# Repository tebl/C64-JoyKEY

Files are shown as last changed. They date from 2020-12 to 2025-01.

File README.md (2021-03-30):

# C64 JoyKEY
The *C64 JoyKEY* was born out of the desire to build my own joystick, and after having a look at the various options available I chose to build one using Cherry MX keyboard switches. They are around a dollar per piece, so after getting it all to work properly on my beloved Commodore 64 I looked into using it with a whole selection of vintage computer systems as well. There are two main versions of the *C64 JoyKEY*, the keyboard-variant already described and a board designed for use with Sanwa arcade parts instead.

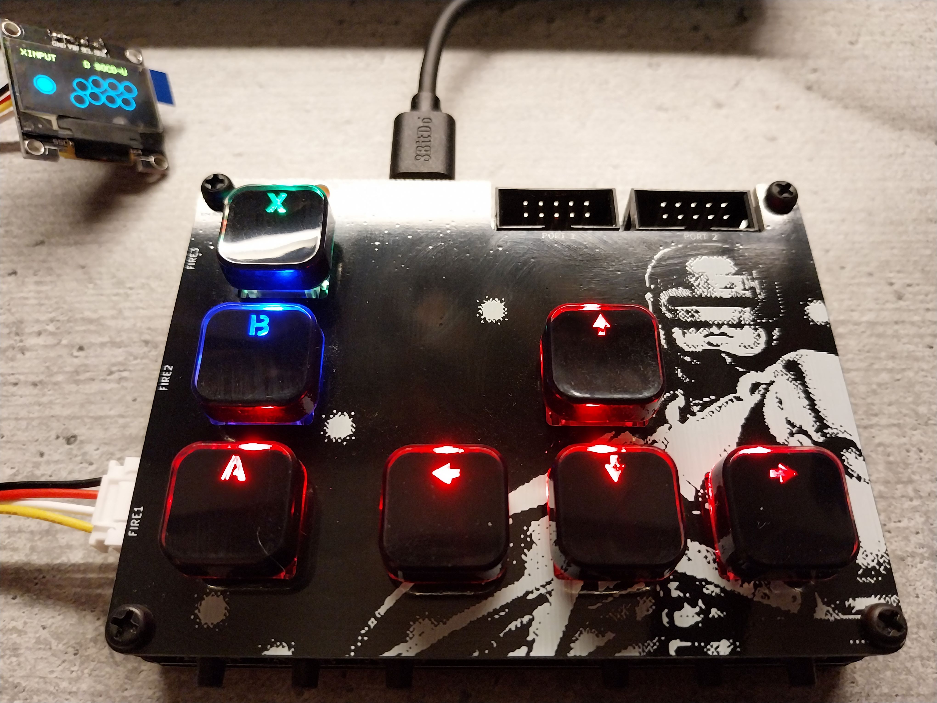
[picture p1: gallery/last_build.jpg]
Last build

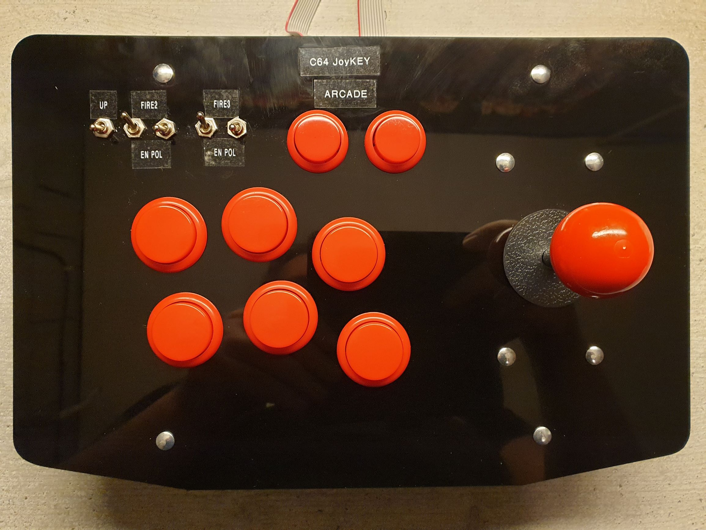
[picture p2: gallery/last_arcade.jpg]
Last arcade


With options to handle multiple types of systems comes complexity, you'll have to make a few decisions on what you want out of the *C64 JoyKEY*. Do I only want to use it as a joystick replacement on vintage systems, ideally with 2-3 fire buttons where supported? If so, then you won't need the Arduino Pro Micro.

Want to use it on a modern system as a *WASD*-style keyboard or a gamepad, then install it - a common use of these types of devices is as a macro-keyboard or a stream-deck. Note that compared to many similar solutions, the microcontroller is not required for use with any of the vintage systems - the adapters actually follow the original circuit descriptions for controllers used with the actual vintage computers. What that means is that there is truly no chance of lag added by the controller. Ever.

The pictures below show the unit when connected to my Commodore 64, including the jumper settings used with it. As I've tried to keep things as close to the standard usually associated with Atari-style joysticks, there are two joystick connectors - this is because a lot of the Commodore 64 games supported using a second joystick for specific game functions.

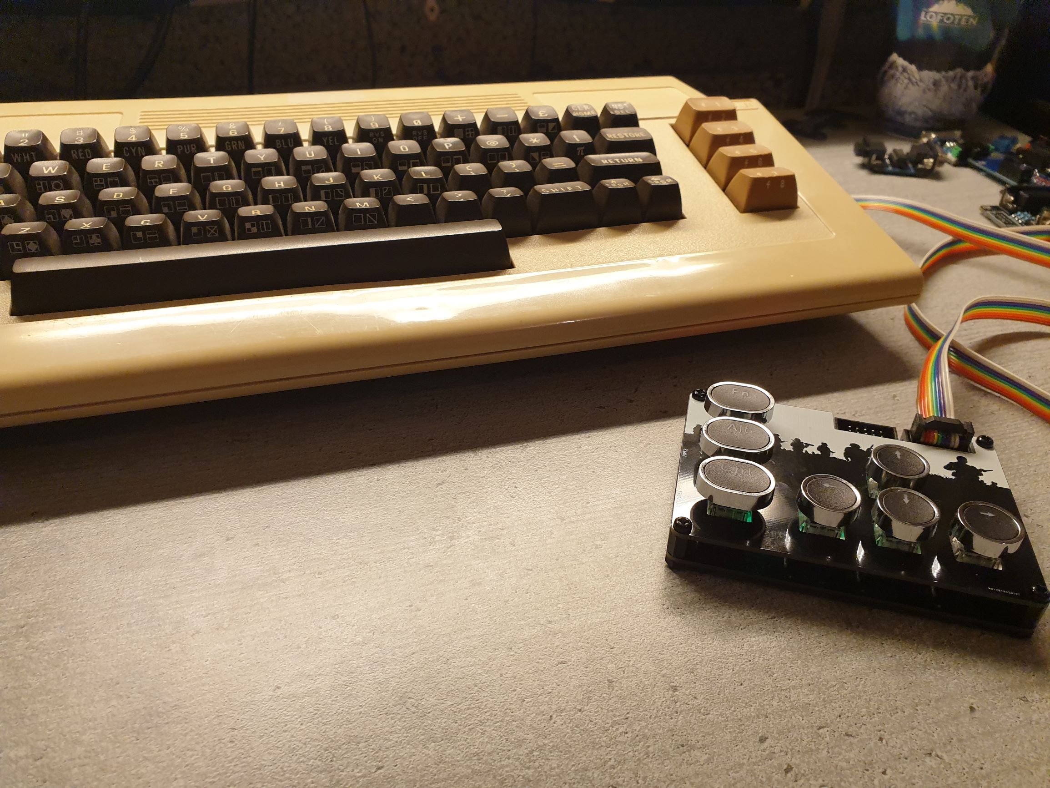
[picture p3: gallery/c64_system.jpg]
Commodore 64

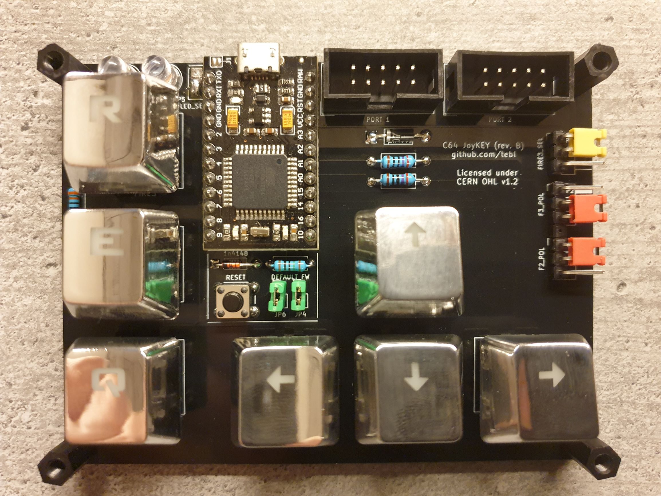
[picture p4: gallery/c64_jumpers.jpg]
C64 Configuration


As with most C64 games port 2 is the one to use, port 1 is just there to connect additional fire buttons. When in doubt, just connect a cable for port 2 and you should have a good time. This was labelled after the way the controller is used on the Commodore 64. 

## Getting one
I won't be selling these, so if you want one you will probably have to build it yourself (or call your favourite friend, ideally someone with a reasonable quality soldering iron). I've created a separate documents on [building](https://github.com/tebl/C64-JoyKEY/blob/main/documentation/building.md) a *C64 JoyKEY*, this is also where you'll find the [BOM](https://github.com/tebl/C64-JoyKEY/blob/main/documentation/building.md#bom) for this project (a list of needed parts and links to where PCBs can be ordered).

* [Building C64 JoyKEY](https://github.com/tebl/C64-JoyKEY/blob/main/documentation/building.md)
* [Building C64 JoyKEY Arcade](https://github.com/tebl/C64-JoyKEY/blob/main/documentation/building_arcade.md)
* [PCBWay shared projects](https://www.pcbway.com/project/shareproject/?tag=C64%20JoyKEY)

As with all things you're soldering together by yourself, the one who soldered it takes responsibility for it. I'll try answer any opened tickets as far as I am able, but know that this is a hobby-grade project and I might be busy on spending the little energy I have on other things (be patient, check out the [schematic](https://github.com/tebl/C64-JoyKEY/tree/main/documentation/schematic) while you wait).

## Setting it up
The *C64 JoyKEY* has a handful of jumpers that need to be set correctly in order to: A - function, B - not destroy your precious vintage computer and/or consoles. The necessary details have been put into a separate [configuration](https://github.com/tebl/C64-JoyKEY/blob/main/documentation/configuration.md)-document, check it out for some information on the systems I've attempted to use the *C64 JoyKEY* with.

* [Configuring C64 JoyKEY](https://github.com/tebl/C64-JoyKEY/blob/main/documentation/configuration.md)
* [Arduino firmware](https://github.com/tebl/C64-JoyKEY/blob/main/documentation/firmware.md)

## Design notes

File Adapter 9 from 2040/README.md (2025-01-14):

# Adapter 9 from 2040
I cant really recall the entire list of adapters that I've made of the years, but there might actually have been a few more than 9 though this is definitely the first one that I've ended up calling *Adapter 9 from 2040*. Strikingly similar in function to the [C64 Joystick Adapter](https://github.com/tebl/C64-Joystick-Adapter) that I made a while back, but given my renewed interest in the *C64 JoyKEY* via [C64 JoyKEY 2040](https://github.com/tebl/C64-JoyKEY/tree/main/C64%20Joykey%202040) it made somewhat sense to create yet another "DB-9" to USB-controller adapter.

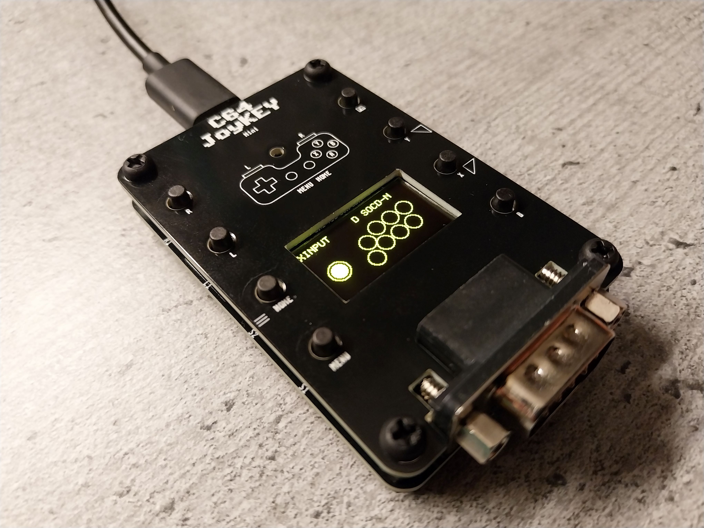
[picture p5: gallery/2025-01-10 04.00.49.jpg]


Except this time the implementation was based on [GP2040-CE](https://gp2040-ce.info), running on a Raspberry Pi Pico variant commonly referred to as the *RP2040-Zero*. At this point quite a lot of the older Arduino-libraries have hardly seen any features added to it, but as for *GP2040-CE* - if there's a feature that you can think of, then it's probably already there in some form or another. *Adapter 9 from 2040* in its most common setup presents itself to the system you connect it to as a wired *Xbox-360 Controller*, meaning that you can use it as a controller on quite a lot of different systems.

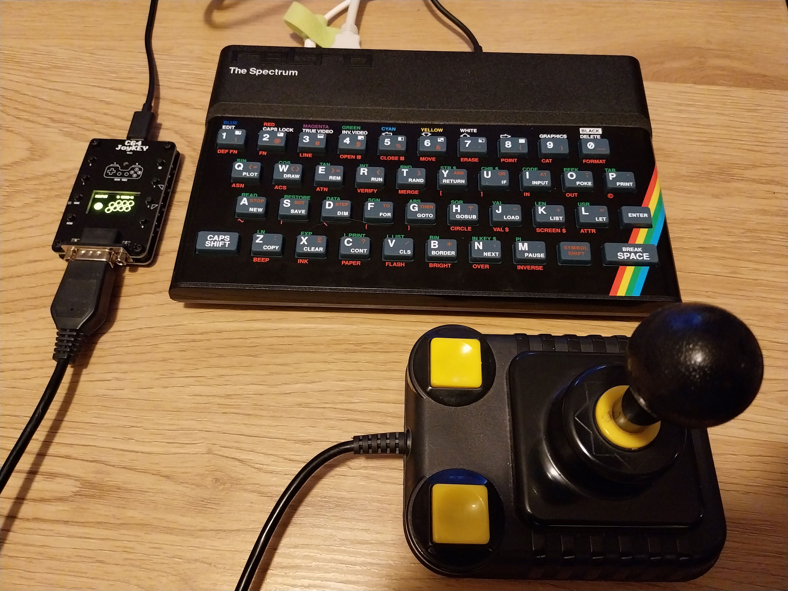
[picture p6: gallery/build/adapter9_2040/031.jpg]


Personally I wanted it for use with the various releases from *Retro Games Ltd.* - great little systems for playing games on when I want something that should just work, but absolutely terrible controllers. I've tested it with *TheC64 Mini*, *TheA500 Mini* and most recently *TheSpectrum* to great effect, and being able to use my vintage joysticks with them only adds to the enjoyment.

- [1> Building the device](#1-building-the-device)
- [2> Schematic](#2-schematic)
- [3> BOM](#3-bom)

# 1> Building the device
Building the device should be a straight-forward affair, you just solder the meager selection of components into place. Pay particular attention to keeping the alignment of parts somewhat straight, that's pretty much it. This documentation was written with a board that looks like the following in mind, but note that the GitHub-repository might contain changes that have yet to be tested. For that reason it is recommended that PCBs are ordered directly from the PCBWay links provided in the BOM).

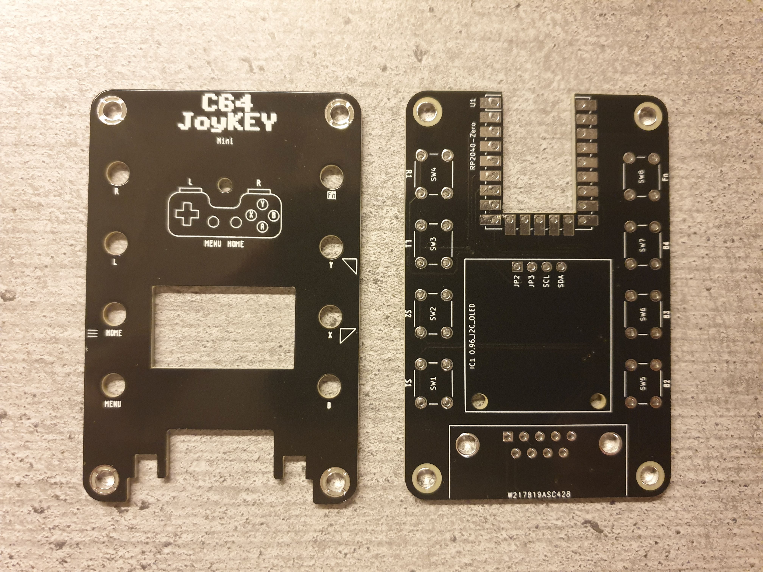
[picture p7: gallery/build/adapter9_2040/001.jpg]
Bare boards

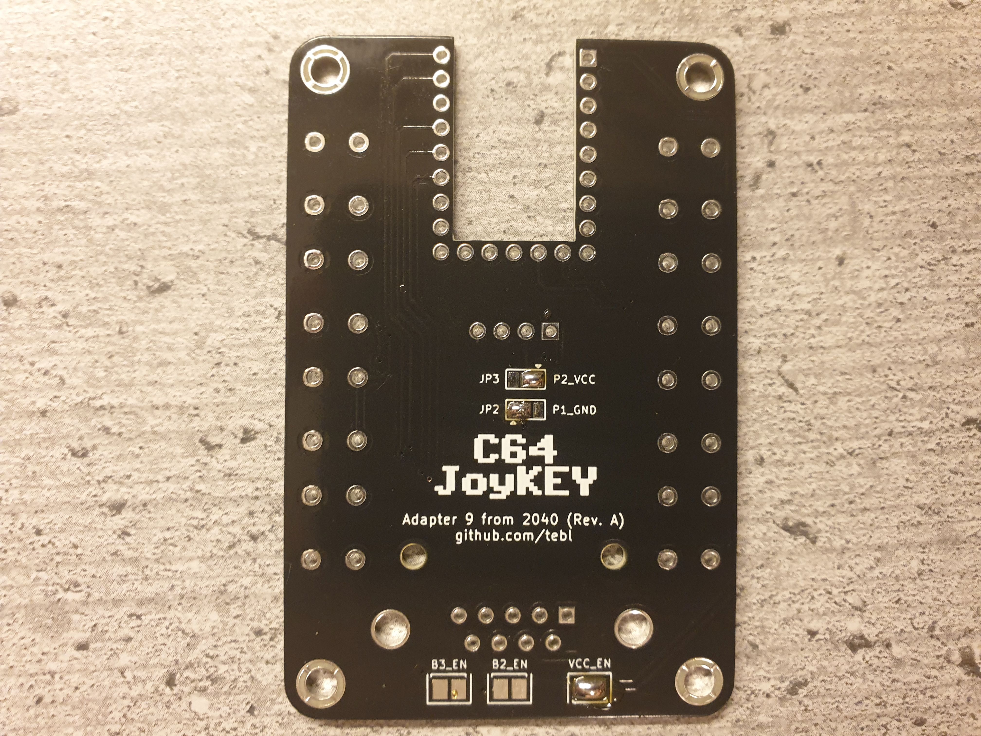
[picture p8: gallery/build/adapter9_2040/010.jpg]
Build 010


Before getting started on installing actual components there are a few things that we need to cover first, and that's setting up the various jumpers found on the back of the PCB. The ones towards the bottom covers the kind of signals we want to hook up to the "DB-9"-connector, and the only one that I recommend linking is *VCC_EN* as that will be needed for quite a few of the joysticks that include a turbo-function. Takes a little bit of practice to get these to link, but if you try and get the soldering iron to heat both pads simultaniously and keep feeding in solder you'll get a perfect blob before long.

The jumpers for *B2_EN* and *B3_EN* are for controllers that have one or two extra fire buttons with a commoned ground, but as these are quite rare I'd recommend that you leave these as they are unless you specifically know what you're doing. Or in the even rarer case, is the one where you're using either [C64 Arcade](https://github.com/tebl/C64-JoyKEY/tree/main/C64%20Arcade), [C64 JoyKEY](https://github.com/tebl/C64-JoyKEY/tree/main/C64%20Joykey) or the [C64 JoyKEY 2040](https://github.com/tebl/C64-JoyKEY/tree/main/C64%20Joykey%202040).

The one case where we really need to pay attention is the ones toward the middle of the PCB, these are needed in order to specify how your *0.96" I2C OLED*-display should be wired up. The reason is that when you're ordering these from various sources they'll send you displays that were made with differing pinouts, even more annoyingly is that often you'll look at the pictures to verify that you're getting a specific revision of it - but they'll just send you a different one. Here's what the one I've jumpered for in the above picture, note specifically that *GND* is on the first pin. That means that on both jumpers we need to link pins 1-2 together (with the tiny triangle indicating pin 1). If, on the other hand, the first pin had been labelled *VCC* (or quite possibly *VDD*) the you'd instead need to link pins 2-3 for both of the jumpers. 

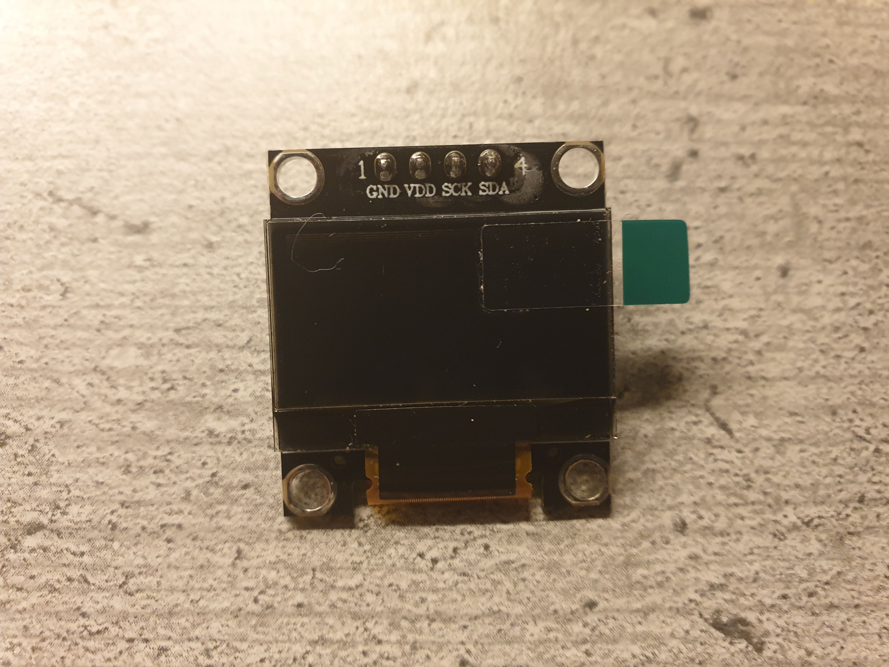
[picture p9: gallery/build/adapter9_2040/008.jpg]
Build 008

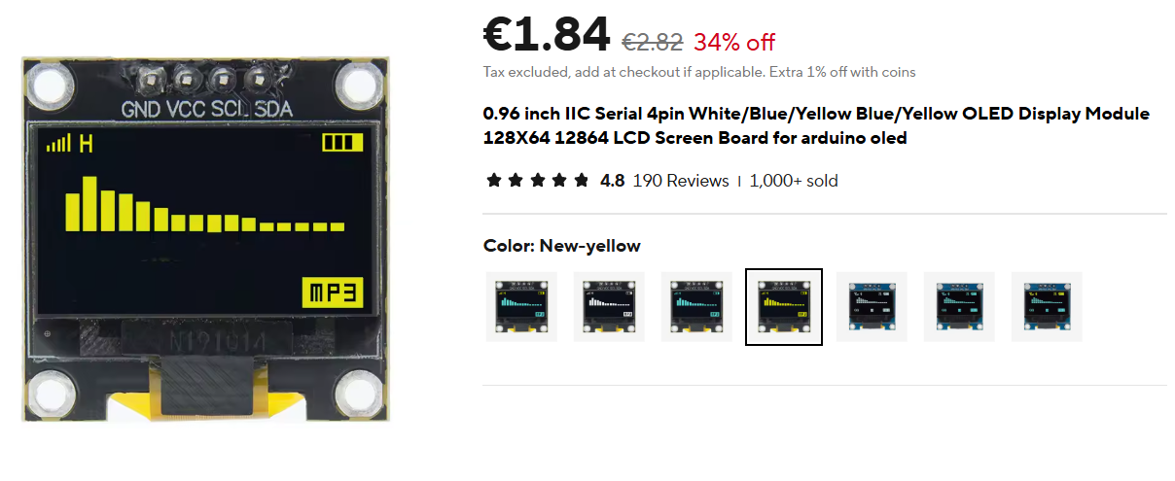
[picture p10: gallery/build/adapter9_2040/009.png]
Build 009


Moving on to actualy components that we'll be installing, I always recommend that you install things in the order of their physical height. There's not all that much that can go wrong beyond making things harder for yourself to put this one together so don't overthink things. You will however need to decide if you'll be installing the *RP2040-Zero* development board directly to the board, or with pins between the two. Before all that though, we need to talk about what a *RP2040-Zero* actually is. And here's a couple of them that you might encounter while shopping around: 

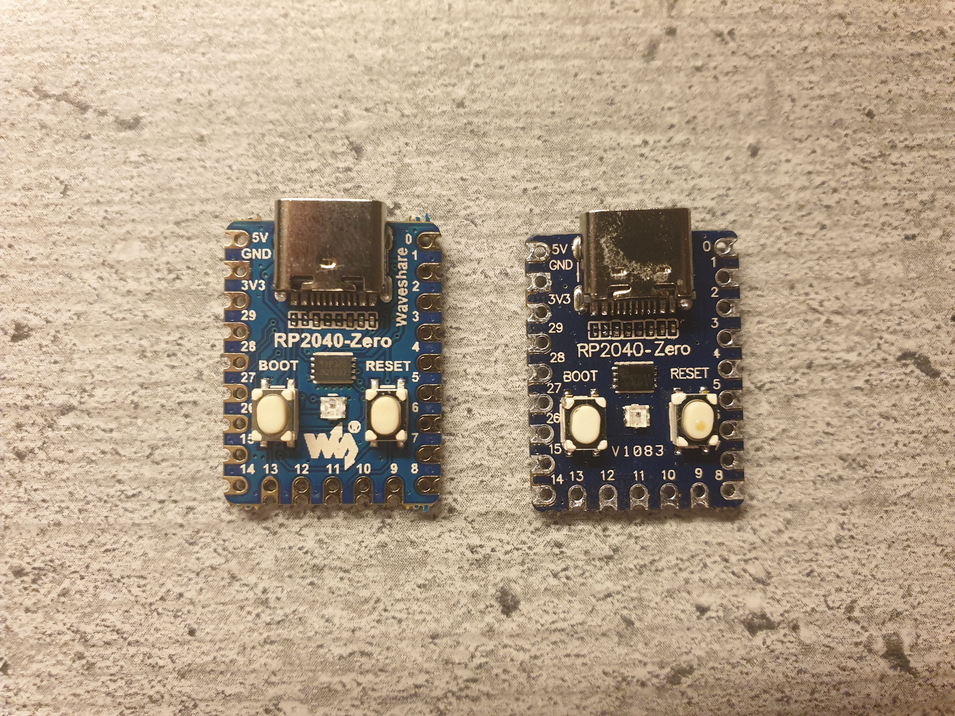
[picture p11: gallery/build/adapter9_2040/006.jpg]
RP2040-Zero development boards


Both of these are smaller versions of the *Raspberry Pi Pico* boards that come directly from the *Raspberry Pi Foundation*, but they're running the same chip so you essentially get the same amount of computational power - just with slightly less pins, and in a significantly smaller package. Confusingly this isn't a *Raspberry Pi* as the single-board computers (*SBC*) that came before it, this is a somewhat new line of microcontrollers similar to the *Arduino* or *ESP-32*. As for the boards above, the first one is from a vendor called *Waveshare* and this is the version that you'll encounter on more reputed sites for purchasing electrical components. The other is a clone that normally works just as well, just at half the price and without any expectation that all of were put together like they should - so buy at least two of them in case one blows up!

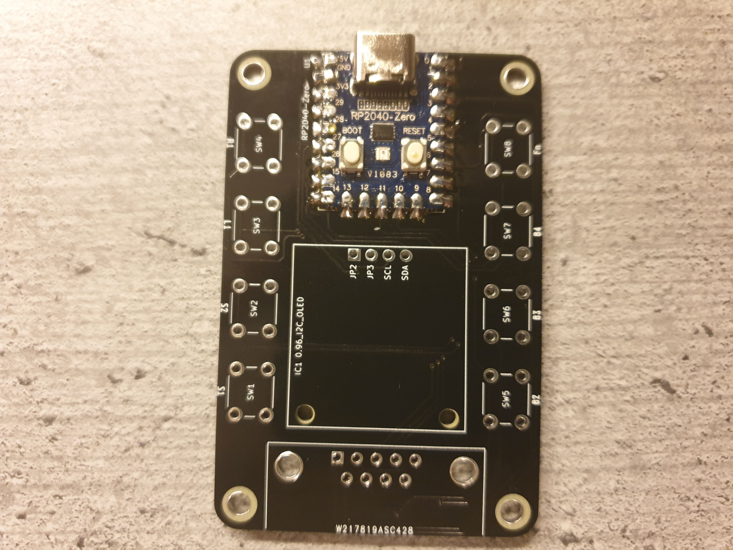
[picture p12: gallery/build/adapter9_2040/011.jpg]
Build 011


Here I've skipped over the difficult parts and soldered it into place. In order to get the alignment just right I tend to insert pin headers through both boards on at least two of the sides, then position it just right and solder one pin into place. If it all looks right, you can go ahead and remove the pin headers before soldering the rest. It might take some getting used to soldering things together like this if you're not used to it, but just try and get the soldering iron to touch both pads at the same time then feed in the solder until it forms a shiny avalanche.

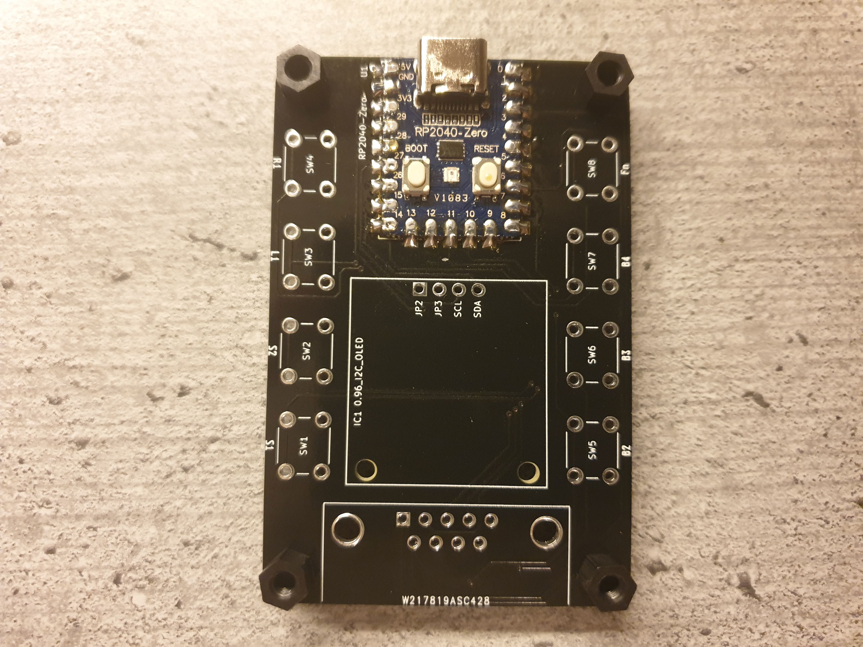
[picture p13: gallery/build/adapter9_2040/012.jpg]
Build 012


If you're going to install a faceplate on the adapter, then you're going to need a set of standoffs in each of the four corners. These need to have a height of 6mm, they're fixed in place with similar nuts on the underside. You might also use some that are slightly longer, but keep in mind that we need to have enough of a reach on the pin headers on your OLED to match - switches also need to be tall enough to poke through all of it. On second thought, just go with 6mm and we'll move on from there.

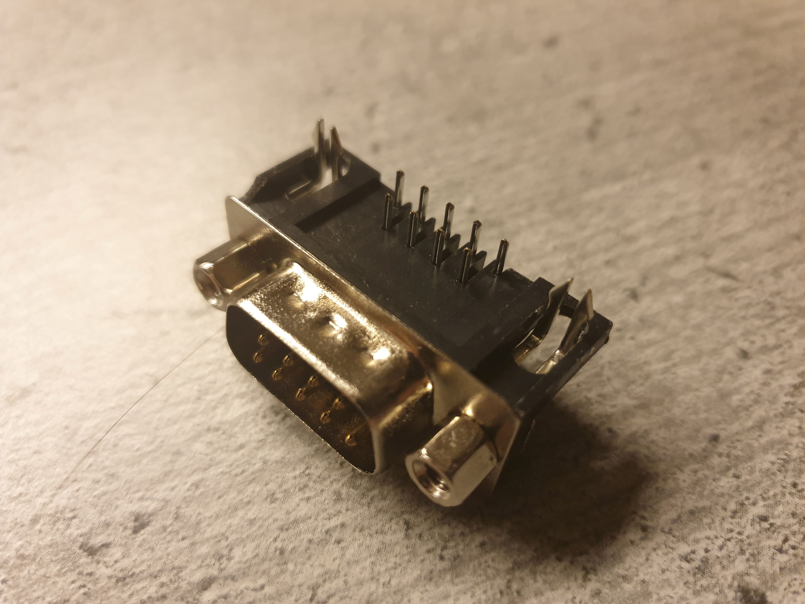
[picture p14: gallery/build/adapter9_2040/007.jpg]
Build 007

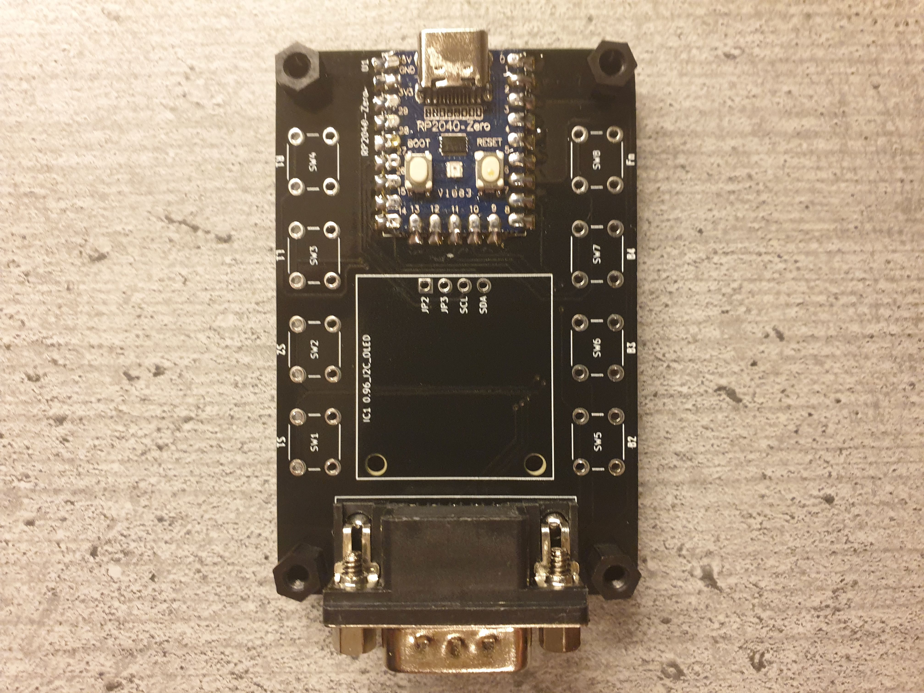
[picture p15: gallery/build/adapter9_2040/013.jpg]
Build 013


Next up is the *right-angle "DB-9" male connector* that I keep buying off of the regular sites, and I believe it's a clone of an RND-part, but don't hold me to that. If you look for the a connector that looks like this on the pictures, then you'll get the correct one. It snaps into place on the board and solders in well enough, just keep your fingers away from the metal as it heats up quite quickly when soldering. I've literally burned myself on them several times. And at the time of writing, this is probably the first time I've used the word "literally" correctly. I hope. 

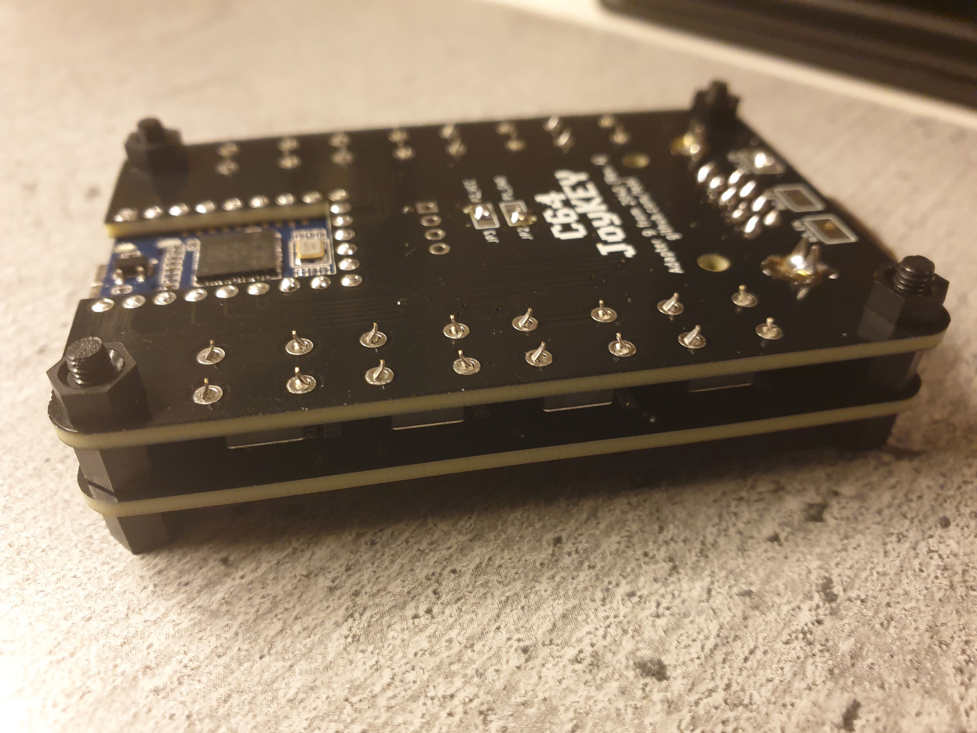
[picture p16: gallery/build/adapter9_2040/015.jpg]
Build 015

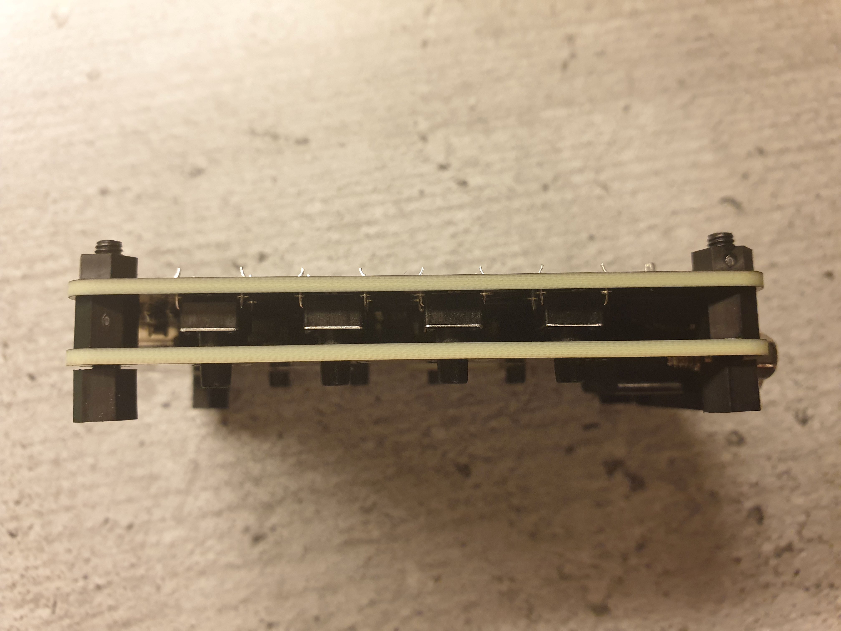
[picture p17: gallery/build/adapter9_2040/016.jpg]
Build 016


The next step is all of the switches, and here I've inserted them all into place and temporarily installed the faceplate. Doing it in this order ensures that the switch ends up sitting correctly, and won't be rubbing too much against the cutouts in the faceplate. Once satisfied with all of that, you can go ahead and solder in the switches. Just do one of the pins at first, then recheck to make sure it hasn't popped out or gone wonky on you in the meantime (ask me how I know).

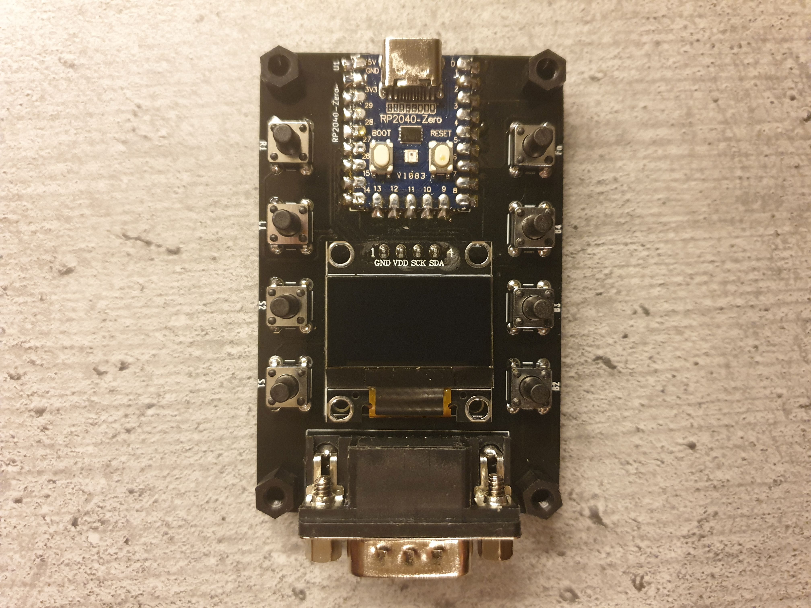
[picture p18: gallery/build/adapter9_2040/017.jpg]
Build 017


As for my next trick on my list of things I've just done without much to actually show you, I've gone ahead and added the display. Previously on this episode of putting things together with our fiery stick of endless ouchies (also known as a soldering iron), we lamented the state lack of real part numbers for things like displays. Clones taking liberties when shamelessly copying other clones, enabling people like me to actually own a whole bunch of them and so on. The board will take just about any *0.96" I2C OLED*-display, but you'll need to ensure that you order specific ones if you want the cutouts on the faceplates to line up just perfectly. Currently there is only one available, [FaceplateB](https://github.com/tebl/C64-JoyKEY/tree/main/faceplates/Adapter%209%20FaceplateB) - this one was designed for the *New* displays available in all the usual places. Technically it's actually the new *New* display, but who's counting - at least one identifying trait is that they're the first generation that came with yellow as colour.

There are holes for orienting it correctly, but before even considering soldering anything - take a look at how it looks with the faceplate in place. We need to ensure that it sits flush against the inside edge of the faceplate, and while you could glue the foam that often comes around the pins directly to the PCB to push it upwards - I prefer adding a bunch of layers of double-sided foam tape. Just don't go overboard -  we want it to push the glass up against the PCB, not shatter the whole thing from extreme pressure. If you need to reorient it a bit, you can poke a screwdriver into the mounting holes from the back and adjust it that way. Once satisfied with your rough placement, solder a single pin. Recheck. Recheck. Recheck. And then solder the rest.

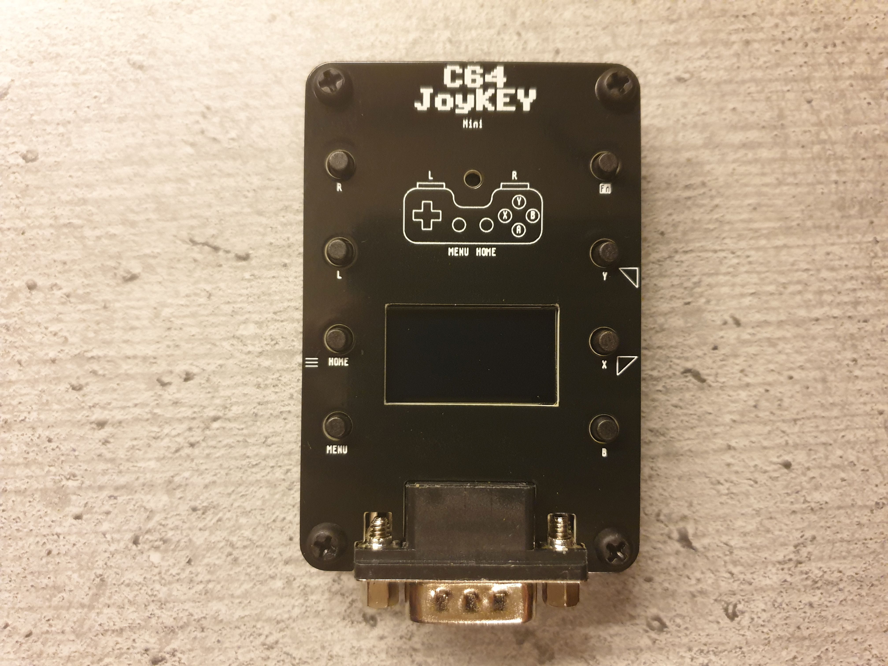
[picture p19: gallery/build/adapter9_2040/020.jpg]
Build 020


Once satisfied with all of it, make yourself a cup of tea, soup or whatever you want - you're buying anyway! Once back to the table, you need to take the faceplate back off again, as we need access to the buttons directly on the *RP2040-Zero* when installing *GP2040-CE*, but that's all covered in a completely different document - [From Zero to GP2040](https://github.com/tebl/C64-JoyKEY/blob/main/documentation/gp2040_zero.md).

# 2> Schematic
The supplied KiCad files should be sufficient as both a schematic and as a  starting point for ordering PCBs (basically you could just zip the contents of the export folder and upload that on a fabrication site), the schematic is also available in [PDF-format](https://github.com/tebl/C64-JoyKEY/tree/main/documentation/schematic) and this is what you'll need to print and work your way through when things fail to work as expected.

# 3> BOM
Most parts should be easy to get a hold of from all of the regular places, just not any of the incredibly reputable ones. Which is why things usually cost a third of what they cost elsewhere, but you need to buy two in order to ensure that at least one works. I get most of my components from AliExpress though I hear nice things about the wheel of fortune thingie, but they sent one too many notifications so they're banned in my household.

I'd really like for you to have a nice and clear BOM with consistent part numbers from actual reputable sites, but I can't even afford their shipping options so it is what it is - mostly hints at what to search for and how many you need. If a counted part is listed in a parenthesis, then you don't strictly need that part though it's all cheap enough that you probably count on buying them anyway.

| Reference | Item | Count | Order  |
| ---| --- | ----- | --- |
| PCB | Fabricate using Gerber files | 1 | [PCBWay](https://www.pcbway.com/project/shareproject/Adapter_9_from_2040_578739f8.html)
| PCB (Faceplate B)| Fabricate using Gerber files | (1)| [PCBWay](https://www.pcbway.com/project/shareproject/Adapter_9_from_2040_Faceplate_B_dc748e4f.html)
| IC1 * | 0.96" I2C OLED display 128x64 (New variant reqd. for FaceplateB)) | (1)|
| J1 | Male DB-9 right-angle connector (usually listed as PCB-mount) | 1 |
| SW1-SW8 | 6x6x10mm tactile switch ("DIP-4") | (8)|
| U1 | Raspberry Pi Pico (RP2040-Zero) | 1 |
| ** | M3 nylon nut | (4)|
| ** | M3x6+6mm nylon hex standoff | (4)|
| ** | M3x6mm nylon screw | (4)|

*) See text for construction for hints on purchasing the correct variant to go with a specific faceplate, when in doubt order several and use the one that fits.

**) These components are for the additional faceplate. Strictly not necessary, but keeps the  whole setup looking as stylish as it can be. The faceplate is reversible, so install it in the orientation that you'd like.

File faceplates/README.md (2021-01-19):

# Faceplates
The *C64 JoyKEY* will have a selection of faceplates, these are primarily just here to make the device a bit prettier by hiding the actual electronics. Secondly it adds some rigidity to the design, quite possibly making it less likely to fail after heavy use.

These generally come in two different variations, A and B with a number added to separate the various designs. The A version has a larger PCB cutout that should allow you to use most of Cherry MX-compatible keycaps of the kind that descends down past the actual switch (low/medium profile), if you're in doubt this is the version to get. The B designs have a smaller cutout, but requires the use of keycaps that don't descend so far down (high profile).

See the [faceplates](https://github.com/tebl/C64-JoyKEY/blob/main/documentation/faceplates.md) section of documentation for more information.

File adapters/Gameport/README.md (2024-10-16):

# Gameport

*UNTESTED*

While the IBM PC has seen its fair share of joysticks over time, they were primarily analog though the digital variety have also been regularly seen since the early 1980s as well. The rise of competing gaming consoles soon started to popularize the gamepads over the analog controllers and soon, even the PC saw their share of excellent controllers such as the Gravis Gamepad. While they won't replace the feel and response of an analog flightstick for those type of games, I feel that there are enough variety that the digital controllers also should have their place on the system - for that system I've created a separate Gameport-adapter for the *C64 JoyKEY*. Granted it won't make all that much sense connecting a keyboard-like controller to a computer with a great keyboard, but the ability to use the *C64 JoyKEY Arcade* with it should present as an excellent combination.

The circuit was adapted from the one listed on [asun.net](http://www.asun.net/joystick/joystick.html). Additional information was also listed in a separate [article](https://allpinouts.org/pinouts/connectors/input_device/joystick-pc-gameport/) as well, and could be interesting when working out how the adapter works.

PC Gameport Adapter
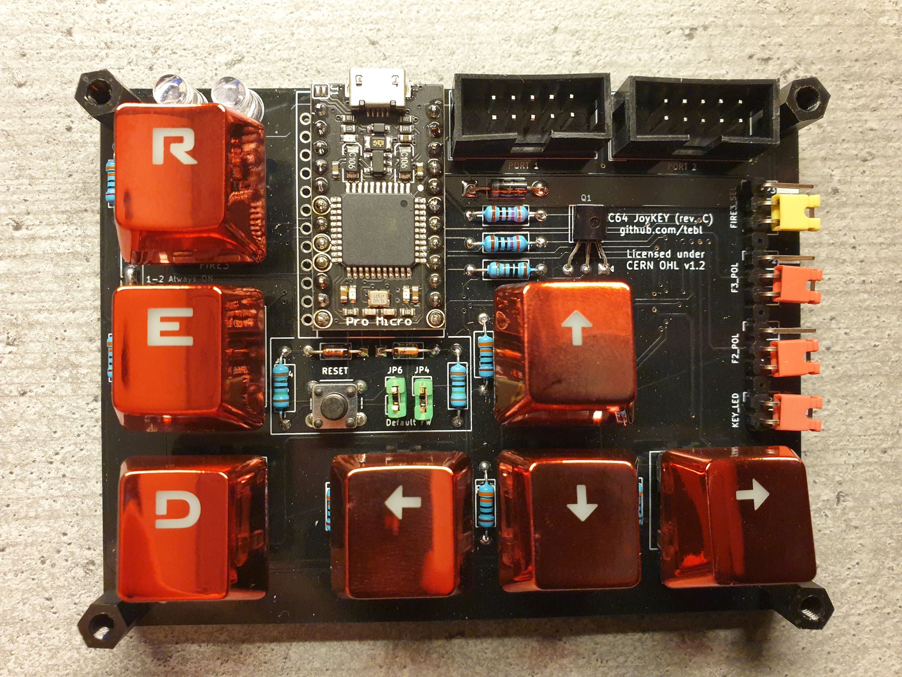
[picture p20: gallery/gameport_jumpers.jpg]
PC Gameport Jumpers


# BOM
The parts listed are the ones I've used when building a MSX adapter for use with the *C64 JoyKEY*, part listed in parenthesis are considered optional (meaning you could build a more limited version of it). 

| Reference | Item | Count | Order |
| --- | --- | ----- | --- |
| PCB | Fabricate using Gerber files | (1)| PCBway
| D1,D2 | 1n4148 small-signal diode (DO-35) | 2 |
| J1,J2 *1 | 2x5 pin straight header pins or 2x5 IDC | 2 |
| J3 *2 | 2x8 pin straight header pins or 2x8 IDC | 1 |
| Q1,Q2 *3 | 2n3906 transistor (TO-92) | 2 |
| R5,R6 | 47k ohm resistor | 2 |
| R1-R4,R7,R8 | 100k ohm resistor | 6 |

1) Breakable dual row pin headers can be used here, but I find it is nicer to have a proper 2x5-pin keyed connector here instead. The cable you will need is a 2x5 pin IDC cable (usually listed as *AVR* or *JTAG* cable), with sufficient length to position where you would like - ideally you will want two of these, but you can make due with one connected to port 1.
2) As with above, 2x8-pin IDC header is recommended. For the cable you will want a 16-pin IDC to a male DB15-ribbon cable - you can buy these ready made from the usual sources. If you can't find one that you like, I recommend picking up 16-pin IDC cables of intended length and then put on a male IDC DB15-connector. While there are special tools created to crimp these on, I find that just pushing hard on them with the handle of a screwdriver works just as well for a single cable.
3) I have not tested this, but I suspect that replacing these with 2n3906 installed backwards may work just as well.

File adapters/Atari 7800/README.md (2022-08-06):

# JoyKEY (Atari 7800)

In the age of the Commmodore 64, Atari decided that it was a good idea to put together a console without audio quality that would only rise to the level of competing with the almighty ZX Spectrum. Then they launched them with horrible controllers that fell part on the way home from the store. Here in Europe, we also got treated to a gamepad-like controller that can only be described as an implement created by someone who only have had the concept just barely described to them over the phone - yet, we still got the feeling that that someone did not see the point of spending more than 5 minutes on games.

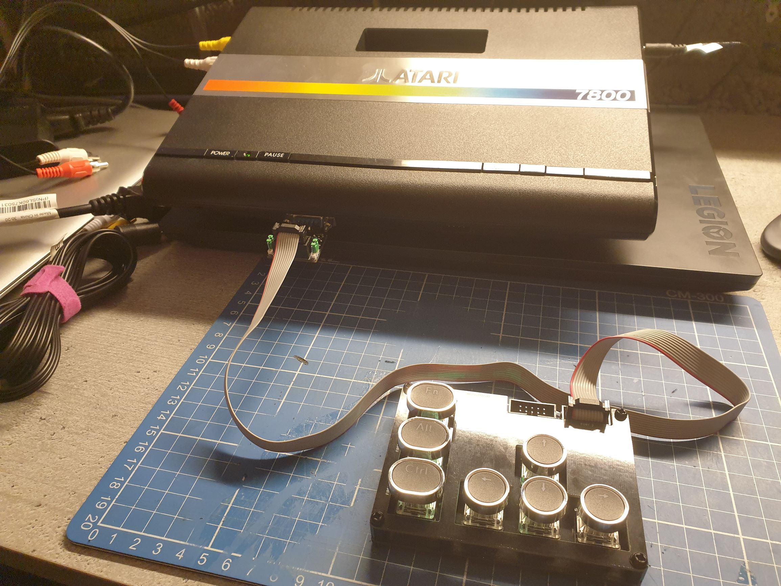
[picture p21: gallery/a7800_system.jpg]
Atari 7800 Pro System


Enough about all that, I actually have more than one of the consoles - somehow I sort of like playing on them, I just can't use any of their controllers. I've previously made an adapter so that I can use Sega Mega Drive controllers with the console, but since I've built the *C64 JoyKEY* I wanted to use it on that as well (which is the reason for this adapter).

The completed adapter can be seen below, this also includes the expected position that should be set on the *C64 JoyKEY* device itself.

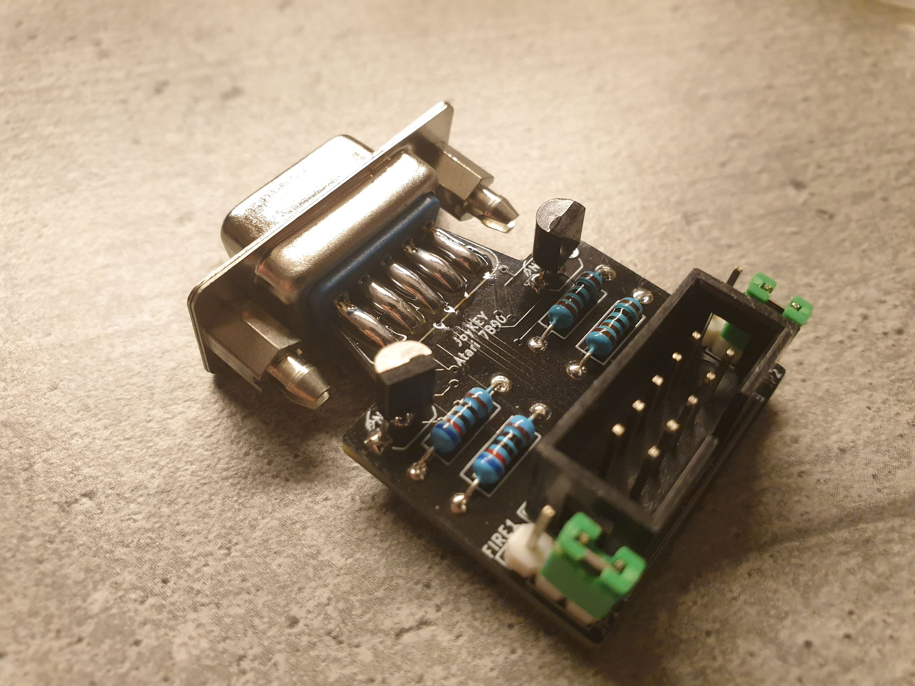
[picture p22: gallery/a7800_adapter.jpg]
Atari 7800 Adapter

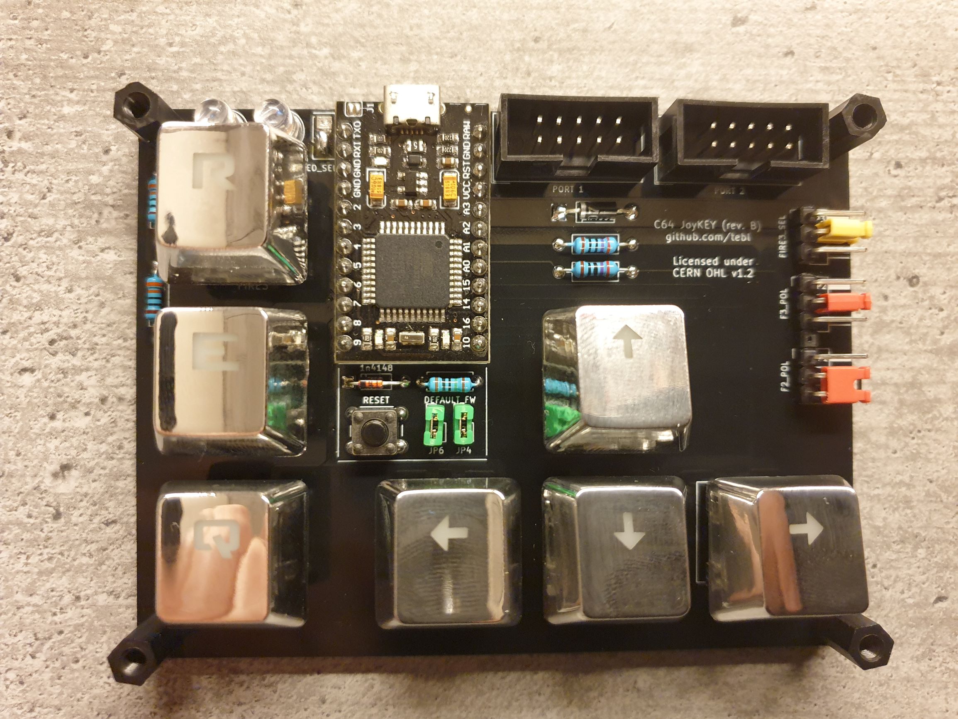
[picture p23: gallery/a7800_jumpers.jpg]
Atari 7800 Jumpers


# BOM
The parts listed are the ones I've used when building an Atari 7800 controller adapter for the *C64 JoyKEY*, part listed in parenthesis are considered optional (meaning you could build a more limited version of it). 

| Reference | Item | Count | Order |
| --- | --- | ----- | --- |
| PCB | Fabricate using Gerber files | (1)| [PCBway](https://www.pcbway.com/project/shareproject/C64_JoyKEY__Atari_7800_adapter_.html)
| J1 * | 2x5 pin straight header pins or 2x5 IDC | 1 |
| J2 ** | DE-9 Female straight connector | 1 |
| JP1,JP2 *** | 3-pin breakable header pins (w/jumpers | (2)|
| Q1,Q2 | 2N3906 transistor (TO-92) | 2 |
| R1,R3 | 620 ohm resistor | 2 |
| R2,R4 | 1k ohm resistor | 2 |

*) Breakable dual row pin headers can be used here, but I find it is nicer to use a 2x5 pin connector here instead. The cable needed is a 2x5 pin IDC cable (usually listed as *AVR* or *JTAG* cable) with sufficient length.

**) These are the blue kind with straight pins, it will include a few metal bits on it - remove those and you'll be left with the mostly blue part needed. Bend the pins slightly and match up with PCB, solder before it has a chance to fall off.

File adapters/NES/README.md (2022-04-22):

# JoyKEY (Nintendo Entertainment System)
The Nintendo Entertainment System, commonly known as just the *NES* came with a four button controller (*B*, *A*, *SELECT* and *START*). A picture of the completed adapter has been included below, including the jumper position that you need to use on the *C64 JoyKEY* device itself.  For the later revisions of the *C64 JoyKEY* you'll have a row of buttons on the bottom left of the device, these are ideal for using as the  *SELECT* and *START* - for earlier revisions you'd install a physical *START*-button on the adapter itself.

Making the adapter requires a cable with the right shape, Nintendo wanted these to be explicitly proprietary so you can't exactly order one from electronic parts vendors though obtaining one isn't exactly hard. The simplest way of obtaining the plug today is either cutting up cheap NES controller extension cable, alternatively you could just purchase one of the rather horrible cloned controllers and cut it off from that instead. Both of these options should be readily available from your favourite off-brand marketplace for all things "*Made in China*", AliExpress, Ebay, Wish and most similar sites.

With the cut-off cable in hand, the individual strands of the cable can then be soldered to the adapter PCB. The pins are numbered left to right, match up the individual strands to the pin numbering as shown in the [schematic](https://github.com/tebl/C64-JoyKEY/blob/main/documentation/schematic/adapters/NES.pdf). Ideally I'd like to just tell you where to connect them based on the colour, but with the cost of these things I wouldn't expect them to be identical across all of them - so just use your multimeter in order to identify what goes where on the connector.

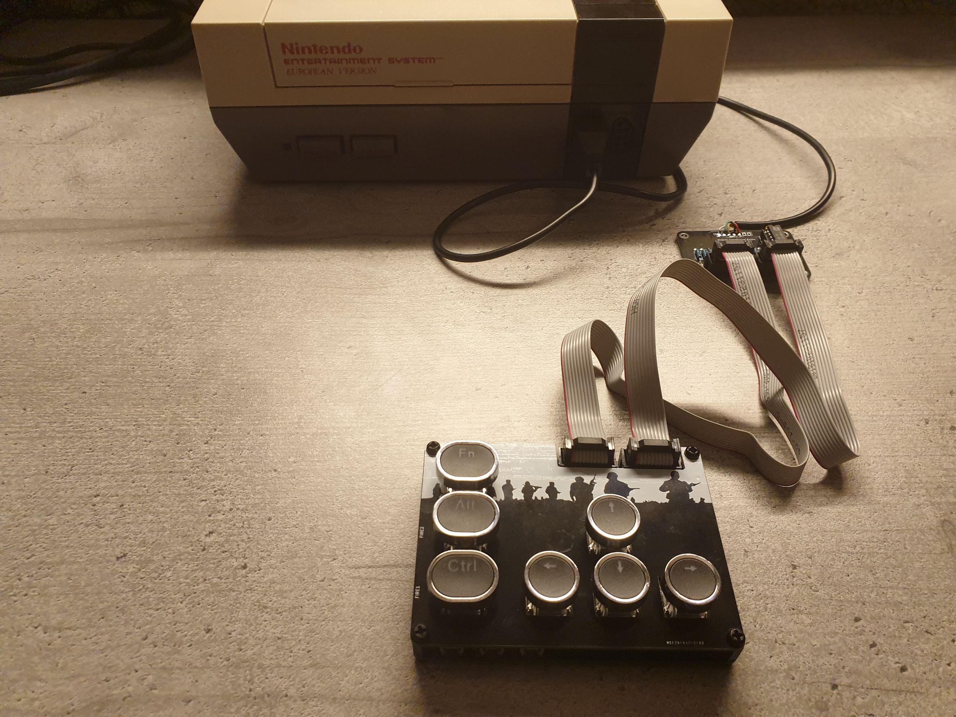
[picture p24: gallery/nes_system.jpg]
Nintendo Entertainment System

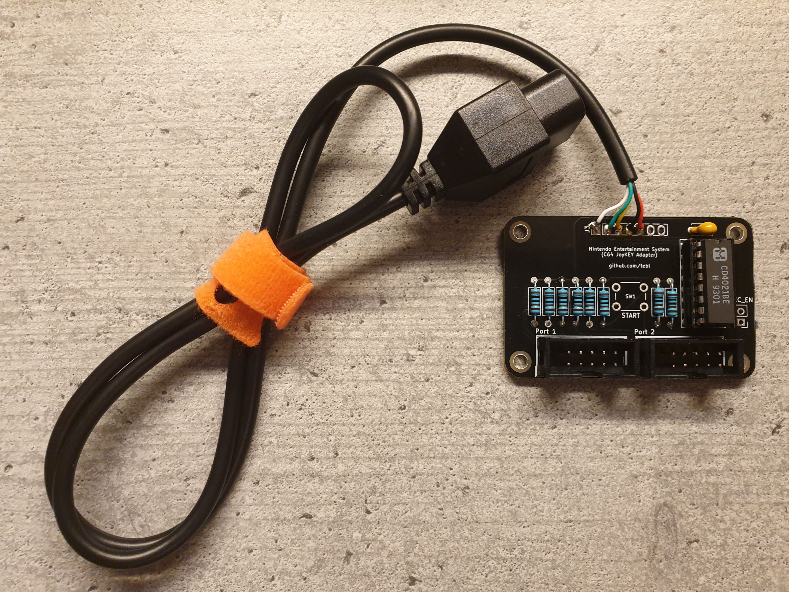
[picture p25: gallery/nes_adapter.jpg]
Nintendo Entertainment System Adapter

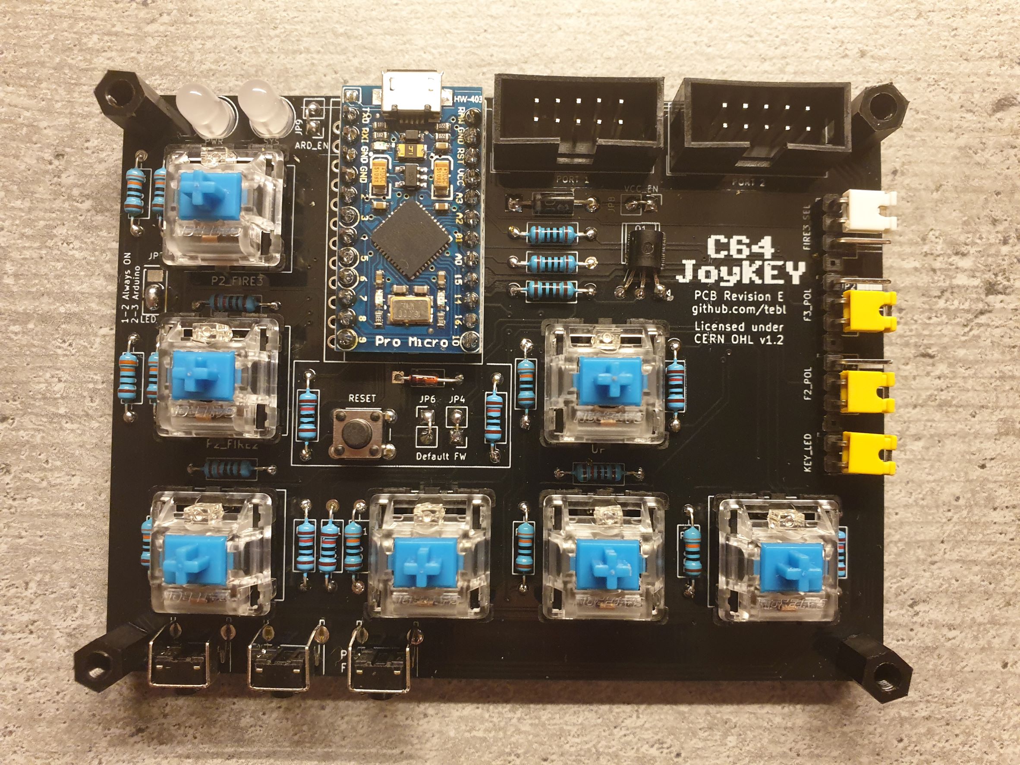
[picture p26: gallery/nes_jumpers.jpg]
Nintendo Entertainment System Jumpers


# BOM
The parts listed are the ones I've used when building a Nintendo Entertainment System controller adapter for the *C64 JoyKEY*, part listed in parenthesis are considered optional (meaning you could build a more limited version of it).

| Reference | Item | Count | Order  |
| --- | --- | ----- | --- |
| PCB | Fabricate using Gerber files | 1 | [PCBWay](https://www.pcbway.com/project/shareproject/C64_JoyKEY_NES_adapter_74ada4a5.html)
| J1,J2 * | 2x5 pin straight header pins or 2x5 IDC | 2 |
| J3 | Male end of NES extension cable | 1 |
| JP1 | 2-pin breakable header pins (w/jumpers) | (1)|
| R1-R8 | 1k ohm resistor | 9 | 
| SW1 ** | 6x6mm momentary tactile switch | (1)|
| U1 | CD4021BE (DIP-16) | 1 |

*) Breakable dual row pin headers can be used here, but I find it is nicer to use a 2x5 pin connector here instead. The cable needed is a 2x5 pin IDC cable (usually listed as *AVR* or *JTAG* cable) with sufficient length, these are used with all adapters.

**) This switch is only required using an earlier revision of the *C64 JoyKEY*, the three extra switches were added in revision E.

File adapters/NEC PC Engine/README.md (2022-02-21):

# JoyKEY (NEC PC Engine)

**UNTESTED**

The NEC PC Engine, primarily found in the japanese markets as well as everywhere fans of the shoot em up genre could be found, had several revisions and third party controllers though most stuck with the regular four button configuration (*I*, *II*, *RUN* and *SELECT*). A picture of the completed adapter has been included below, including the jumpers needed on the *C64 JoyKEY* device itself. Making on requires a cable with the right shape, the simplest way of obtaining these is either cutting up a cheap extension cables.

NEC PC Engine System
NEC PC Engine Adapter
NEC PC Engine Jumpers

# BOM
The parts listed are the ones I've used when building a Nintendo Entertainment System controller adapter for the *C64 JoyKEY*, part listed in parenthesis are considered optional (meaning you could build a more limited version of it).

| Reference | Item | Count | Order  |
| --- | --- | ----- | --- |
| PCB | Fabricate using Gerber files | 1 | PCBway
| C1 | 100nF ceramic capacitor (5mm) | 1 |
| C3 | 10uF electrolytic capacitor 16v (4x2mm) | 1 |
| J1,J2 * | 2x5 pin straight header pins or 2x5 IDC | 2 |
| J3 | 8 pin mini DIN with cable | 1 |
| JP1 | 2-pin breakable header pins (w/jumpers) | (1)|
| R1-R10 | 47k ohm resistor | 10 | 
| R11-R14 | 330 ohm resistor | 4 | 
| U1 | 74HC157 (DIP-16) | 1 |

*) Breakable dual row pin headers can be used here, but I find it is nicer to use a 2x5 pin connector here instead. The cable needed is a 2x5 pin IDC cable (usually listed as *AVR* or *JTAG* cable) with sufficient length, these are used with all adapters.

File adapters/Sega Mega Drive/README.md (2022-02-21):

# JoyKEY (Sega Mega Drive)

The Sega Mega Drive, released as the Sega Genesis in North America, originally came with a what is now known as the 3-button controller though it actually had the *START* button as a fourth button as well. While it was designed to be backwards compatible with the Sega Master System, it had a few tricks up its sleeve by adding a digital multiplexer chip that would read out the buttons over a few wires instead of having dedicated wires for each button (like previous Atari-style pinouts). There was also a 6-button controller released later, but for now I've chosen to instead focus on the 3-button controller instead - simply because we only have 3 buttons on the *C64 JoyKEY* (the *START* button has been placed on the actual adapter instead).

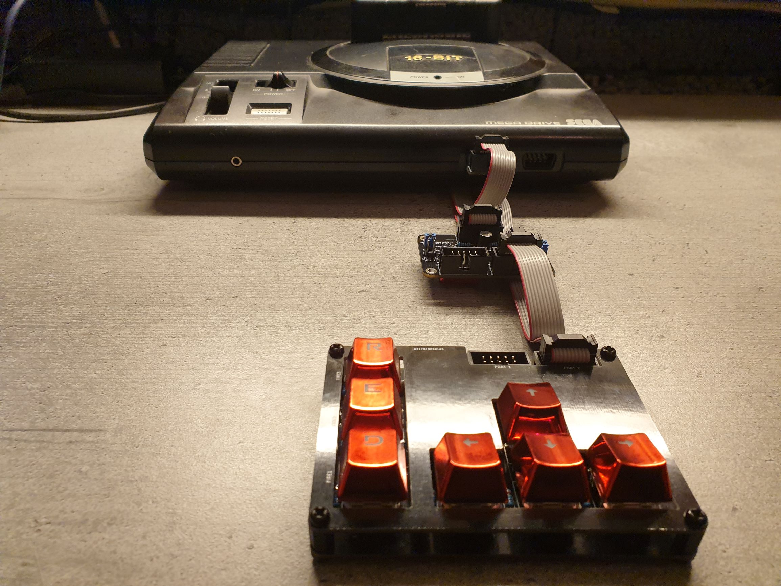
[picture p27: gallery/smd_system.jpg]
Sega Mega Drive


The completed adapter can be seen below, this also includes the jumpers that should be set on the *C64 JoyKEY* device itself. Note that because of the recessed controller ports on the actual console, a larger connector such as the DB9 IDC variety will not fit into the console - I've solved that by using a straight [IDC to DB9](https://github.com/tebl/C64-JoyKEY/tree/main/adapters/IDC%20to%20DB9) adapter as well.

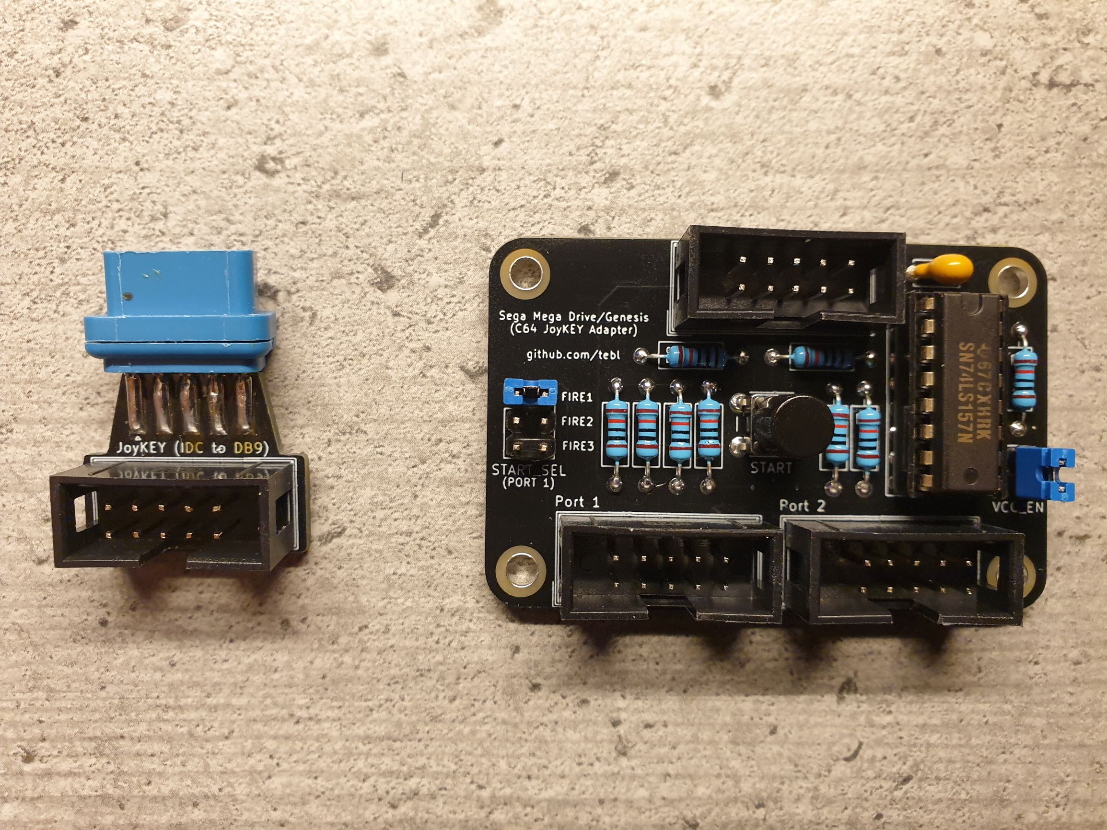
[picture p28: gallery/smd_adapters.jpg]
Sega Mega Drive Adapter

Sega Mega Drive Jumpers

# BOM
The parts listed are the ones I've used when building a Sega Mega Drive controller adapter for the *C64 JoyKEY*, part listed in parenthesis are considered optional (meaning you could build a more limited version of it). Additionally, check out the BOM on the [IDC to DB9](https://github.com/tebl/C64-JoyKEY/tree/main/adapters/IDC%20to%20DB9) page - if you don't already have on of these ready to go.

| Reference | Item | Count | Order  |
| --- | --- | ----- | --- |
| PCB | Fabricate using Gerber files | (1)| [PCBway](https://www.pcbway.com/project/shareproject/C64_JoyKEY__Sega_Mega_Drive_Genesis_adapter_.html)
| C1 | 100nF ceramic capacitor (5mm) | 1 |
| J1 * | 2x5 pin straight header pins or 2x5 IDC | (1)|
| J2,J3 * | 2x5 pin straight header pins or 2x5 IDC | 2 |
| J4 | 3-pin dual row breakable pin headers | (1)|
| JP1 | 2-pin breakable header pins (w/jumpers) | (1)|
| R1-R9 | 10k ohm resistor | 9 | 
| SW1 | 6x6mm momentary tactile switch | 1 |

*) Breakable dual row pin headers can be used here, but I find it is nicer to use a 2x5 pin connector here instead. The cable needed is a 2x5 pin IDC cable (usually listed as *AVR* or *JTAG* cable) with sufficient length.

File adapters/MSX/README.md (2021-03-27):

# JoyKEY (MSX)

**UNTESTED**

The MSX-line of computers generally tried to be everything for everyone, as long as they wanted an 8bit computers. This meant a lot of different features going into it, including the surprisingly complicated joystick ports - designed to fit just about any device as long as it conformed to their very specific standard. Which means that it works with the standard Atari-style joystick, but if you want a second fire button or something that'd work reliable for joysticks requiring power you'll need an adapter in between. I was tempted to make this a more general adapter, but I couldn't point you to a specific joystick that'd work with it - unless you build it yourself, of course.

MSX System Adapter
MSX System Jumpers

# BOM
The parts listed are the ones I've used when building a MSX adapter for use with the *C64 JoyKEY*, part listed in parenthesis are considered optional (meaning you could build a more limited version of it). 

| Reference | Item | Count | Order |
| --- | --- | ----- | --- |
| PCB | Fabricate using Gerber files | (1)| PCBway
| J1 * | 2x5 pin straight header pins or 2x5 IDC | 1 |
| J2 ** | DE-9 Female straight connector | 1 |

*) Breakable dual row pin headers can be used here, but I find it is nicer to use a 2x5 pin connector here instead. The cable needed is a 2x5 pin IDC cable (usually listed as *AVR* or *JTAG* cable) with sufficient length.

**) These are the blue kind with straight pins, it will include a few metal bits on it - you'll need to do a test-fitting on your particular build of the MSX to determine if it can be left in place. If it feels like it'll break the socket, then you can remove the metal parts.

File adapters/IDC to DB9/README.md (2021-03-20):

# IDC to DB9

An adapter that isn't actually an adapter might seem a bit strange at first look, but I promise that there's a use-case for it somewhere. One of them is that a few systems computers have recessed controller ports, the Commodore Amiga 600 is a rather common example of this. What that means in a slightly lesser amount of words, not by much, is that most DB9 connectors won't fit on these systems without using a hacksaw. That's why I created this small adapter, that is just a straight plug from 2x5 IDC to DB9. Another reason is that this way you can actually build the whole system without actually soldering wires onto a connector.

Given the rather generic use of this module compared to the others, I can't say anything about said systems ability to power a C64 JoyKEY with backlights and the whole package - I've added a power jumper so that we can stop the module from drawing power from the system (short **VCC_EN** if you know what you're doing).

IDC to DB9 Adapter
IDC to DB9 Adapter (bottom)

# BOM
The parts listed are the ones I've used when building a Sinclair adapter for use with the *C64 JoyKEY*, part listed in parenthesis are considered optional (meaning you could build a more limited version of it). 

| Reference | Item | Count | Order |
| --- | --- | ----- | --- |
| PCB | Fabricate using Gerber files | (1)| [PCBway](https://www.pcbway.com/project/shareproject/C64_JoyKEY__IDC_to_DB9_.html)
| J1 * | 2x5 pin straight header pins or 2x5 IDC | 1 |
| J2 ** | DE-9 Female straight connector | 1 |

*) Breakable dual row pin headers can be used here, but I find it is nicer to use a 2x5 pin connector here instead. The cable needed is a 2x5 pin IDC cable (usually listed as *AVR* or *JTAG* cable) with sufficient length.

**) These are the blue kind with straight pins, it will include a few metal bits on it - remove those and you'll be left with the mostly blue part needed. Bend the pins slightly and match up with PCB, solder before it has a chance to fall off.

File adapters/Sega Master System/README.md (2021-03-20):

# JoyKEY (Sega Master System)

The gamepad for the Sega Master System is mostly compatible with the Atari-style joystick, but as people regularly did during those day - they came up with an entirely different variation when it came to adding the secondary fire-button. The *C64 JoyKEY*, as the name directly implies, has been wired for the Commodore 64, when using it with the Sega Master System we need to change some of the wireing in order to make it all work. You could quite possibly just create a cable doing this for you for the necessary details), but since I hate soldering connectors I put together a small adapter board (just plug a 2x5 pin IDC cable in between the adapter and JoyKEY port 2).

Sega Master System

The completed adapter can be seen below, this also includes the expected position that should be set on the *C64 JoyKEY* device itself. Note that the Sega Master System does not officially have a power pin, so the active parts of the *C64 JoyKEY* will not be powered up.

Sega Master System Adapter
Sega Master System Jumpers

# BOM
The parts listed are the ones I've used when building a Sega Master System controller adapter for the *C64 JoyKEY*, part listed in parenthesis are considered optional (meaning you could build a more limited version of it). 

| Reference | Item | Count | Order  |
| --- | --- | ----- | --- |
| PCB | Fabricate using Gerber files | (1)| [PCBway](https://www.pcbway.com/project/shareproject/C64_JoyKEY__Sega_Master_System_adapter_.html)
| J1 * | 2x5 pin straight header pins or 2x5 IDC | 1 |
| J2 ** | DE-9 Female straight connector | 1 |
| JP1,JP2 *** | 3-pin breakable header pins (w/jumpers | (2)|

*) Breakable dual row pin headers can be used here, but I find it is nicer to use a 2x5 pin connector here instead. The cable needed is a 2x5 pin IDC cable (usually listed as *AVR* or *JTAG* cable) with sufficient length.

**) These are the blue kind with straight pins, it will include a few metal bits on it - remove those and you'll be left with the mostly blue part needed. Bend the pins slightly and match up with PCB, solder before it has a chance to fall off.

***) Can be replace with small pieces of wire if you do not want the ability to swap FIRE1 and FIRE2.

****) There is no more notices than three, I just wanted to see if I could write as many as there are parts on the actual PCB.

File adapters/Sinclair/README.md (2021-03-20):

# JoyKEY (ZX Spectrum +2/+3)
Back in the days when the ZX Spectrum was still all the rage in Europe, but mostly Britain - the Atari joysticks were available from most computer stores. Given that the ZX Spectrum originally lacked a dedicated joystick port, Kempston released an interface that allowed gamers to use an Atari-style joystick with their system. Sinclair, after being bought up by Amstrad added joystick ports to their newly updated machines, but in an attempt to corner the market on the sale of joysticks they changed the pinouts - allowing only the Sinclair SJS to function as expected.

Sinclair System
Sinclair System

A lengthy story that mostly just explains why an adapter is needed, in the case of the *C64 JoyKEY* this an adapter that let's you connect directly to the mentioned systems (ZX Spectrum +2/+3). This is not needed if the joystick port you are using is on one of the common DivIDE/DivMMC or on a standalone Kempston compatible device, as those are already Atari-compatible interfaces. When soldering together the adapter, you will have the option to add a male DB9 connector as well, allowing you to use it as an adapter with common Atari-style joysticks as well.

The completed adapter can be seen below, this also includes the expected position that should be set on the *C64 JoyKEY* device itself. Note that the Sinclair Interface 2 standard does not officially have a power pin, so the active parts of the *C64 JoyKEY* will not be powered up by the system.

Sinclair System Adapter
Sinclair System Adapter
Sinclair System Jumpers

# BOM
The parts listed are the ones I've used when building a Sinclair adapter for use with the *C64 JoyKEY*, part listed in parenthesis are considered optional (meaning you could build a more limited or alternative version of it). Note that depending on the joysticks you want to use with the adapter, you may only need one of the input headers (either IDC or male DB9) - though both would most likely be preferred, as that way you'll have the option later on. 

| Reference | Item | Count | Order |
| --- | --- | ----- | --- |
| PCB | Fabricate using Gerber files | 1 | [PCBway](https://www.pcbway.com/project/shareproject/C64_JoyKEY__Sinclair_adapter_.html)
| J1 * | 2x5 pin straight header pins or 2x5 IDC | 1 |
| J2 ** | DE-9 Female straight connector | 1 |
| J3 | DE-9 Male straight connector | (1)|

*) Breakable dual row pin headers can be used here, but I find it is nicer to use a 2x5 pin connector here instead. The cable needed is a 2x5 pin IDC cable (usually listed as *AVR* or *JTAG* cable) with sufficient length.

**) These are the blue kind with straight pins, it will include a few metal bits on it - remove those and you'll be left with the mostly blue part needed. Bend the pins slightly and match up with PCB, solder before it has a chance to fall off.

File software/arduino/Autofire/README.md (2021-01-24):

# C64 JoyKEY (Autofire)
While the board itself was envisioned as a joystick replacement, I didn't want to do a one off for something that requires Cherry MX switches - so I added an Arduino Pro Micro board! This section of the repository is dedicated to the software created for said device in order to add rapid fire and autofire functionality to it (the Autofire FW emulates what to the computer would appear to be an Atari-style single-button joystick). If you were looking for the [Default FW](https://github.com/tebl/C64-JoyKEY/tree/main/software/arduino/Joykey), because you either wanted something that would function over USB then this is not the firmware you were looking for (this would also match the multi-key [configurations](https://github.com/tebl/C64-JoyKEY/blob/main/documentation/configuration.md), even without an Arduino Pro Micro installed).

Note that the Arduino is expected to control all of the fire buttons, so in you should make sure that this is not attempted when either of the two **DEFAULT_FW** links/jumpers are in place. The remaining jumpers need to be set according to the picture seen below. There is an inherent hierarchy to the way fire buttons, FIRE1 taking precedence over FIRE2, FIRE2 over FIRE3 and so on depending on the settings used. In the current version FIRE1 will act as the normal fire button, FIRE2 toggles the fire button as long as it is held (rapid fire) while FIRE3 toggles autofire on/off. 

Autofire configuration

## Failsafe
I've added a failsafe to the Arduino code so that it doesn't automatically start up and do something that could be harmful to a vintage computer connected via any of the DB9 cables, things it needs to do if you are primarily using it as a USB-device (keyboard or gamepad). This is meant as a way to force **YOU** (and mostly me) to actively think about what you are connecting and where, it also saves you in case you accidentally power up the wrong thing.

Supported systems and the jumpering expected when working with them have been added to the [configuration](https://github.com/tebl/C64-JoyKEY/blob/main/documentation/configuration.md) - ensure you have the correct settings. When you have verified things, the failsafe can be disabled by holding down the LEFT and RIGHT key when plugging in the device. When successful, the SYS LED will then be lit and then stay on. You have 3 seconds to do this.

Magic combination

## Settings
The Arduino sketch have some configurable options, you'll need to edit the file named **settings.h**. Note that you'll have to recompile and upload the new version of the firmware every time you make changes to it.

If you want to use the device as a vintage controller with rapidfire/autofire without having to deal with holding whole failsafe situation, you can force it into this mode by using **FORCE_ALTERNATE** (remove the two slashes in front of it).
```
#define FORCE_ALTERNATE
```

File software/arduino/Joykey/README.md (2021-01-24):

# C64 JoyKEY

While the board itself was envisioned as a simple joystick replacement, I didn't want to do a one off for something that requires Cherry MX switches - so I added an Arduino Pro Micro board! This section of the repository is dedicated to the software created for said device in order to have the board act as a standard USB-keyboard, but note that if you don't want to use it that way there's no need to install those components as it'll work all by itself on most retro computers or consoles (just remember to link both **DEFAULT_FW** links, green jumpers shown below).

DEFAULT_FW jumpers

## Failsafe
I've added a failsafe to the Arduino code so that it doesn't automatically start up and do something that could be harmful to a vintage computer connected via any of the DB9 cables, things it needs to do if you are primarily using it as a USB-device (keyboard or gamepad). This is meant as a way to force **YOU** (and mostly me) to actively think about what you are connecting and where, it also saves you in case you accidentally power up the wrong thing.

Supported systems and the jumpering expected when working with them have been added to the [configuration](https://github.com/tebl/C64-JoyKEY/blob/main/documentation/configuration.md) - ensure you have the correct settings. When you have verified things, the failsafe can be disabled by holding down the LEFT and RIGHT key when plugging in the device. When successful, the SYS LED will then be lit and then stay on. You have 3 seconds to do this.

Magic combination

## Settings
The Arduino sketch have some configurable options, you'll need to edit the file named **settings.h**. Note that you'll have to recompile and upload the new version of the firmware every time you make changes to it.

The sketch includes a couple of alternate modes for USB, one that's a WASD-style keyboard (*KEY_MODE_USB*) and another that will have the device identify as a joystick (*KEY_MODE_JOYSTICK*). You'll have to change **USB_ALTERNATE_MODE** definition in *settings.h* to match whichever you would like to use.

```
#define USB_ALTERNATE_MODE KEY_MODE_USB
```

If you don't want to use the *C64 JoyKEY* with any vintage computer, meaning you'll only be using the board in USB-mode then you might want to disable the failsafe completely - this can be done by uncommenting the line defining **USB_FORCE_ALTERNATE** (remove the two slashes in front of it).
```
#define USB_FORCE_ALTERNATE
```

Finally, when using the *C64 JoyKEY* in USB-keyboard you'll probably want to specify what each key corresponds to when you push it. The default setting assigns them to work the same as cursor keys and the Q, E and R key, settings that'll hopefully make sense when using it to play games.
```
#define KEYMAP_DEFAULT KEYMAP_CURSOR_GAME
```
The comments above the line should include a list of possible replacements, just replace the bit that says
**KEYMAP_CURSOR_GAME** with something more relevant to you. When using the module as a streamdeck, you'll probably want keys that aren't actually found on an ordinary keyboard to avoid accidental key overlapping - the setting **KEYMAP_FUNCTIONS** assigns the key to F13 through F19. The file **constants.h** has the actual definitions in case you want to know the details, or want to edit one of them to match whatever you want instead.

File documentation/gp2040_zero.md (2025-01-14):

# From Zero to GP2040
This section of the documentation deals with how to get started with the [GP2040CE](https://gp2040-ce.info/)-firmware, and while the firmware has quite excellent documentation that I highly recommend that you spend time getting familiar with, it doesn't cover any specific implementation of it. What that means is that when you put together a controller using it, there are quite a lot of decisions that were made along the way that needs to match up to the configuration in order for things to function properly. In this document, I'll attempt to cover the things that you'll need when using it with either [C64 JoyKEY 2040](https://github.com/tebl/C64-JoyKEY/tree/main/C64%20Joykey%202040) or [Adapter 9 from 2040](https://github.com/tebl/C64-JoyKEY/tree/main/Adapter%209%20from%202040).

Devices running GP2040CE

While the former is a joystick, in a novel form, intended for use with vintage systems via the use of adapters and cables, it can also be used with more modern systems via the addition of a Raspberry Pi Pico "Zero". The latter takes a vintage, or new in the case of the quite excellent ArcadeR joysticks, converting it for use with modern systems such as Raspberry Pi, or most of the later systems from Retro Games Lts (TheC64, TheA500, TheSpectrum etc.). Both will show up on the connected system as a standard wired *Xbox-360 Controller* so compatibility appears to be quite good.

- [1> Introduction](https://github.com/tebl/BulkyModem/blob/main/documentation/getting_started.md)
- [2> Installation](#2-commodore-64)
- [3> Configuration](#3-configuration)
  -  [3.1> Pin mapping](#31-pin-mapping)
  -  [3.2> Peripheral Mapping](#32-peripheral-mapping)
  -  [3.3> LED Configuration](#33-led-configuration)
  -  [3.4> Display Configuration](#34-display-configuration)
- [4> Settings](#4-settings)
  -  [4.1> Input Mode Settings](#41-input-mode-settings)
  -  [4.2> Gamepad Settings](#42-gamepad-settings)
  -  [4.3> Boot Input Modes](#43-boot-input-modes)
  -  [4.4> Hotkey Settings](#44-hotkey-settings)
- [5> The rest....](#5-the-rest)

# 1> Introduction
The Raspberry Pi Pico was created by the Raspberry Pi Foundation, also somewhat confusingly known everywhere for creating the Raspberry Pi boards. The difference between the two is that while the Raspberry Pi is an entire computer on a small board (SBC), a Pico on the other hand is a microcontroller like the Arduinos that most of are familiar with (with at least a decade of advances in technology between the two). The official Pico boards are quite large, and for that reason we're instead using a different version of it that doesn't include quite as many physical pins though in terms of power the two of them use the same chip. This variant is known as the *RP2040-Zero*, and this is the name I'll be using from this point on.

RP2040-Zero

I can only assume that in time there will be several more variants of these popping up, but the one created by *Waveshare* shown on the left seem to be the one listed on more reputable. The second one can be picked up from not quite so reputable places, but apart from the slight differences in quality - they seem to work exactly the same from what I've been able to see. When in doubt, buy more than one so that you'll have one as a spare.

# 2> Installation
Installation of the GP2040CE-firmware on a Raspberry Pi Pico, in any of its forms is quite easy to pull off. Before that you'll need to download a few things first, and the first of them is the [firmware](https://gp2040-ce.info/downloads/) itself. Note that you'll need to download the correct one for your board, and for any of the *RP2040-Zero* variants (including clones) you'll find the download link under the heading *Waveshare RP2040-Zero*. In addition I also recommend having the following files available:
- [flash_nuke.uf2](https://gp2040-ce.info/assets/files/flash_nuke-cde388d5530c9dcfd5394a0ca51009f2.uf2)
- [force_webconfig.uf2](https://gp2040-ce.info/assets/files/force_webconfig-347a1a8575da1ae314cf9ceb7df793bc.uf2)

Installing the firmware on any version of the Pico, is quite easy as all you need to do is to hold down the button marked *BOOT* when connecting it up to your computer. If all goes well, your computer should detect it as a new flash storage drive - and in the case of MS Windows should pop up an explorer window with its contents. Copying and then pasting a single file with the ".uf2"-extension should automatically flash the microcontroller for you without any additional steps being needed.

As for installing GP2040-CE, I recommend that the first thing that you flash it with it is the one listed as *flash_nuke* above. This takes care of ensuring that all config files are wiped off it first, this seems at least to be necessary on the clones though it's a process that only takes a second or two, so it is time well spent. After *flash_nuke* has completed its tasks, the explorer window should automatically open up again for you again. This time you'll paste in the expected GP2040-CE firmware, a file named something like *GP2040-CE_X.X.XX_WaveshareZero.uf2*, and it should take a considerably longer time to complete (around 30s).

After the copy process completes, the explorer window should disappear and if it doesn't immediately show up again - then we can only assume that everything has been installed as it should be. Disconnect the device before continuing on to the next step, configuring the device.

# 3> Configuration
GP2040-CE as previously mentioned includes a web-based interface for configuring just about anything, and while your initial experience of shock and horror in having to deal with all of it in order to just play around with your favorite joystick - you'll quickly find that it's quite intuitive. Just take it one step at a time, and know that if you completely mess it up - just follow the installation steps again to completely wipe it, that way you'll always find a way back to a working configuration. Here's what the interface looked like at the time of writing this:

Configurator

As for how you can get into it, for that we need to hold down the switch marked "S2" when plugging it into your computer. When doing that it won't present itself as an Xbox-360 Controller, instead it'll look like a network device with a web server running on it:
- [http://192.168.7.1](http://192.168.7.1).

Open up that link in your browser, and you'll get the configurator - pretty amazing stuff if you ask me! Just make sure that you're holding down the right key, on your *C64 JoyKEY 2040* that's the second button from the left when looking at the front of the device. As for the *Adapter 9 from 2040*, that's the second to last button on the left side of the device (some faceplates will have this listed as *MENU*).

**NB!** If you find that you can't get into the configuration, there might be an issue with the configuration stored on the device. The easiest way around that particular issue is to hold down the *BOOT*-button on the *RP2040-Zero* when connecting it up to your computer, when it pops up with the same explorer window as it showed during the installation - paste *force_webconfig.uf2* into the window. Like we saw previously, the window should disappear and as long as everything works as it should, you should now finally be able to use the [configurator](http://192.168.7.1).

Continuing on with the actual configuration for either devices, the recommendation is that for now you skip the first menu option labelled "Settings", as that's more relevant for us once everything has been set up. Instead we'll move onto "Configuration" instead, working our way down the list (a few we'll skip entirely).

**NB!** The software isn't modelled after an Apple-product, each page has its own *Save*-button and you need to click it in order to actually save anything. Clicking over to a different section of the configuration will cause it to forget any changes that you've made to it.

## 3.1> Pin mapping
While GP2040-CE will mostly present itself as a wired *Xbox-360 Controller* to the system it is connected to, but the how each button is mapped to the physical pins on the *RP2040-Zero* is completely customizable by setting up different pin mappings. More on the "mostly"-part later, but let's just move on for now by starting with the one I'm primarily using as the primary profile:

TheA500

As we're dealing with a piece of PCB we can't just move something anywhere, and expect it to work - the physical pins marked PINXX already go somewhere specific. What we can do is choose the logical function that they have, so if you want to swap B1 and B2 then you can just do that.

As this is probably your first time looking at this interface, just work your way down the list and set the functions like how I've done it. Make sure to delete the ones that aren't explicitly listed here, that also includes those marked *Assigned to addon* (they will be assigned at a later step in the configuration process). 

Click *Save* when satisfied with your changes. It'll tell you to reboot the controller for the changes to take effect, but instead we'll just move on with the process. The first profile created will often be referred in the official documentation as your primary profile, and you can use the interface to add a few more of them. Here are some of my suggested settings, with the profile numbers that I've set them to.
1. [TheA500](https://github.com/tebl/C64-JoyKEY/blob/main/gallery/gp2040/rp2040-zero/the_a500.png)
2. [TheC64](https://github.com/tebl/C64-JoyKEY/blob/main/gallery/gp2040/rp2040-zero/the_c64.png)
3. [Evercade](https://github.com/tebl/C64-JoyKEY/blob/main/gallery/gp2040/rp2040-zero/evercade.png)

TheSpectrum also uses the settings as for TheA500, and I expect that The400 would work pretty much the same way. Evercade is similar, but it prefers to use *B2* as the primary fire button so for that system I tend to swap *B1* and *B2*. TheC64 is pretty much an oddball at is does not accept GP2040-CE when presented as an *Xbox-360 Controller*, or what we commonly refer to as *Xinput*-mode (more on that later), and we instead need to have it seen as a Nintendo-controller - explaining why all of the pin mappings are completely scrambled from all of the other profiles.

Beyond all of that, these are just my recommendation for getting started. Feel free to play around with it, just maybe not do that until everything is working like I intended for them to.

## 3.2> Peripheral Mapping
Peripheral Mapping

The section dedicated to peripheral mapping is mostly where we configure which physical pins have been set aside for communicating with the display, if we even chose to have one at all. On both of the devices featured in this document I've only made provisions for an I2C-display, and given the usage of the *RP2040-Zero*, the natural pins to use in this case will be given as shown below. Enable *I2C1*, set *SDA* on pin 26, *SCL* on pin 27 and hit *Save* at the bottom of the screen.

## 3.3> LED Configuration
**NB!** Function only present on [C64 JoyKEY 2040](https://github.com/tebl/C64-JoyKEY/tree/main/C64%20Joykey%202040)

Player LEDs

This section mostly deals with assigning addressable LEDs to individual buttons on a custom arcade cabinet or stick, but in the case that you're configuring a [C64 JoyKEY 2040](https://github.com/tebl/C64-JoyKEY/tree/main/C64%20Joykey%202040) then the section labelled *Player LEDs* will be of interest to us. Here I've used physical pin 15 as a way to control the brightness of the backlight, but because we're driving it through a transistor then the signal becomes inverted. A GP2040-CE controller is normally set up as *Player 1* by default, taking the inverted value into account then the backlight will turn on if we use that pin with with players 2-4. I hope that the firmware ends up with a feature for inverting it sometime in the future, but for now it at least works in a way that we can control.

## 3.4> Display Configuration
Display Configuration

Here we'll be configuring the usage of displays connected to the device, requiring that we've already taken the time to set up the physical pins for *I2C* earlier in [Peripheral Mapping](#32-peripheral-mapping). The type of display should be automatically detected by the system, so we mainly only need to enable it.

As for what's normally displayed on it during normal usage, many profiles can be selected under *Layout Options* and I can only assume that there are some that are more suited for our purpose. More on that once I eventually find one of them.

You can enable a custom splash screen as, for that you also need to enable it by setting *Splash Mode*. While I don't expect you to actually use on your devices, I've included an image file for you at [/software/gp2040/bootscreen.png](https://github.com/tebl/C64-JoyKEY/blob/main/software/gp2040/bootscreen.png) - if only so that you can have that as a starting point when making your own in any basic image editing software.

# 4> Settings
With the configuration already taken care, we can move onto *Settings*. This is more in the category of how we're choosing to use the controller right now, and in an indirect way what we're intending to use it with.

Settings

## 4.1> Input Mode Settings
 *Current Input Mode* is one that we've briefly covered earlier, but for most systems we set it to *Xinput* as that means that the controller will be presented to your system as a wired *Xbox-360 Controller*. It's a widely supported controller, and if it supports different USB-controllers this is likely to be one of them.

Settings

Except in the case of *TheC64 Mini* where it does absolutely nothing, but we'll get around that by setting it to *Nintendo* instead (for some reason only Retro Games Ltd would possibly know). Unfortunately that scrambles all of the button locations, but as we've planned ahead and already created a separate profile for it in [Pin Mapping](31-pin-mapping) we can choose to unscramble them again. In the next section.

## 4.2> Gamepad Settings
If you came straight here from [Input Mode Settings](#41-input-mode-settings), then the option you're looking for is simply called *Profile* at the bottom. If you're intending to use my devices with various devices, you mostly need to think of the previously discussed *Input Mode* as having a tightly coupled relationship with the selected *Profile* - one generally not working by itself, but perfection when taken together. If you're just using it as a way to optimize your layouts for certain games on a specific system, then just do that  and ignore my largely non-sensical ramblings.

Gamepad Settings

If you were to compete in any way, then *SOCD Cleaning Mode* is apparently a huge requirement to be allowed to even participate. The purpose of this is when you have something like the [C64 JoyKEY 2040](https://github.com/tebl/C64-JoyKEY/tree/main/C64%20Joykey%202040) then you're able to perform actions that wouldn't physically be possible on a normal joystick, for example pushing the *LEFT* and *RIGHT* direction at the same time. This would cause some older games to start glitching out. I just play old games by myself, so making sure that *UP* always works makes more sense to me.

## 4.3> Boot Input Modes
Boot Input Modes

Here we've got a listing of the buttons that can be held when powering on the controller, to have it automatically switch to that [Input Mode](41-input-modem-settings) for you. It doesn't happen automatically, you need to hold the button for roughly 20 seconds before it takes effect.

**NB!** Confusingly your selected [Pin Mapping](31-pin-mapping) profile as selected in [Gamepad Settings](#42-gamepad-settings) will generally mean that at least some of these buttons have physically moved around on you. For that reason I highly recommend using the web interface when setting things up, especially if you don't have a screen installed on the device itself.

## 4.4> Hotkey Settings
Hotkey Settings

These shortcuts require holding down the *Function*-key on your device, in the case of the [C64 JoyKEY 2040](https://github.com/tebl/C64-JoyKEY/tree/main/C64%20Joykey%202040) this is the right-most key on the front of the device. On [Adapter 9 from 2040](https://github.com/tebl/C64-JoyKEY/tree/main/Adapter%209%20from%202040) this will be the top button on the right row of keys. You can set them as you like, but for the most part it helps to think of them as a way to use seldom used buttons that you physically don't actually have.

*S1*/*S2* is commonly thought of as *START*/*SELECT*, by holding down *Function* these double up as the *Home* and *Share* buttons as commonly found on Playstation-controllers. I also tend to set a few longer key combinations to switch between different [Pin Mapping](31-pin-mapping)-profiles.

# 5> The rest....
I think that's just about anything I can think about mentioning at this point, at least in terms of getting started with using GP2040-CE with any of these two devices. As for what comes next I believe that you'll need to take your time learning how at least some of it works, but if you've made it to this point you're already 99% there anyway.

TheSpectrum

As for testing things out, do note that any kind of *Mini*-system will generally not be the place to start - instead connect to your modern computer,  load up [Gamepad Tester](https://hardwaretester.com/gamepad) and start testing it out. Note that it needs to be in *Controller*-mode when doing it, meaning that you should just connect the cable without holding down any of the buttons.

For anything not already covered in any shape or form, consider the following resources:
- [GP2040-CE Homepage](https://gp2040-ce.info/)
- [GP2040-CE Documentation](https://gp2040-ce.info/web-configurator/)

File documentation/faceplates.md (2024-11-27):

# Faceplates
The *C64 JoyKEY* will have a selection of faceplates, these are primarily just here to make the device a bit prettier by hiding the actual electronics. Secondly it adds some rigidity to the design, quite possibly making it less likely to fail after heavy use. Check out [faceplate](https://github.com/tebl/C64-JoyKEY/tree/main/faceplates)-section for designs available, but as always you can find these and other PCBs on [PCBWay shared projects](https://www.pcbway.com/project/shareproject/?tag=C64%20JoyKEY). For obvious reasons, the ones based on other peoples artwork will not be included (see [making your own]((#2-making-your-own)) for some hints on how you can create your own instead). 

- [1> Faceplate variations (A/B)](#1-faceplate-variations-ab)
  - [1.1> Keycaps A](#11-keycaps-a)
  - [1.2> Keycaps B](#12-keycaps-b)
- [2> Making your own](#2-making-your-own) 
  - [2.1> Editing artwork](#21-editing-artwork) 
    - [2.1.1> Bitmap to Component Converter](#211-bitmap-to-component-converter)
    - [2.1.2> Pixel converter](#212-pixel-converter)
  - [2.2> Adding the artwork to PCB](#22-adding-the-artwork-to-pcb)
  - [2.3> Ordering PCBs](#23-ordering-pcbs)
    - [2.3.1> Generate new Gerber files](#231-generate-new-gerber-files) 
    - [2.3.2> Ordering from PCBway](#232-ordering-from-pcbway)
  - [2.4> Show them to the world](#24-show-them-to-the-world) 

# 1> Faceplate variations (A/B)
These generally come in two different variations, A and B with a number added to separate the various designs. The A version has a larger PCB cutout that should allow you to use most of Cherry MX-compatible keycaps of the kind that descends down past the actual switch (low/medium profile), if you're in doubt this is the version to get. The B designs have a smaller cutout, but requires the use of keycaps that don't descend so far down (high profile).

A selection of B-variations I've used at some point can be seen below.



## 1.1> Keycaps A
The keycaps pictured below were bought from AliExpress though you'll undoubtedly find them on any site that sells similar Chinese goods, a likely candidate other than that one is eBay, Temu or Wish. I don't want to include a direct link to a listing as those are bound to have disappeared by the time anyone reads this. The blue keycaps (also comes in silver and gold I thing) were listed as *low profile Cherry MX compatible gaming* keycaps, also described as mechanical keyboard keycaps. The ones on the right were listed as *PBT 1u gaming Cherry MX* keycaps, available in several colours - if you want to add your own labels these are the ones I'd recommend. Both were in the 10$ price range.

A variety 1
A variety 2

## 1.2> Keycaps B
These I fell in love with when I saw them, listed as *round steampunk typewriter keycaps* - I thing I got a complete set for a keyboard for under 10$. I think these are what are called *high profile* keycaps, but I'm a bit fuzzy the specifics as just about everything I've bought have been badly-described Chinese products. The ones shown below are the ones I have, and as you might've guessed I designed a new faceplate so that there wouldn't be such a huge gap.

B variety 1

# 2> Making your own
Making your own faceplates requires you to already have an installation of [KiCAD 5](https://kicad.org/) already set up and ready to go, it's a free open source package. You will need a downloaded copy of all of the *C64 JoyKEY* project files, you'll find those on [github.com/tebl/C64-JoyKEY](https://github.com/tebl/C64-JoyKEY) - the files can be downloaded by clicking the green *Code* button ot the page, then select *Download ZIP* from the resulting menu. Unzip it somewhere that you'll be able to find later.

The next part is to draw up some suitable 1-bit artwork, this is because PCBs really only have a single silkscreen colour and there are no gradients available though you would still have the option to do dithering as was very common with comic books and newspapers.  For converting the png image into a module that KiCAD can use, you generally have two options depending on the effect that works best with your artistic creation - these will be described separately. But I'm getting ahead of myself here, and for that we need do some artwork editing.

## 2.1> Editing artwork
Using an image editor like Gimp, you can set up this mode using *Image --> Mode --> Indexed... --> Use black and white (1-bit) palette* - note however that KiCAD doesn't handle transparancy, so ensure that the background is set to either black or white. When you're happy with the results, or you just want to see how it'll look on a PCB, use *File --> Export as...* and give it a name with the extension *png*. If you're not already familiar with Gimp, you're probably not going to have a lot of fun doing this - I'd just recommend using the *Paint*-application on Windows for simple conversions or editing.

With some artwork ready to go, we can begin converting it to a more KiCAD friendly format - refer to either of the two following sections for instructions on how to do this. You'll probably have to go back and forth, so don't be surprised if you'll have to do this over a few attempts at getting things right.

### 2.1.1> Bitmap to Component Converter
The conversion tool built into KiCAD, *Bitmap to Component Converter*, really doesn't like sharp edges - so it'll try to smooth and make all edges a nice rounded finish - which may or may not be a good thing depending on what you want.

The conversion tool is started from the main KiCAD project menu, it's the one with a green *"a"* on it (for some reason). Start it up and click *Load bitmap*, select your image - flip over to the *Black&White Picture* tab to see a preview of what the result will look like (if everything is blank, then you probably need to get rid off the transparent background).

For the resolution, the easiest would be if you use the same DPI setting as the original picture to avoid scaling, but as the result will be nice and rounded it's not as important. Play around with these values until the indicated size in millimeters is something that'd fit nicely into your PCB area. Click export and save the resulting *mod*-file to the directory *common/modules/artwork.pretty*. Generally, as KiCAD by itself is not able to scale footprints we'll need to go a bit back and forth until you can find the size you want to use.

### 2.1.2> Pixel converter
The second option, one that is probably more suited to the kind of artwork where you want the pixelated look is using a script to convert the image to a bunch of square blocks - mostly without a single smoothed edge in sight. Personally this is the method I prefer to use, as it is perfectly suited for artwork that would directly match the original 8bit source material. Thankfully we don't have to actually deal with the whole script part though, all you need to do is to go to [img2mod.wayneandlayne.com](http://img2mod.wayneandlayne.com/).

Use *Choose File* to select your png-file, click the *invert* checkmark if you need it and finally click upload to get a preview version of the file. Use browser back-button to return to the form, then deselect the *Preview* checkmark to download a copy of a converted mod-file, move it into to the directory *common/modules/artwork.pretty*.

Changing the scale will change the size of each "pixel" once converted, but for now just use 0.5 - we'll come back to it later once we actually see how it looks on the PCB. Generally, as KiCAD by itself is not able to scale footprints we'll need to go a bit back and forth until you can find the size you want to use.

## 2.2> Adding the artwork to PCB
At this point we should be ready to test out the design you've been working on. Start by opening up either one of the faceplate projects in KiCAD, either *C64 JoyKEY Faceplate A1* or *C64 JoyKEY Faceplate B1*, depending on the type of keycaps you're going to be using - [1> Faceplate variations (A/B)](#1-faceplate-variation-a-b). Start up *PCB Layout Editor* (often referred to as *PCBnew*) from the main project menu, you should now get the whole drawing of the faceplate on the screen, the yellow lines indicating the physical dimensions of the resulting PCB.

Delete or add any of the silkscreen components you do not want, such as text or images that have somehow been left there from the last time I made some changes to it. Use *Place --> Footprint* to add the artwork, but it'll take up to a couple of minutes to load everything so be patient at this point and don't despair if it it's seemingly taking forever. When it's ready, find the artwork in the section named *artwork* and double-click it in the listing to the right to add it to the PCB. Move it around so that you're happy with the placement (click footprint and press *m* to use the move command).

At this point you'll probably find that the footprint is either too small or too large, revisit sections 2.1.1 or 2.1.2 to tweak the size - save and overwrite the footprint file. The version already on the PCB won't automatically update to reflect this, so you'll have to do this manually by editing it (click footprint and press *e*). Click the button labelled *Update Footprint from Library*, then click *Update* in the resulting dialog and then finally close it. Repeat as needed until satisfied.

If you want to get a feeling for how the PCB'll look, you can use *View --> 3D Viewer* to get a preview. Note however that the viewer doesn't seem to understand how to subtract any parts of the image that's not within the physical edges of the PCB, so either remove it from the picture when you get the sizing correct or just ignore that for now (PCBs will still look great as those parts will be physically removed at the factory).

## 2.3> Ordering PCBs
What to do from this point on will differ somewhat, based on where you will order the PCBs, but as I use PCBway the description will for the most part reflect the settings required there. If you don't already have an account there, please use this [link](https://www.pcbway.com/setinvite.aspx?inviteid=88707) to get a 5$ discount and help me at the same time. Doing it this way gives me a small discount on future hardware revisions, allowing me to keep sharing things like this instead of just keeping them for myself.

### 2.3.1> Generate new Gerber files
Back to KiCAD again, and you should still be in the *PCB Layout Editor*. We're now going to create updated Gerber files in the format expected by [pcbway.com]((https://www.pcbway.com/setinvite.aspx?inviteid=88707)), this is done using *File --> Plot ...* - ideally everything should already be set up for you. Ensure that under *Plot format*, it is set to *Gerber* and that under *Gerber options* there is a checkmark on *Use Protel filename extensions* - output directory should either be left on *export/* or set somewhere that you'll be able to find later. Generate the files by clicking the *Plot* button, then click on *Generate Drill Files...* - here you should make sure that it is set to the same output directory and that there is a checkmark in front of *Minimal header* under *Drill File Format*. Click the *Generate Drill File* button and you should have mostly everything you need from KiCAD.

Web sites usually want all of the exported files as a ZIP-file, so just navigate over to the export folder you were supposed to put somewhere that you could find. Select all files and just send to *Compressed (zipped) folder* if you're on windows, any other platform and you're expected to know how to do this by yourself.

### 2.3.2> Ordering from PCBway
Navigate on over to the PCBway web site, specifically the [PCB Instant Quote](https://www.pcbway.com/orderonline.aspx) page. Enter the dimensions as 100mm by 75mm, set quantity to 5 in order to keep shipping costs low (10 is usually the same price, but there is only so many one can use at a time). Under solder mask you can select any of the top row colours to keep things at the 5$ pricetag (ones below it are significantly more expensive).

Click on *Calculate* on the right hand side to calculate costs, update your location to get something more realistic. If it looks good, just click on *Save to cart* to go on to the next step. At the next part of the ordering process, you'll need to finally upload the zipped Gerber files by clicking on *+Add Gerber File* and adding it to the site. What happens at this point is that you'll need to wait for someone at PCBway.com to manually verify that everything looks OK, this'll take everything from a few minutes to hours depending on how much time they've got on their hands.

Once the review has been completed, you can order the PCBs from them and actually pay for shipping and so forth. Remember to use the 5$ discount coupon if you're a new user to the site, but have a browse around the site for any other [shared projects](https://www.pcbway.com/project/member/shareproject/?bmbno=04C9EDC7-08B5-43) you might like - especially the actual [C64 JoyKEY module](https://www.pcbway.com/project/shareproject/C64_JoyKEY__Module_.html) that you'd need in order to use with your fancy new faceplates. Have a look on [C64 JoyKEY](https://www.pcbway.com/project/shareproject/?tag=C64%20JoyKEY) for all of the shared projects relating to this specific project.

## 2.4> Show them to the world
When you get the new PCBs, please show them off to the world via your favorite social platform - whichever one that ends up being. I only do these projects for fun, because why else would someone throw money at something without ever being able to recoup the costs. Meaning that it's even more fun seeing my hobby projects when they're being used by people.

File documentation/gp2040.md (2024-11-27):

# GP2040
GP2040, or more accurately [GP2040-CE](https://gp2040-ce.info/), is an open-source firmware for making your own controllers suitable for hooking up to modern systems. While the original versions of the *C64 JoyKEY* used a custom Arduino-based sketch for doing the same thing, but doing so properly takes a little more effort to make things compatible all over the board - at least more than I'm personally able to support while looking at the thing once or twice in a decade. Later versions therefore use GP2040-CE firmware running on a vastly more powerful Raspberry Pi Pico, which also means that it's absolutely overflowing with features. And customizability that would inevitably make every controller unique from the one built by the next person.

My point with all this is that what follows will not work on all of them, but should work on the *C64 JoyKey 2040* as long as you follows the setup exactly. 

### Configure for TheC64:
TheC64 won't work with GP2040 set to *xinput* input mode, but it will work with it set to *Nintendo*. That will however scramble the placement of the keys so we'll start with setting to load the second profile, then the actual input mode is switched by holding a key while plugging it in. Follow the following steps exactly:

- `P1 F1` + `P1 F4` + `RIGHT`
- Disconnect, then hold and keep holding `P1 F6` when plugging in the cable.
  - Mode switches after approximately 20 seconds.

### Configure for TheAmiga or TheSpectrum:
TheAmiga as well as TheSpectrum should be set to *xinput* input mode. Assuming that we're in *TheC64*-mode, you can back to this mode by having GP2040 load the first profile, then the actual input mode is switched by holding a key while plugging it in. Follow the following steps exactly:

- `P1 F1` + `P1 F4` + `LEFT`
- Disconnect, then hold and keep holding `P2 F3` when plugging in the cable.
  - Mode switches after approximately 20 seconds.

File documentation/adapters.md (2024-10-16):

# C64 JoyKEY Adapters
Instead of adding a ton of jumpers to the module with the aim of accounting for every system known to man, I instead chose to leave those details up to the adapter. These generally slot into the specific system, connected up to port 2 of the *C64 JoyKEY* using a 2x5 pin *JTAG* or *AVR* cable. One key difference between the multi-system support provided by the *C64 JoyKEY* boards and many other multi-system adapters and universal controllers, is that the circuits are kept as close to the original system as possible - this ensures that there will never be any lag added (such as those added by an MCU interpreting and translating signals). An Arduino Pro Micro can be added, but this is only required when connecting it up to a modern system over USB as well as controlling things such as the underglow LEDs.

Click the adapter for a more detailed description on how it is put together, the parts needed to build the thing as well as any other relevant details. Some of these will require a specific blue connector that is not sold directly in the way you usually encounter them, see the details below how to dismantle a common component to get it. Check out the [configuration](https://github.com/tebl/C64-JoyKEY/blob/main/documentation/configuration.md)-page for a more comprehensive list of systems supported.

| Adapters | System | Order |
| --- | --- | --- |
| [Amiga CD32](https://github.com/tebl/C64-JoyKEY/tree/main/adapters/Amiga%20CD32) * | Commodore Amiga CD32 | PCBWay
| [Atari 7800](https://github.com/tebl/C64-JoyKEY/tree/main/adapters/Atari%207800) | Atari 7800 (Atari 7800 Pro System in N.A.) | [PCBWay](https://www.pcbway.com/project/shareproject/C64_JoyKEY__Atari_7800_adapter_.html)
| [IDC to DB9](https://github.com/tebl/C64-JoyKEY/tree/main/adapters/IDC%20to%20DB9) | Any Atari-style joystick port | [PCBWay](https://www.pcbway.com/project/shareproject/C64_JoyKEY__IDC_to_DB9_.html)
| [MSX](https://github.com/tebl/C64-JoyKEY/tree/main/adapters/MSX) * | MSX-line of computers | PCBWay
| [NES](https://github.com/tebl/C64-JoyKEY/tree/main/adapters/NES) | Nintendo Entertainment System | [PCBWay](https://www.pcbway.com/project/shareproject/C64_JoyKEY_NES_adapter_74ada4a5.html)
| [Sega Master System](https://github.com/tebl/C64-JoyKEY/tree/main/adapters/Sega%20Master%20System) | Sega Master System I/II | [PCBWay](https://www.pcbway.com/project/shareproject/C64_JoyKEY__Sega_Master_System_adapter_.html)
| [Sega Mega Drive](https://github.com/tebl/C64-JoyKEY/tree/main/adapters/Sega%20Mega%20Drive) | Sega Mega Drive I/II (also called Sega Genesis in N.A.) | [PCBWay](https://www.pcbway.com/project/shareproject/C64_JoyKEY__Sega_Mega_Drive_Genesis_adapter_.html)
| [Sinclair](https://github.com/tebl/C64-JoyKEY/tree/main/adapters/Sinclair) | ZX Spectrum +2/+3 | [PCBWay](https://www.pcbway.com/project/shareproject/C64_JoyKEY__Sinclair_adapter_.html)

*) Module is untested.

## Blue female connector
As previously mentioned, there is a specific blue connector that will often show up in vintage computer designs - the female blue DB-9 connector. This is not sold like this, at least I've never seen a listing for it on any site - the reason is that you can only get it by looking for a female DB9-connectors with a blue inner colour, then pulling that apart until you end up with only the blue part. The eBay search that I use is "db9 female straight PCB mount", and should net you around 10 of them for a couple of euros.

Refer to the images below, but the process is easy - just start by removing the hex screws as those are mostly always in the way. On some systems you can leave the metal shroud in place, but given that it's rather hard to remove when things have already been soldered in place I tend to remove it as well. Just pick up a solid pair of pliers and start twising on the strain relief anchors until the metal parts can be separated from the blue part. Bend the rows of pins slightly together so that it mostly stays put when soldering it onto the adapter edge connectors.

Build 020
Build 021

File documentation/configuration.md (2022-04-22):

# Configuration
This document details the jumpers physically found on the *C64 JoyKEY*, see document [firmware](https://github.com/tebl/C64-JoyKEY/blob/main/documentation/firmware.md) if you are looking for a description of software settings. Check out the table of contents below and jump directly to it if you are looking to use this device with a specific vintage system, note that this will mostly describe settings relevant to the [Default FW](https://github.com/tebl/C64-JoyKEY/blob/main/software/arduino/Joykey/) - the use of the [Autofire FW](https://github.com/tebl/C64-JoyKEY/blob/main/software/arduino/Autofire/) or the USB-mode is described separately.

- [Vintage systems](#1-vintage-systems)
  - [Amstrad CPC 464](#11-amstrad-cpc-464) *
  - [Atari 2600](#12-atari-2600)
  - [Atari 7800](#13-atari-7800) *
  - [Commodore 64](#14-commodore-64)
  - [Commodore 64GS](#14-commodore-64)
  - [Commodore VIC-20](#14-commodore-64)
  - [Commodore Amiga](#15-commodore-amiga)
  - [MSX](#16-msx) *
  - [Nintendo Entertainment System (NES)](#17-nintendo-entertainment-system-nes) *
  - [Sega Master System](#18-sega-master-system) *
  - [Sega Mega Drive](#19-sega-mega-drive) *
  - [ZX Spectrum +2/+3](#110-zx-spectrum-23) *
- [Autofire](#2-autofire)
- [USB-mode](#3-usb-mode)

*) Using C64 JoyKEY with the system may require an adapter to enable the use of more buttons, skip to the specific section for a description of steps needed to make it work. See [adapters](adapters.md) for details on the various adapters supplied as part of this project.

## 1> Vintage systems
Quite a lot of vintage computers and consoles support the classic Atari-style type of joystick (female DB9 connector on the end), the *C64 JoyKEY* is a variation of this type of joystick. Where things start to get weird is when everyone started adding two or more additional fire buttons to them, in many cases changing the what those signals are expected to look at. I found [icomp.de](http://wiki.icomp.de/wiki/DB9-Joystick) wiki to be particularly helpful as it includes a comparison for a lot of them, essentially giving an overview over what could be expected to function safely.

For all of these, both **DEFAULT_FW** are expected to be linked/jumpered - the Arduino Pro Micro is not needed when using the *C64 JoyKEY* and you should not disable the failsafe (which assumes Autofire or USB-mode).

Read on for details on various systems I've tested the controller with. Note that, as already mentioned, the module can be used as a standard Atari-style joystick with one fire button - the listed machines are mostly those that support or even require more than one fire button. As the [Atari 2600](#12-atari-2600) was the basis for most of these designs, I've chosen to include it for that very specific reason.

### 1.1> Amstrad CPC 464
Released in 1984, an entire two years after the Commodore 64 - it was a late arrival on the 8bit computer era. For some it was the computer they had and loved as a child, for many other it was a bit of a failiure as quite a lot of the games released were simple conversions from the ZX Spectrum. Unfortunately that meant that the excellent colour facilities of the computer went unused and too much of the game code went into emulating a different computer, leading to a rather poor experience. With the right game however, it was kind of awesome as long as you didn't expect much in the sound department.

Amstrad CPC 464 System

It did unfortunately also feature a rather proprietary approximation of the, now *de-facto*, standard Atari-style joystick connection. It will work as a single joystick parts with joysticks without any active electronics within them, meaning that everything with an auto-fire circuit as well as the *C64 JoyKEY* will not work with it. I've not had a look at the autofire-side of things, but I've put together an adapter solution in the form of the [CPC464 Joystick Splitter](https://github.com/tebl/CPC464-Joystick-Splitter) that'll give the two joystick ports you always wanted - as well as ensuring that the C64 JoyKEY functions without any issues.

Amstrad CPC 464 Adapter
Amstrad CPC 464 Jumpers

### 1.2> Atari 2600
Released all the way back in 1977, it was one of the first mainstream video game consoles that allowed the user to change the games. Personally I never knew someone who had one, somehow the mention of Atari usually included: 
```
Atari, that's shit - isn't it?
- Childhood friend.
```
I grew up in the 80s, so certainly the 70s era of video game electronics spectacularly failed at presenting graphics similar to what the Commodore Amiga had. Nevertheless, it was the original home video console system established - to the degree that the joysticks used well into the 90s were known as standard Atari-style joysticks (digital, four directions and a single fire button). Now that I'm older I've grown rather fond of the old machine, it is just somewhat sad that they sold it well past their *sell-before* dates.

Anyway, back to the C64 JoyKEY. Support for a single fire button is built right in, as expected - only reason I've included this section is that the whole thing is a standard by itself. The jumper settings shown should work with just about anything that came with a DB9 connector and had a single fire button. Other systems that had extensive support for single-button Atari-style joysticks were the Commodore 64, Commodore Amiga, Kempstone joystick interface (ZX Spectrum), MSX, Atari 8 bit computers and 16 bit computers to mention a few.

Atari 2600 System
Atari 2600 Jumpers

### 1.3> Atari 7800
Released in 1986, the successor wanted to take on the likes of Nintendo as well as the home computer market by launching an updated system that was fully backwards compatible with the Atari 2600. Unfortunately a sound chip wasn't added, so it sounded terrible by 80s standards. The controllers were also pretty damn terrible, which is why I've created an [adapter](https://github.com/tebl/C64-JoyKEY/tree/main/adapters/Atari%207800) so the C64 JoyKEY could be used instead. The adapter is only needed if you want support for two fire buttons.

Atari 7800 Pro System
Atari 7800 Adapter
Atari 7800 Jumpers

### 1.4> Commodore 64
There are two variants for connecting up the C64 JoyKEY to a Commodore 64, including the GS and VIC-20. Variant A is probably the one you are looking for, it does however require connecting both of the DB9 cables in order to use all three buttons (depending on game support).

- [Commodore 64 (variant A)](#141-commodore-64-variant-a)
- [Commodore 64 (variant B)](#142-commodore-64-variant-b)

Commodore 64
Commodore 64 GS

#### 1.4.1> Commodore 64 (variant A)
A common way to add a second fire button to the Commodore was simply plugging in another joystick and using the fire button on that, this would be the same as pressing the space bar in many games. On the *C64 JoyKEY* connected up as shown below, that would actually be the third fire button. Fire2 is wired into the SID-chip, meaning that we can use it with games that expect a controller of the type that came with the Commodore 64GS.

C64 variant A

#### 1.4.2> Commodore 64 (variant B)
The Commodore 64 can support two additional fire buttons by connecting up signals to the SID-chip, via the POTX and POTY signals. This variant only required a single cable, but given that I've not seen any titles with support for the third fire-button you might as well just use variant A. Fire button 2 is the same on both variants and it is mostly used with Ocean cartridges and a few modern game releases.

C64 variant B

### 1.5> Commodore Amiga
One of my favourite systems, so good in fact that I always wanted an Amiga 500 - even though I had a 386/DX 25Mhz computer with VGA graphics. Mostly because at that point it always had nice graphics, and that sound was miles beyond anything the PC speaker could even dream of creating (Soundblaster only came into my house a few years later). So it would come to no surprise that I'd want to test out the *C64 JoyKEY* on my Commodore Amiga systems.

Amiga System

There are some caveats with the Amiga systems, for one the standard connector won't fit into the joystick port on the Amiga 500 so you'll want a straight [IDC to DB9 adapter](https://github.com/tebl/C64-JoyKEY/tree/main/adapters/IDC%20to%20DB9) for that - either that or you'll need to modify the connector in order to make it fit.

**NB!** The second caveat is that the second or even third fire button probably won't work on all games, or even any of them from the testing I've done. The reason for this is the polarity protections resistors added added at R1 and R2 - these are here to ensure you don't accidentally kill your Commodore 64 system by setting the jumpers wrong. So you'll need to make a choice here; install a piece of wire across these because you know what you're doing (jumper as shown below), or stay happy with a single button in your Amiga games (jumper like [Atari 2600](#12-atari-2600)).

Amiga Jumpers

### 1.6> MSX

### 1.7> Nintendo Entertainment System (NES)
Nintendo Entertainment System, commonly referred to as the *NES*, is a console that doesn't really require an introduction. While it wasn't as popular around here, mainly for the fact that it wasn't a computer, it certainly has found its place among just about any collector. A somewhat furiating system to maintain for collectors today due to issues with the cartridge port, but when you want the full-size thing - there's no way around it. The original gamepad was actually quite good, but it's a bit cramped for my hands and so I made yet another [adapter](https://github.com/tebl/C64-JoyKEY/tree/main/adapters/NES) for the *C64 JoyKEY*, if only so that I'd have the option of using it. Also, it's surprisingly satisfying to play Super Mario with proper clicky keyboard switches! 

Nintendo Entertainment System

Requires the sacrifice of an unoriginal extension cable, but in case someone is wondering - no original hardware was hurt in the making of this. For reference, the original controller that came with this system is still intact in its original box - ready at a few seconds notice, just in case the Nintendo-compliance department does a sudden inspection of my setup. A completed adapter including the relevant jumper settings on the *C64 JoyKEY*  is shown below, with this setup you'll have *SELECT* on the top switch as well as *START* on the adapter itself. With later revisions of the C64 JoyKEY you can disable the top switch, using the switches on the bottom-left corner instead for these functions.

Nintendo Entertainment System Adapter
Nintendo Entertainment System Jumpers

### 1.8> Sega Master System
Released in 1986, this is probably my favourite console - if I was forced to pick something without a keyboard built into the case. I'm not completely convinced by the gamepads available though, so I took it unto myself to build an adapter [adapter](https://github.com/tebl/C64-JoyKEY/tree/main/adapters/Sega%20Master%20System) for it so that the C64 JoyKEY could be used instead. 

**NB!** This is not recommended when a pause mod has been installed in the system, the reason for this is that the key combinations used are easy to activate, usually by accident, when using the C64 JoyKEY (it's not dangerous, it'll just annoying as the system will pause every time the combination is activated).

Sega Master System
Sega Master System Adapter
Sega Master System Jumpers

### 1.9> Sega Mega Drive
The only console that was truly *mega*, doing whatever Ninten...don't! Apparantly that was mostly sports so I never bought one back in the day, then again most software for my IBM PC was available for the cost of a blank floppy so that might be why I never had much desire for the cartridge-based systems back then. For some reason the system was launched as the Sega Genesis in North America, but we try not to talk about those guys anymore.

Over to the actual system, mine is one version 1 - the one marked *high definition graphics* on the device itself. Now that I have an Everdrive for the system, I find myself playing on it more and more. More than likely, just because it has the definitive 16-bit home version of Out Run on it (observe the shiny red keycaps to match the iconic Ferrari Testarossa Spider). 

Sega Mega Drive

I've gone ahead and made a [3-button adapter](https://github.com/tebl/C64-JoyKEY/tree/main/adapters/Sega%20Mega%20Drive) for the *C64 JoyKEY*, but note that as the system actually requires a fourth button - the *START* button - I added that to the adapter itself. Sega did however make their controller ports recessed into the case, so we also need to add a straight [IDC to DB9](https://github.com/tebl/C64-JoyKEY/tree/main/adapters/IDC%20to%20DB9) adapter in order to make the cable fit into the controller ports. [IDC to DB9](https://github.com/tebl/C64-JoyKEY/tree/main/adapters/IDC%20to%20DB9) *VCC_EN* must be linked in order to power the adapter.

Sega Mega Drive Adapter
Sega Mega Drive Jumpers

### 1.10> ZX Spectrum +2/+3
Sinclair, having recently been acquired by their competitor - Amstrad - added joystick ports directly to their shiny new +2 and +3 computers, but in order to ensure the sale of branded Sinclair joysticks (SJS and the later SJS2) they changed the pinouts. This ensured that your run of the mill Atari-style joysticks didn't work, but as history would show the ever-present Kempston interfaces would instead remain the standard for gaming on the ZX Spectrum - leaving the ports mostly unused.

While I do not own an ZX Interface 2, the schematics found online seem to indicate that while they shared the same interface (as seen from the computer) - the ZX Interface 2 doesn't have the same shuffling of pinouts like the Amstrad produced machines. I would like to verify this, but that would require owning an Interface 2 - so please send me one, I promise to love and ultimately never give it up ([source](https://www.youtube.com/watch?v=dQw4w9WgXcQ)).

I do however own +2 and +3 computers that I've always wanted to have a got at using the built-in joystick ports on, so I've made an [adapter](https://github.com/tebl/C64-JoyKEY/tree/main/adapters/Sinclair) for this purpose. This can also be assembled so that you can use the adapter with any Atari-style joystick, not just the C64 JoyKEY. There is no support for using more than one joystick button on these interfaces, even if you use two adapters.

**NB!** If it wasn't entirely clear; you will only need this adapter when connecting up to the built-in joystick ports on the ZX Spectrum +2 or ZX Spectrum +3. Most other peripherals that came with joystick ports, more than likely a Kempston - used standard Atari-style joysticks and no adapter would be needed for those.

Sinclair System
Sinclair System Adapter
Sinclair System Jumpers

## 2> Autofire
See [Autofire FW](https://github.com/tebl/C64-JoyKEY/blob/main/software/arduino/Autofire/) for more information on using the device in Autofire-mode, note that it too has a failsafe-mode so you'll need to hold LEFT and RIGHT key on powerup to enable it (that way things are not accidentally activated until you're sure you've set the jumpers correctly). Autofires require that both of the **DEFAULT_FW** pads have **NOT** been linked/jumpered, this ensures that signals aren't also connected directly to your vintage system.

Using the autofire firmware assumes that the system will emulate a single-button joystick connected to a vintage system, the actual FIRE-buttons (FIRE1,2 and 3) will not be directly connected to the system and the Arduino will handle controlling the actual fire button signal sent to the vintage computer system.

Autofire Configuration

# 2> USB-mode
The [Default FW](https://github.com/tebl/C64-JoyKEY/blob/main/software/arduino/Joykey/) can be used to connect the computer to a modern-ish computer, the device will present itself as either a keyboard or a joystick depending on the settings used. USB-mode supports all of the keys, but FIRE2/FIRE3 will be disabled unless you set the jumpers to what is shown below. USB-mode does not care about the two DEFAULT_FW jumpers, those just control the behavior when connected to a vintage system.

USB System

As mentioned in the description for the firmware, there is a failsafe in place so that it will not be automatically activated when the board is connected to a computer over USB (you can change this behavior if you only intend to use it connected over USB). The failsafe is disabled by holding down the LEFT and RIGHT key when plugging in the device - you will have approximately 3 seconds to do this and you should hold them down until the SYS LED lights up.

Magic combination
USB Configuration

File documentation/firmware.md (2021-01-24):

# Firmware
The *C64 JoyKEY* does not actually need to have an Arduino Pro Micro installed unless you specifically want the functionality provided by it, either because you want to be able to use it as a keyboard/joystick with a modern computer over USB (this is provided by the standard firmware). The alternate autofire-firmware uses the Arduino as a programmable autofire unit, in this mode the controller acts as a standard Atari-style joystick with a single fire button (except we have an AVR that can press the button faster than we possibly can).

JoyKEY USB

## Firmware selection
As already mentioned, the firmware options listed below can be used. Note that as mentioned when [building](https://github.com/tebl/C64-JoyKEY/blob/main/documentation/building.md#soldering-it-together) the unit, there is a couple of links marked **DEFAULT_FW** that must be set according to your selection.
- [Default FW](https://github.com/tebl/C64-JoyKEY/tree/main/software/arduino/Joykey)
- [Autofire FW](https://github.com/tebl/C64-JoyKEY/blob/main/software/arduino/Autofire/)

## Installing the firmware
Installation of the firmware would normally include compiling the code via either *Arduino Studio* or using the development environment I'm using these days - *PlatformIO*. Unless you want to do any coding, then whichever you already have installed should do what you need it to do.

Most of the fireware options require at least a couple of additional libraries that probably wouldn't come with a standard installation, so you'll need to add them manually if you are using *Arduino Studio* (*PlatformIO* will install them automatically for you) - see below for some more details.

For more specifics on the firmware, follow the links from the [Firmware selection](#firmware-selection) section. One thing worth mentioning is that the firmware will have a failsafe mode, the reason for this is that some combinations may be considered harmful to vintage computers connected unless you actively pay attention to what you are doing. The unit will start up only when the LEFT and RIGHT key is held down just after it is powered on, the SYS LED will come on to show you that the unit is now enabled.

Magic combination

### Arduino Studio
For assistance on getting going with the Pro Micro on common tasks such as uploading code and communicating with the module, I found the drivers guides on [learn.sparkfun.com](https://learn.sparkfun.com/tutorials/pro-micro--fio-v3-hookup-guide#hardware-overview-pro-micro) to be of great help (the board I purchased and used for the project was a DIY MORE Arduino Pro Micro). The following is what I have selected as board type, make sure that you pick the one that corresponds to your module - the Pro Micro will have to be manually reset using the reset switch if you run into problems.

Arduino board configuration)

The project requires some additional library from what usually comes with the default installation of *Arduino Studio*. The first one is called Keyboard, you'll find it by searching for it via *Manage libraries* from the *Tools*-menu and you can install it from there. The second libray is [ArduinoJoystickLibrary](https://github.com/MHeironimus/ArduinoJoystickLibrary), you'll have to download and install that one according to the  [installation-instructions](https://github.com/MHeironimus/ArduinoJoystickLibrary#installation-instructions) provided by the author.

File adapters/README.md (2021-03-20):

# Adapters
Instead of adding a ton of jumpers to the module with the aim of accounting for every system known to man, I instead chose to leave those details up to the adapter. For more specific information, see the [adapters](https://github.com/tebl/C64-JoyKEY/blob/main/documentation/adapters.md) document available as part of the documentation (mostly to avoid having to maintain two copies of the same information).

For BOM, parts needed on putting it together is found in the relevant subfolder READMEs.

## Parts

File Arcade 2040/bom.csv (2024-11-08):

Reference | Value | Datasheet | Footprint | Qty | DNP
D2 | 1N5819 | http://www.vishay.com/docs/88525/1n5817.pdf | Diode_THT:D_DO-41_SOD81_P10.16mm_Horizontal | 1
D3 | TURBO_LED | ~ | Connector_JST:JST_XH_B2B-XH-A_1x02_P2.50mm_Vertical | 1
J1 | Jack-DC | ~ | power:BARREL_JACK | 1
J2 | Expansion | ~ | Connector_JST:JST_XH_B4B-XH-A_1x04_P2.50mm_Vertical | 1
J3 | RGB | ~ | Connector_JST:JST_XH_B4B-XH-A_1x04_P2.50mm_Vertical | 1
J4 | TURBO_EN | ~ | Connector_JST:JST_XH_B2B-XH-A_1x02_P2.50mm_Vertical | 1
J5 | DIR_RIGHT | ~ | Connector_JST:JST_XH_B5B-XH-A_1x05_P2.50mm_Vertical | 1
J6 | DIR_LEFT | ~ | Connector_JST:JST_XH_B5B-XH-A_1x05_P2.50mm_Vertical | 1
J7 | B1 | ~ | Connector_JST:JST_XH_B2B-XH-A_1x02_P2.50mm_Vertical | 1
J8 | B2 | ~ | Connector_JST:JST_XH_B2B-XH-A_1x02_P2.50mm_Vertical | 1
J9 | B3 | ~ | Connector_JST:JST_XH_B2B-XH-A_1x02_P2.50mm_Vertical | 1
J10 | B4 | ~ | Connector_JST:JST_XH_B2B-XH-A_1x02_P2.50mm_Vertical | 1
J11 | L1 | ~ | Connector_JST:JST_XH_B2B-XH-A_1x02_P2.50mm_Vertical | 1
J12 | L2 | ~ | Connector_JST:JST_XH_B2B-XH-A_1x02_P2.50mm_Vertical | 1
J13 | L3 | ~ | Connector_JST:JST_XH_B2B-XH-A_1x02_P2.50mm_Vertical | 1
J14 | R1 | ~ | Connector_JST:JST_XH_B2B-XH-A_1x02_P2.50mm_Vertical | 1
J15 | R2 | ~ | Connector_JST:JST_XH_B2B-XH-A_1x02_P2.50mm_Vertical | 1
J16 | R3 | ~ | Connector_JST:JST_XH_B2B-XH-A_1x02_P2.50mm_Vertical | 1
J17 | A1 | ~ | Connector_JST:JST_XH_B2B-XH-A_1x02_P2.50mm_Vertical | 1
J18 | A2 | ~ | Connector_JST:JST_XH_B2B-XH-A_1x02_P2.50mm_Vertical | 1
J19 | S1 | ~ | Connector_JST:JST_XH_B2B-XH-A_1x02_P2.50mm_Vertical | 1
J20 | S2 | ~ | Connector_JST:JST_XH_B2B-XH-A_1x02_P2.50mm_Vertical | 1
M1,M3,M4 | Mounting | ~ | mounting:M3_pin | 3
R2 | 470 | ~ | Resistor_THT:R_Axial_DIN0207_L6.3mm_D2.5mm_P10.16mm_Horizontal | 1
U1 | Pico |  | pi_pico:RPi_Pico_SMD_TH_Clean | 1

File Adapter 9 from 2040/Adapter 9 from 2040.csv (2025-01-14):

Reference | Value | Datasheet | Footprint | Qty | DNP
IC1 | 0.96_I2C_OLED |  | i2c_oled:0.96_I2C_OLED_NEW_Top | 1
J1 | Atari |  | RND_DSUB:DSUB-9_Male_Horizontal_P2.77x2.84mm_EdgePinOffset7.70mm_Housed_MountingHolesOffset9.12mm | 1
JP2 | P1_GND | ~ | Jumper:SolderJumper-3_P1.3mm_Open_Pad1.0x1.5mm | 1
JP3 | P2_VCC | ~ | Jumper:SolderJumper-3_P1.3mm_Open_Pad1.0x1.5mm | 1
M1,M2,M3,M4 | Mounting | ~ | mounting:M3_pin | 4
SW1 | S1 |  | switch_cutout:SW_PUSH_6mm | 1
SW2 | S2 |  | switch_cutout:SW_PUSH_6mm | 1
SW3 | L1 |  | switch_cutout:SW_PUSH_6mm | 1
SW4 | R1 |  | switch_cutout:SW_PUSH_6mm | 1
SW5 | B2 |  | switch_cutout:SW_PUSH_6mm | 1
SW6 | B3 |  | switch_cutout:SW_PUSH_6mm | 1
SW7 | B4 |  | switch_cutout:SW_PUSH_6mm | 1
SW8 | Fn |  | switch_cutout:SW_PUSH_6mm | 1
U1 | RP2040-Zero |  | pi_pico:RP2040-Zero_Clean | 1

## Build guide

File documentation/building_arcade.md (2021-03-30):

# 1> Building C64 JoyKEY Arcade
The *C64 JoyKEY Arcade* is a specialized version of the *C64 JoyKEY*, substituting Cherry MX switches for Sanwa arcade parts instead. Everything else has been kept mostly identical, allowing you to use all of the rather excellent adapters available as well. None of the adapters require any microcontrollers, for the most part the circuit will be similar to what were used on the original controllers - ensuring that you have a completely lag-free experience when playing on supported vintage systems.

Last arcade build

The *C64 JoyKEY Arcade* can be built or configured in a few different ways, so take a look at the [configuration](https://github.com/tebl/C64-JoyKEY/blob/main/documentation/configuration.md) document - so that you'll have an idea of what you want to do with it. Pay particular attention to whether you'd require any of the features provided by the Arduino Pro Micro. While I am on of those weird people that prefer that the stick is on the wrong side, this is completely left up to you to decide and you do not need to install it this way if you would prefer the more standard orientation.

- [1> Building C64 JoyKEY Arcade](#1-building-c64-joykey-arcade)
  - [1.1> Ordering components](#11-ordering-components)
  - [1.2> Soldering it together](#12-soldering-it-together)
  - [1.3> Assembling the parts](#13-assembling-the-parts)
  - [1.4> Dealing with cables](#14-dealing-with-cables)
  - [1.5> All done](#15-all-done)
- [2> BOM](#bom)
  - [2.1> Adapters](#21-adapters)

## 1.1> Ordering components
The first step in building it, is what you've already done - figuring out what you wanted out of it in the first place! The second step is taking stock of which parts you don't already have, check out the [BOM](#BOM) (*Bill of Manufacturing*) below for a somewhat detailed of everything I used when building the prototype. Note that any adapters you'll want will have their own BOM.

You should be able to get most from the more reputable electronic component oligopolists, but because of extreme import fees where I live - those are for the most part not an option for me (I can't afford to pay €40 worth of fees to get €10 worth of parts at ten times the cost). What I do instead is order most things from ebay and AliExpress, you'll have to do a bit more of guesswork to find the correct parts - additionally, delivery times are most probaly to be counted in number of weeks and not days. 

My best suggestion on getting what you need the first time, is to use the search function and start with the description I've added, compare it to the pictures and order whichever looks to be the closest - if it's a cheap part, just get a few different ones! Pin headers usually come in 40-pin strips, both dual row and single row ones will be needed - add some right-angle ones as well (you'll just break off what you need). For some parts such as common resistor values, M3 nylon hex standoffs and switches it might be preferable to get a kit instead of the specific kind (the are usually referred to as a parts kit "*assortment*").

Order what you need, set the components aside until you're ready to start assembling things.

**NB!** I haven't specifically listed any of the actual arcade components for this build, mainly because people will have very specific preferences when it comes to the components they want to use and the quality they want them to have. Personally I just picked up an Aliexpress kit consisting of eight rather cheap buttons, a Sanwa clone stick and a generic black plastic case. These are cheap enough to get you started without going completely overboard. Not all builds will require more than a handful of buttons, but I just put them there - just to cover up the holes already in the case.

## 1.2> Soldering it together
Now that you have everything that you'll need in order to progress, it is time to start soldering things together. Do however start by studying the PCB, so that you'll have a general overview over where the various components fit on the board. Observe that a few of the components such as the diodes have a specific polarity they need to be installed in, you'll see this as indicated on the silkscreen printing. At the time of writing this guide, the PCB looks like the following:

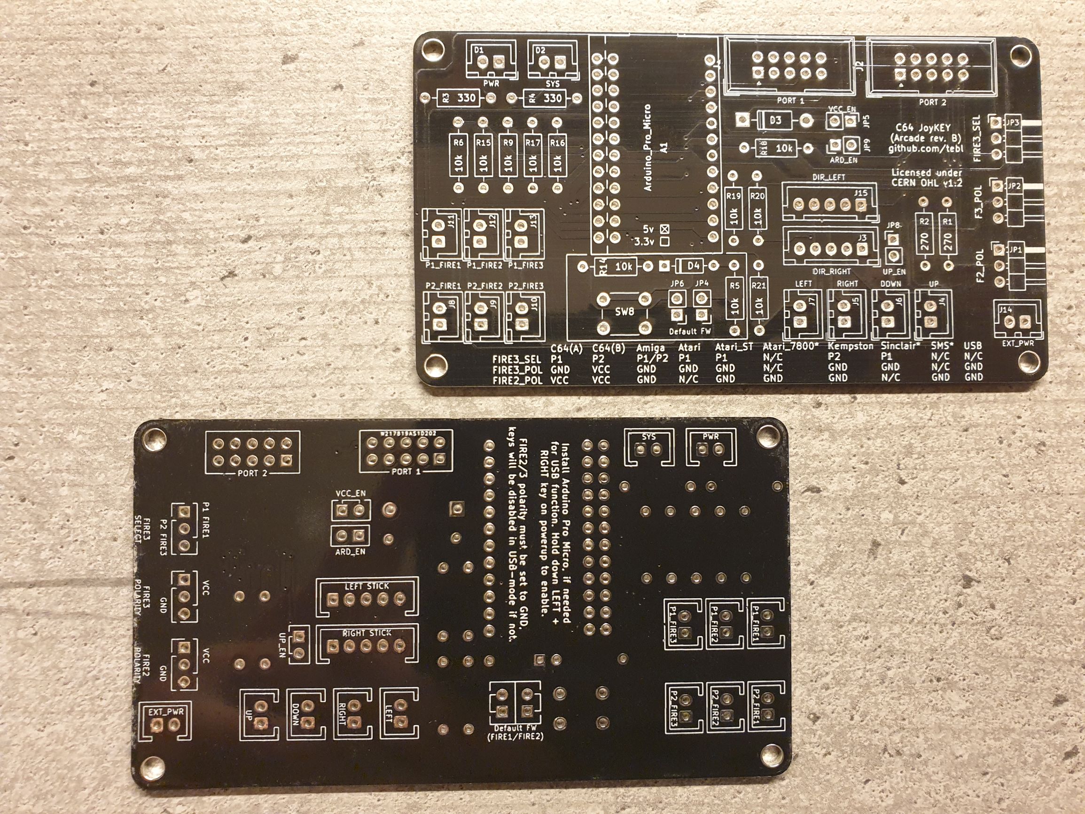
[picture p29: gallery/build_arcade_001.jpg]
Build 001


When ready to start soldering things into place, start by installing the physically smaller parts such as the resistors as well as the diodes (observing the polarity) - then move on up vertically to the taller parts to keep things manageable. I usually leave the Arduino as the last component to go in, mostly to limit the chance of accidentally killing it with static or some stray electricity when installing the rest.

The Arduino Pro Micro unfortunately seem to come in physically different variations, the variants that seem to be more common are shown below. The *C64 JoyKEY Arcade* can use either of these two variants, but you'll need to install it so that the straight header pins that go between the main PCB and the Arduino are soldered in the correct positions - I recommend doing a bit of dry-fitting **before** commiting to either one of them. The switch below it is needed if you accidentally try to flash it using the wrong settings in *Arduino Studio*, there is a separate page that details how to deal with the [firmware](https://github.com/tebl/C64-JoyKEY/blob/main/documentation/firmware.md).

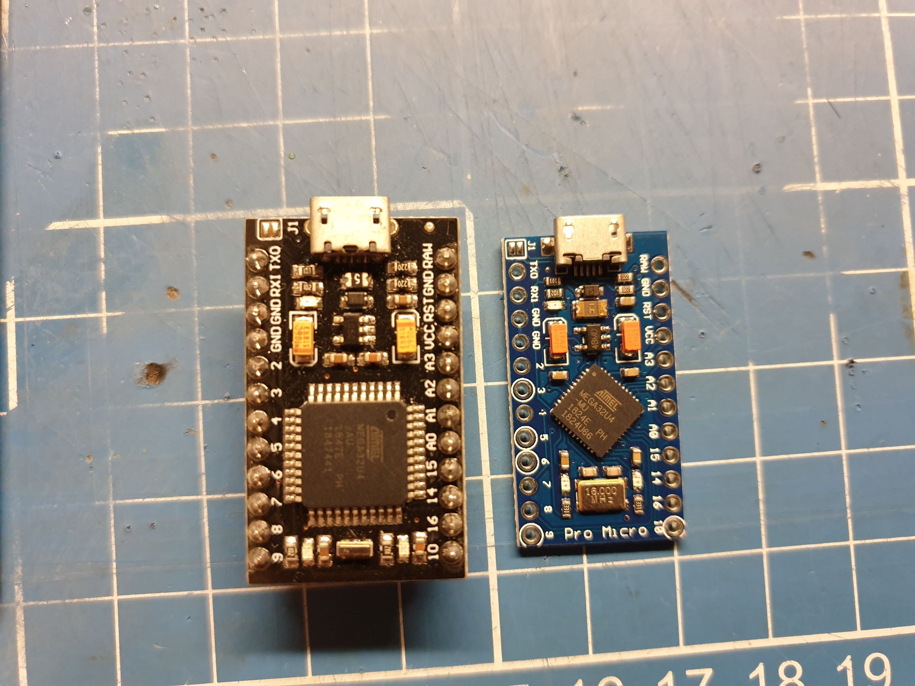
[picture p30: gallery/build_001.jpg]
Arduino Pro Micro variants


Notice the spot for two jumpers marked **DEFAULT_FW**? You'll need to solder a piece of wire here in across both of these positions, the leftovers you got when snipping the leads from the resistors can be used for this purpose. What this does is connect the switches directly to the outputs to the vintage computer system, the only case for not doing this is when you specifically want the Arduino to run the Autofire firmware. This should also be linked when not installing any Arduino at all. If you are in doubt as to what you will do further down the road, consider just installing some pin headers and jumper caps here instead - there is a lot of space available in an Arcade case so it might be nice to have it as an easily changeable option.

The same goes for the power links marked **VCC_EN** and **ARD_EN**. It may be tempting to install male pin headers and jumper caps here, linking these allows the circuits to be powered up - the first one disconnects all power comping from any vintage system while the second just prevents the Arduino from being powered up. I recommend linking VCC_EN, but leaving ARD_EN unconnected until you are sure about how much power can be provided via the controller ports to which you'll be connecting the unit to.

## 1.3> Assembling the parts
At this point the main PCB should be mostly completed, the manual from this point on will therefore focus on tasks such as installing it into an arcade controller case and making the required cables. The first step you'll have to tackle is deciding where to install the board, at first glance you'll get the impression of having an enormous amount of case available for the little board.

The case I used has quite a lot of space available, but all of the cables were very short - for this reason I chose to install it in the center of the case. I added 10mm hex standoffs (F-F) to the board so that it clears any of the mounting and case supports already in there, I used a pen to draw out the outlines of the standoffs in the case then drilled 3mm holes - 6mm nylon M3 were then screwed into the standoffs from the underside as well.  

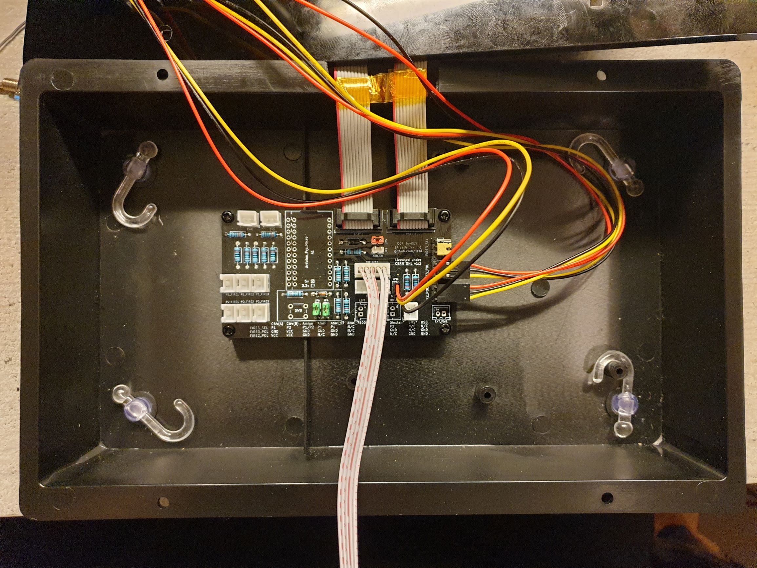
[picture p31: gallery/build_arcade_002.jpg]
Build 002


The 2x5pin IDC cables used to connect to most vintage computers via the use of a suitable adapter, needs to be able to feed out to the outside of the case. For a better result you should probably used some sort of fine jewelry saw for this task, but as that was somewhere out in the garage - I just cut those bits out with some pliers and cleaned up the edges with a metal file instead. Any sharp edges that remain will more than likely destory the flat ribbon-cables, so I added a few layers of tape to give them some more chance of surviving. Probably should have used some soft electrical tape, but with the economy the way it is I'll need some time to save up for stuff like that.

Compared to the *C64 JoyKEY* board you won't actually see the main PCB, as it'll be inside the case - for that reason I recommend marking the ribbon cables properly so that they aren't swapped around by accident. I usually use a Brother P-touch label printer for stuff like this, but you could always mark the cables in some other way.

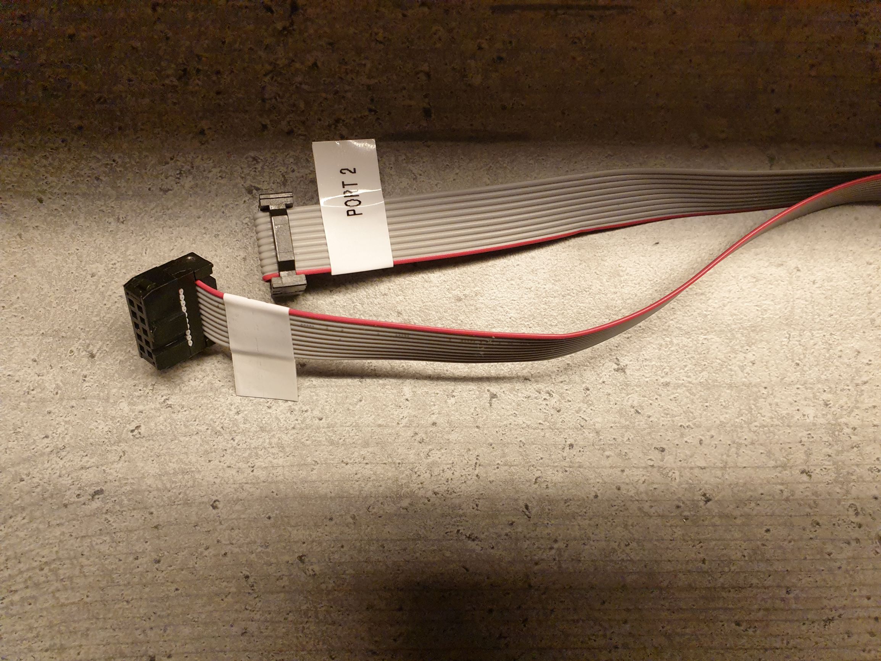
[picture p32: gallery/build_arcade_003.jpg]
Build 003


## 1.4> Dealing with cables
Up to this point, there shouldn't be any more than the flat ribbon cables connected to the unit though you can probably tell by the pictures that I cheated and did a few anyway - mostly just to ensure that all of my cables reached properly. I've chosen to install my stick on the right-hand side, meaning that in the arcade world this is a left-handed setup - the cable used for it is therefore plugged into DIR_LEFT (yes, it's all backwards compared to vintage computers).

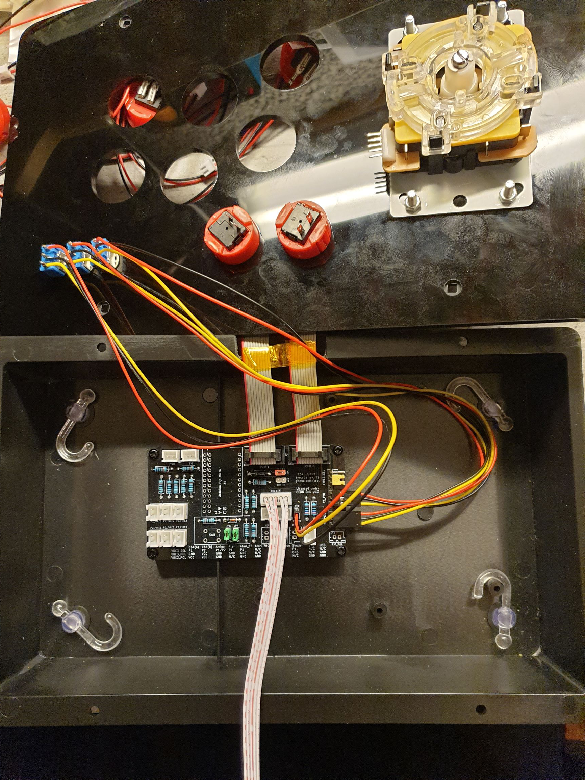
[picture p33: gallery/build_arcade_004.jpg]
Build 004


Initially I had the thought of just using SPDT-switches installed on the case to account for FIRE2 and FIRE3 polarities, but by doing so I had forgotten that in addition to high and low we also needed a third state - not connected (N/C). I could have ordered the correct ones, specifically DPDT (on-off-on), but I didn't want to wait so I used what I had instead - specifically by just running the center pin of the polarity switch through one side of the enable switch instead. Also, having more switches is more fun. The switch marked up is used to disable the UP-direction on the stick, allowing me to use as dedicated button instead for this.

**NB!** When using SPDT switches such as these, the three pins on the bottom might be reversed from what you might expect. What this means is that when you have the switch in the upper position, the bottom two pins will be connected together - the reason I mention it is so that you don't accidentally set switch polarity to something that the vintage system you're using it with won't appreciate. To keep the mental gymnastics low I recommend wiring so that enabled/VCC is the upper switch position. 

Build 005

The red buttons you just connect where you want them, move them around if you don't like the layout originally selected. Personally I set the first middle row buttons to port 2 fire 1/2/3, then set the first one on the second row to UP, fire 1 and finally fire 2. Finally, I connected one of the smaller buttons to port 1 fire 3 - mostly so that I could map it to the start button with the [Sega Mega Drive adapter](https://github.com/tebl/C64-JoyKEY/tree/main/adapters/Sega%20Mega%20Drive).

## 1.5> All done
That should be most of the information you'll need. Head on over to the [configuration](https://github.com/tebl/C64-JoyKEY/blob/main/documentation/configuration.md) page to ensure that you have the switches set up in the correct position. The picture below shows how I've set them up for use with the Sega Mega Drive adapter, here both of the FIRE2 and FIRE3 buttons are **EN**abled and for that reason they are in the **UPPER** position. Other systems require the switch to be set to **N/C** instead, this is the lower position.

When the required **POL**arity is listed GND, such as with the Sega Mega Drive, this means you should put the corresponding switch in the lower position. When listed as VCC, then you should put it in the upper position.

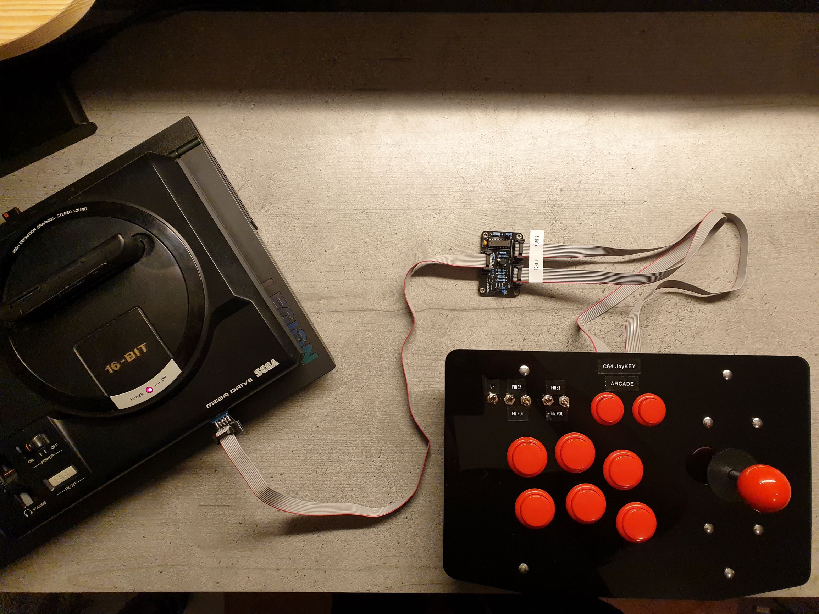
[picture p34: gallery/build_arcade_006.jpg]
Build 006


# 2> BOM
This section attempts to maintain a list of the parts you'd need in order to build a feature-complete *C64 JoyKEY*, any parts that you could potentially do without have part counts listed in parenthesis. You will find all tested PCBs including on [PCBWay shared projects](https://www.pcbway.com/project/shareproject/?tag=C64%20JoyKEY) relation to this project, this will also include any [adapters](https://github.com/tebl/C64-JoyKEY/blob/main/documentation/adapters.md) - if you should need them.

| Reference | Item | Count | Order  |
| --- | --- | ----- | --- |
| PCB | Fabricate using Gerber files | 1 | [PCBway](https://www.pcbway.com/project/shareproject/C64_JoyKEY_Arcade.html) |
| A1 | Arduino Pro Micro | (1)| |
| | 12-pin straight pin header | (2)| |
| D1,D2,J4-J14 ****| 2-pin JST-XH socket | (16)| |
| J3,J15 **** | 5-pin JST-XH socket | 1 (1) | |
| D3 | 1N4001 diode DO-41 | (1)| |
| D4 | 1n4148 diode DO-35 | (1)| |
| J1,J2 *** | 2x5 pin straight header pins or 2x5 IDC | 2 | |
| | 2x5 pin IDC to female DB9 cable | 1 (1) | |
| JP1-JP3 * | 3-pin right-angle header pins (w/jumper cap) | 3 | |
| JP4,JP6 ** | 2-pin straight header pins (w/jumper cap) | 2 | |
| R1,R2 | 270 ohm resistor | 2 | |
| R3,R4 | 330 ohm resistor | (2)| |
| R5,R6,R9,R14-R21 | 10k ohm resistor | (12)| |
| SW8 | Tactile momentary switch 6x6x6mm | (1)| |
| | Nylon M3 hex standoffs 10mm (F-F) | (4)| |
| | Nylon M3 screws | (8)| |
| Arcade parts | Sanwa original or cloned arcade parts | | |

*) The parts listed here assumes you want a unit built for a specific machine, requiring you to open the controller to change the settings. If you do not want this, then I recommend purchasing 5 SPDT switches suitable for panel mounting as well as some wire to connect them up. The reason you'll need 5, and not 3, is so that you can have the switches set as N/C (meaning disconnected).

**) Replace with piece of wire if not installing Arduino Pro Micro on the board, or you know you won't need the alternative autofire firmware at any point.

***) Breakable dual row pin headers can be used here, but I find it is nicer to use a 2x5 pin connector here instead. The easiest way to get a cable like this is to order a couple of 2x5 pin IDC cable (usually listed as *AVR* or *JTAG* cable) with sufficient length, cut off the end you don't need and then attach a female DB9 connector of the IDC variety. Pre-made cables have been observed on ebay, but have not seen any that are more than 20cm in length.

****) You'll need to determine for yourself which connectors you'll need to install. Though I prefer the JST-XH sockets as indicated on the silkscreen, these may be substituted with standard straight pin headers instead - the reason to use them is mainly just because they are what seems to be used with most of the cheap Sanwa-cloned arcade kits that I've looked at. You'll probably only need the one 5-pin socket, the choice between the two is whether you prefer to mount the stick on the left or the right side of the arcade stick. 

## 2.1 Adapters
The necessity for adapters will depend on the type of systems that you have, so I've separated the BOM for those into separate modules. See document [adapters](https://github.com/tebl/C64-JoyKEY/blob/main/documentation/adapters.md) for a list of available and tested adapters, click on the ones you are interested in to get a BOM for those.

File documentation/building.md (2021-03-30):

# Building C64 JoyKEY

Congratulations on the taking the leap to build my slightly over-complicated 7-key keyboard/joystick, now probably compatible with most of your favourite vintage computers. It can be built or configured in a few ways, so take a look at the [configuration](https://github.com/tebl/C64-JoyKEY/blob/main/documentation/configuration.md) document so that you'll have an idea of what you want to do with it - pay particular mention to whether you'd require any of the features provided by the Arduino Pro Micro and which of the separate adapters you will need. 

- [1> Building C64 JoyKEY](#1-building-c64-joykey)
  - [1.1> Ordering components](#11-ordering-components)
  - [1.2> Soldering it together](#12-soldering-it-together)
  - [1.3> Assembling the parts](#13-assembling-the-parts)
  - [1.4> Building the cables](#14-building-the-cables)
  - [1.5> All done](#15-all-done)
- [2> BOM](#bom)
  - [2.1> Adapters](#21-adapters)

## 1.1> Ordering components
The first step in building it, is what you've already done - figuring out what you wanted out of it in the first place! The second step is taking stock of which parts you don't already have, check out the [BOM](#BOM) (*Bill of Manufacturing*) below for a somewhat detailed of everything I used when building the prototype. Note that any adapters you'll want will have their own BOM.

You should be able to get most from the more reputable electronic component oligopolists, but because of extreme import fees where I live - those are for the most part not an option for me (I can't afford to pay €40 worth of fees to get €10 worth of parts at ten times the cost). What I do instead is order most things from ebay and AliExpress, you'll have to do a bit more of guesswork to find the correct parts - additionally, delivery times are most probaly to be counted in number of weeks and not days. 

My best suggestion on getting what you need the first time, is to use the search function and start with the description I've added, compare it to the pictures and order whichever looks to be the closest - if it's a cheap part, just get a few different ones! Pin headers usually come in 40-pin strips, both dual row and single row ones will be needed - add some right-angle ones as well (you'll just break off what you need). For some parts such as  common resistor values, M3 nylon hex standoffs and switches it might be preferable to get a kit instead of the specific kind (the are usually referred to as a parts kit "*assortment*").

Order what you need, set the components aside until you're ready to start assembling things.

## 1.2> Soldering it together
When ready to start soldering things into place, start by installing the physically smaller parts such as the resistors then move on up vertically to the taller parts in order to make things easier on yourself. Note that if you intend to install the underglow LEDs, these should be soldered onto the board after the Cherry MX switches (the longest LED pin goes into the round hole). The actual Cherry MX switches themselves will usually take a bit of force to get into place, so make sure to push them firmly into place before finally soldering them permanently into place (removing solder is a **lot** harder to remove than it is to add it, so it is a good idea to check alignment more than once).

Arduino Pro Micro variants

The Arduino Pro Micro unfortunately seem to come in physically different variations, the ones most common seem to be the ones shown above (at least those are the two I have, the black DIYmore branded unit is recommended for purely aesthetic reasons) - the *C64 JoyKEY* can use either of these, but you need to align it so that the pins are soldered in the correct place so do a bit of dry-fitting **before** commiting. The switch below it is needed if you accidentally try to flash it using the wrong settings in *Arduino Studio*, there is a separate page that details how to deal with the [firmware](https://github.com/tebl/C64-JoyKEY/blob/main/documentation/firmware.md).

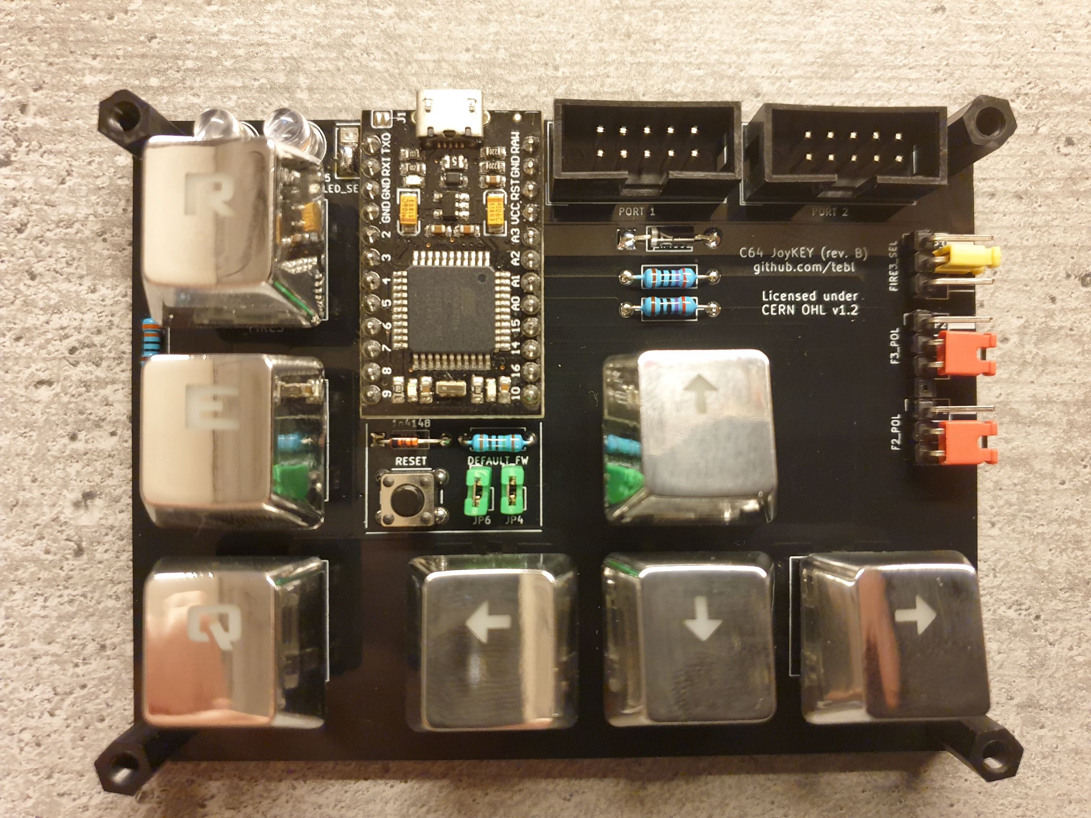
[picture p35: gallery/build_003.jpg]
C64 JoyKEY board


Notice the spot for two jumpers marked **DEFAULT_FW** (green in the picture above)? You'll need to add solder a piece of wire here, the leftovers you got when snipping the leads from the resistors can be used for this purpose. You need to do this even if you don't want the Arduino at all, the only reason not to do so is if you specifically want to use the autofire variant of the firmware instead. Installing pin headers here may lead to accidents as well as increase the required space between the module and faceplate. The same goes for the power links marked **VCC_EN** and **ARD_EN**. It may be tempting to install male pin headers and jumper caps here, but note that this would be a little too tall to fit under the faceplate - if you want them, you can either sand a bit off the top of the jumper caps or use some pliers to pull off the base of the pin headers (snip off a bit of the pins as well).

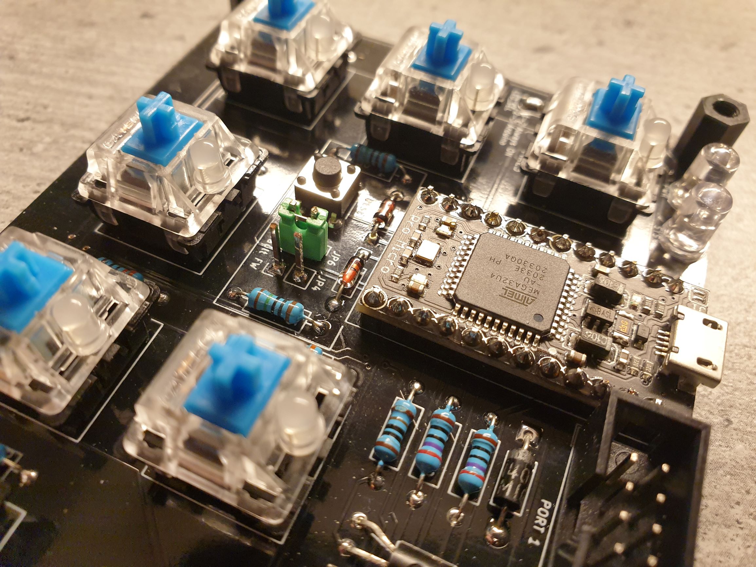
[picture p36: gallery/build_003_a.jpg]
Shorter jumpers


Next you'll want to screw together both pieces of PCBs, just put the female HEX standoffs of the size you want between them and add screws from both sides - this should make the whole thing stand up to some abuse (physical, not the MS-DOS game though you could try that one out later in DOSBOX). 

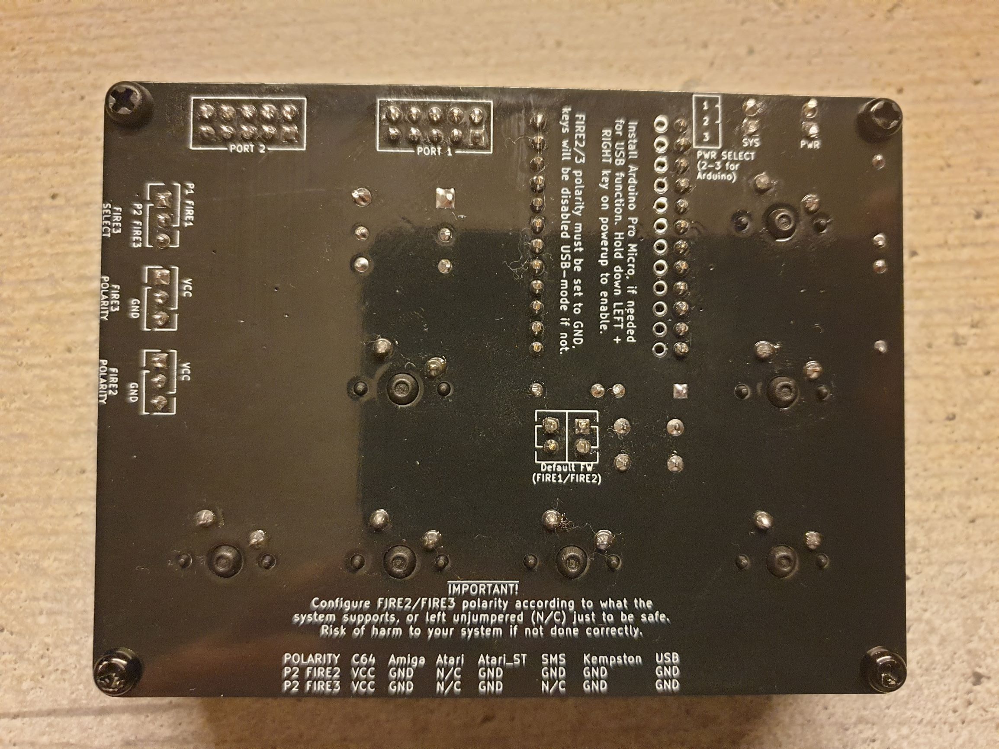
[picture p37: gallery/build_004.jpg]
C64 JoyKEY underside


Given that this is a PCB you'll be handling directly, it is probably a good idea to clean the flux residue left from soldering the connection points. It probably won't be very toxic, but depending on how much you spent on the solder you never know (China isn't exactly known for focusing on employee health and safety) - it is however a very sticky substance, so at the very least it's pretty annoying. It can be cleaned by pouring isopropyl alcohol (*IPA*), sometimes sold as contact cleaner or rubbing alcohol, over the board and scrubbing it with an old toothbrush to dissolve it evenly. You'll now have an evenly super-sticky board, but do **NOT** panic if this happens! Next step is to put some cloth over the board, pour more more *IPA* over the cloth and allow it to soak through to the board and rub it gently - when the alcohol has mostly evaporated, the stickyness should now be on the cloth instead. Phew!

## 1.3> Assembling the parts
Push the MX keycaps onto the top of the MX-switches, again you'll need to use a bit of careful force. You should now have a mostly completed unit, a recommended addition is to add some 3M bumpon adhesive rubber feet to the button - these are mostly there to keep the PCB from sliding around on your desk, but also keeps the solder points from scratching up your desk.

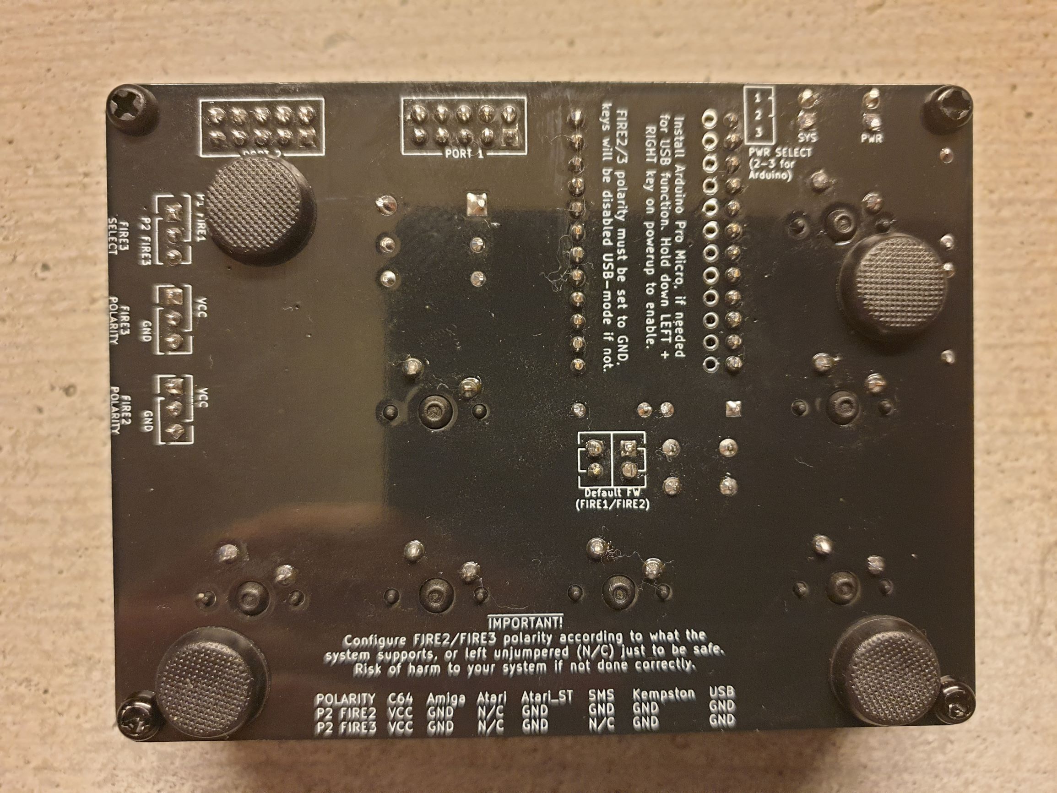
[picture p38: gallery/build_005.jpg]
3M Bumpon placement


Those wanting to do a more complete build of the unit will probably have opted for the faceplate as well, it does not have any active (or passive components either) and is mostly just there to give the whole unit some added sturdyness. Both PCBs are screwed together using M3 hex spacers as well as screws to go with them, you can also use some of the nuts instead - if you got the *M3 nylon hex standoff kit* I recommended as part of the *BOM*. The space between needs to match the components you've installed on the module, to my eyes the 9mm ones look the best - though the 10mm ones seem to be a lot more commonly available on ebay (it's also in the kit). 8mm can also be used, but you'll need to install shorter LEDs (the kind listed as *5mm flat top LED* or *5mm straw hat LED*).

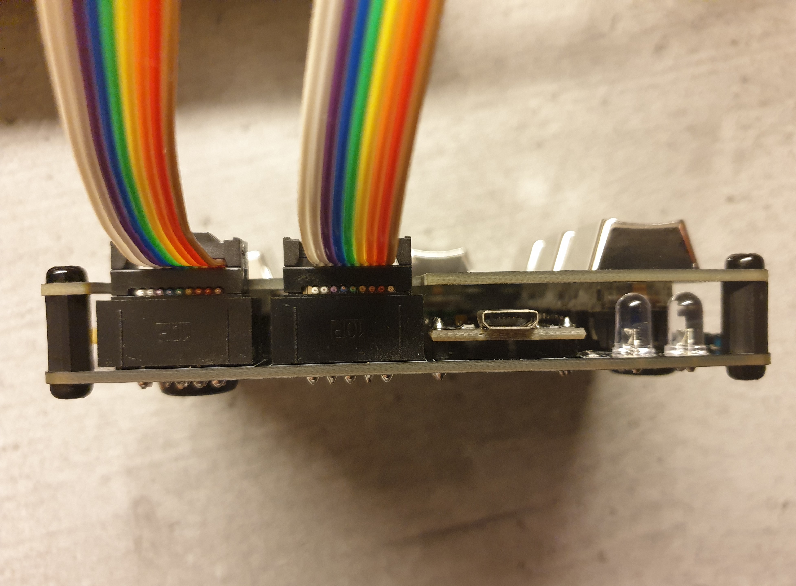
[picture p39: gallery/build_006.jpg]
Module sideview

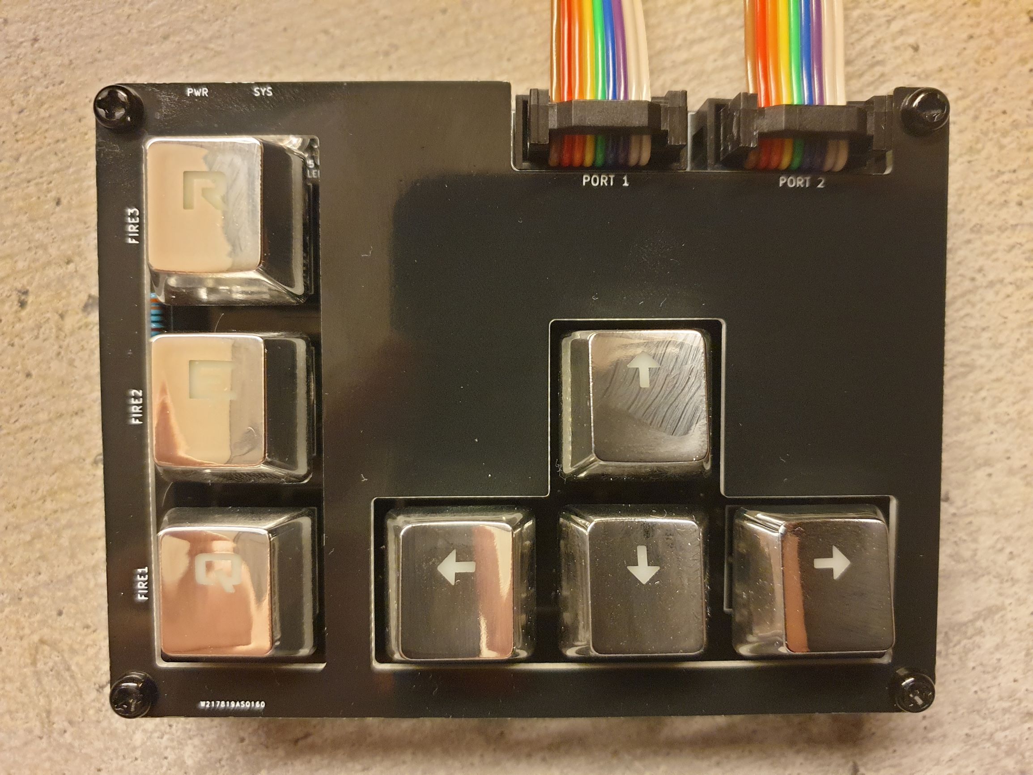
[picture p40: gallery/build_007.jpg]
Faceplate installed


## 1.4> Building the cables
The last step is putting together some cables for your most common vintage systems, but if you only want to use it as a USB device then feel free to skip this step. Still here? Awesome.

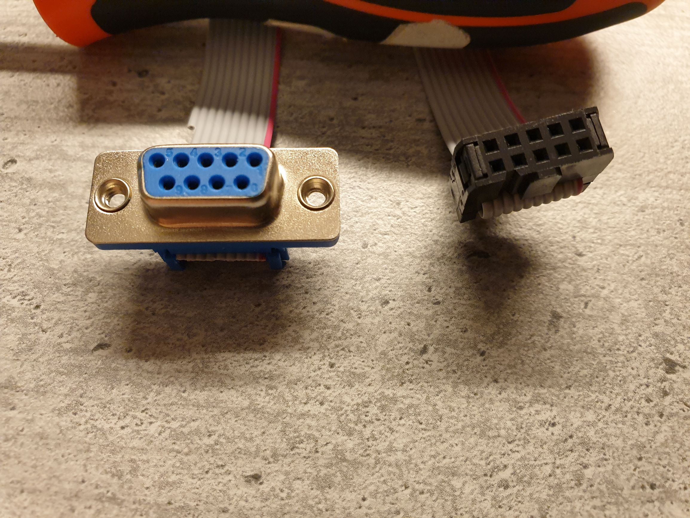
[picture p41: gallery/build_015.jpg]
IDC to female DB9 cable


Soldering connectors is hard if you do it the hard way - the easiest way to get a cable suitable for use with *C64 JoyKEY* is adapting an existing cable. The ones I've used are usually listed as 2x5 pin *AVR* or *JTAG* cable, just cut off the end that doesn't fit into the board properly - the red stripe should be on the left side when plugging it into the board. The picture above should make things a bit easier to decipher, note that the 10th wire has been removed as it is not needed (only 9 pins on the DB9). The connectors I've used are described as female DB9 IDC, it is installed by lining up the red wire with pin 1 and pushing the clamp into place until you hear a click (a vice is helpful, that way you don't need to buy dedicated IDC connector tools).

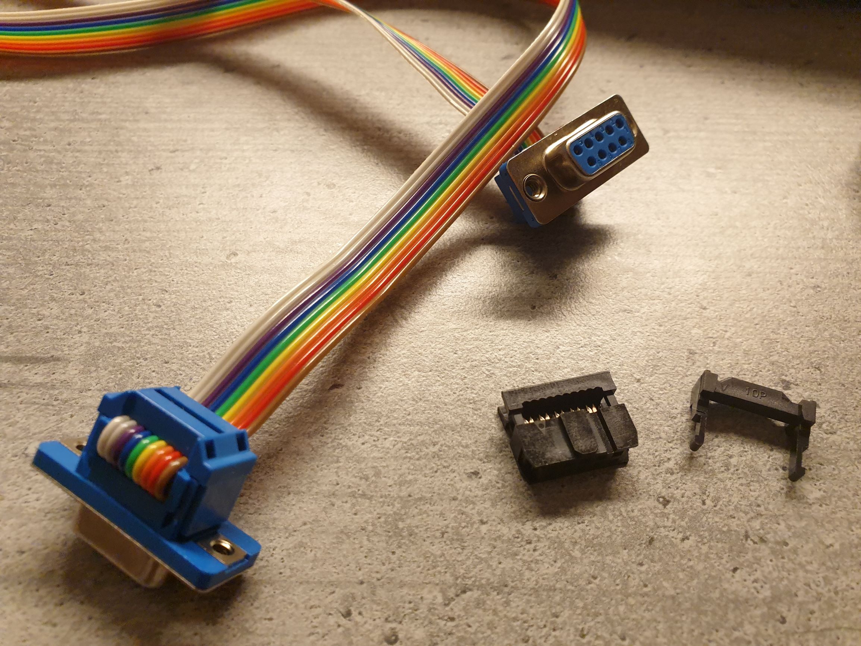
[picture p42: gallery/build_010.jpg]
IDB9 female-female cable with connector


I also bought some cables described *DB9 female to female cable d-sub* on AliExpress, these come with the DB9-side of the cable and you'll have to attach some 2x5 pin IDC connector instead - make sure to cut off the side you don't want (both'll work, the difference is if you want the cable pointing up or down when connected to the C64).

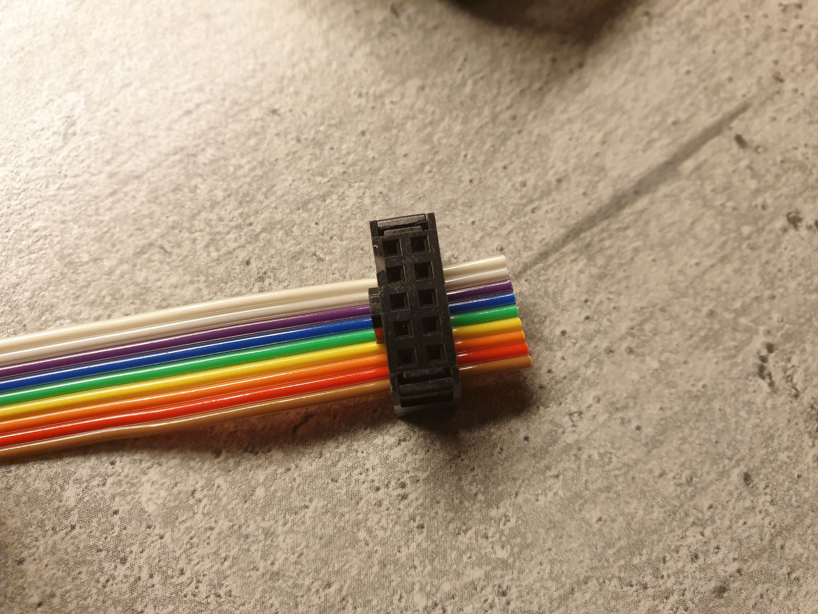
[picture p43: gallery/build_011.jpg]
Crimp

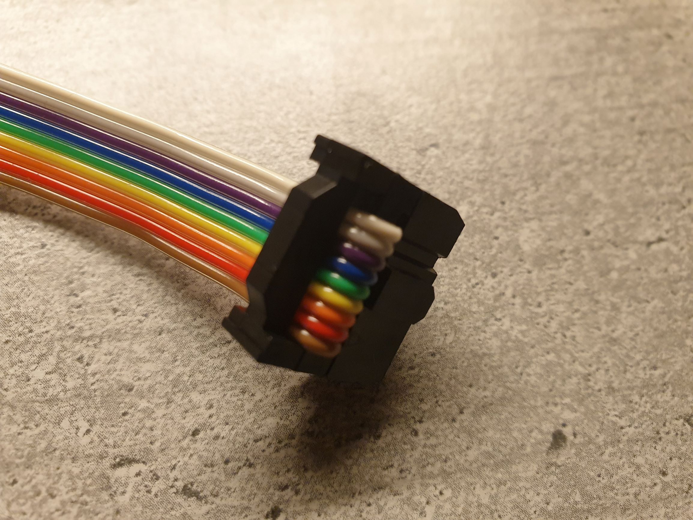
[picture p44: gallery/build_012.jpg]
Added strain relief


The IDC connector comes with two parts, just make sure to align pin 1 on both sides (there'll be a blank space on the right side as we only have 9 cables instead of 10). Align the cable the wrong way, then clamp it into place by pushing very hard against a table etc. Trim the short end and wrap the cable over the top, finally - attach the strain relief clip and push it into place.

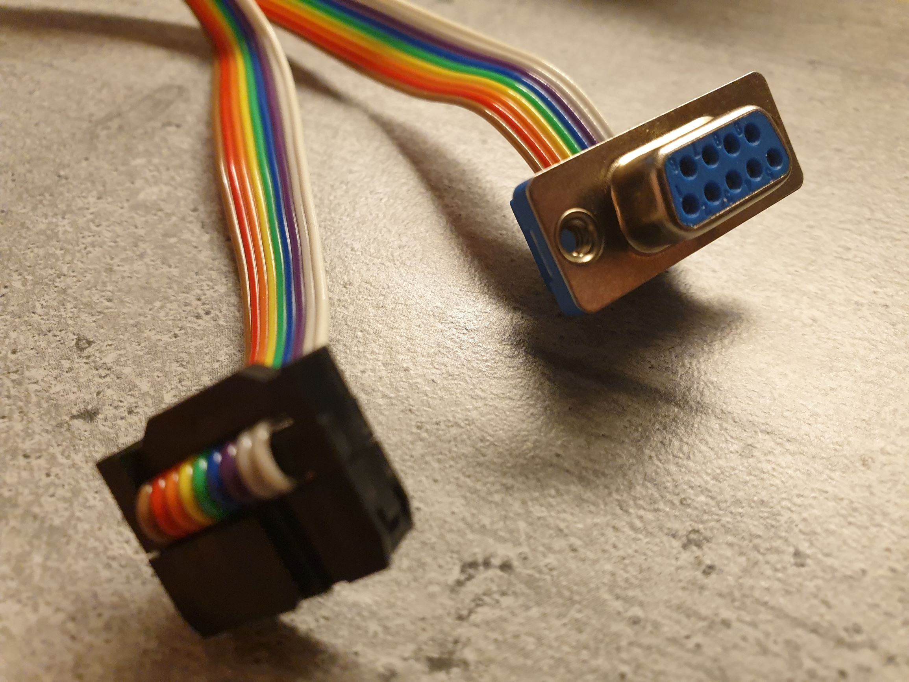
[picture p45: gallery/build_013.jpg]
Completed cable


If you're going to be playing on the *Commodore 64* or *Commodore Amiga*, you'll probably want two of these cables for a selection of games - so, feel free to build yet another cable. 

## 1.5> All done
That should be most of the information you'll need. Head on over to the [configuration](https://github.com/tebl/C64-JoyKEY/blob/main/documentation/configuration.md) page to ensure that you have the jumpers set up correctly before actually connecting it to something (configuration for Commodore 64 shown below). Check out the [firmware](https://github.com/tebl/C64-JoyKEY/blob/main/documentation/firmware.md) page if you installed an Arduino Pro Micro and need some ready-made code for it.

C64 Configuration

# 2> BOM
This section attempts to maintain a list of the parts you'd need in order to build a feature-complete *C64 JoyKEY*, any parts that you could potentially do without have part counts listed in parenthesis. You will find all tested PCBs including on [PCBWay shared projects](https://www.pcbway.com/project/shareproject/?tag=C64%20JoyKEY) relation to this project, this will also include any [adapters](https://github.com/tebl/C64-JoyKEY/blob/main/documentation/adapters.md) - if you should need them. See [faceplates](https://github.com/tebl/C64-JoyKEY/blob/main/documentation/faceplates.md) for some more information on those.

| Reference | Item | Count | Order  |
| --- | --- | ----- | --- |
| PCB | Fabricate using Gerber files | 1 | [PCBway](https://www.pcbway.com/project/shareproject/C64_JoyKEY__Module_.html)  |
| PCB Faceplate A1 | Fabricate using Gerber files | (1)| [PCBway](https://www.pcbway.com/project/shareproject/C64_JoyKEY_Faceplate.html) |
| A1 | Arduino Pro Micro | (1)| |
| | 12-pin straight pin header | (2)| |
| D1,D2 | 5mm LED | (2)| |
| D3 ** | 1N4001 diode DO-41 | (1)| |
| D4 | 1n4148 diode DO-35 | (1)| |
| D5-D11 * | 3mm or 2x3x4mm LED | (7)| |
| J1,J2 *** | 2x5 pin straight header pins or 2x5 IDC | 2 | |
| | 2x5 pin IDC to female DB9 cable | 1 (1) | |
| JP1-JP3 | 3-pin right-angle header pins | 3 | |
| Q1 * | 2N3904 (TO-92) | (1)| |
| R1,R2 | 270 ohm resistor | 2 | |
| R3,R4 | 220 ohm resistor | (2)| |
| R5,R14-R21 | 10k ohm resistor | (9)| |
| R6,R12 | 330 ohm resistor | (7)| |
| R13 | 1k ohm resistor | (1)| |
| SW1-SW7 **** | Cherry MX compatible switch (green) | 7 | |
| | MX compatible 1u blank keycaps | 7 | |
| SW8 | Tactile momentary switch 6x6x6mm | (1)| |
| | 3M bumpon adhesive rubber feet | (4)| |
| | Nylon M3 hex standoffs 8mm | (4)| |
| | Nylon M3 screws | (8)| |

*) These are components exclusively used by the underglow LEDs, these are there to light up the keycaps and serve no other function than looking cool. As noted below you'll need key switches with an opening for installing these, the Gateron brand switches I tested usually do. You'll need either 3mm LEDs, 2x3x4mm LEDs should also fit rather nicely.

**) Replace with piece of wire if not installing Arduino Pro Micro on the board, or you know you won't need the alternative autofire firmware at any point.

***) Breakable dual row pin headers can be used here, but I find it is nicer to use a 2x5 pin connector here instead. The easiest way to get a cable like this is to order a couple of 2x5 pin IDC cable (usually listed as *AVR* or *JTAG* cable) with sufficient length, cut off the end you don't need and then attach a female DB9 connector of the IDC variety. Pre-made cables have been observed on ebay, but have not seen any that are more than 20cm in length.

****) I've been using the cheaper Gateron clones and they work well for this type of use, you can use either the 3- or 5-pin variety. The green and blue switches are the ones that have a clicky sound, pick a different colour if that is not something you'd be interested in. If you want LEDs below the keycaps, you need switches with a spot for those like the Gateron brands do. The keycaps you need are usually listed as *mechanical gaming MX-compatible keycaps*.

## 2.1 Adapters
The necessity for adapters will depend on the type of systems that you have, so I've separated the BOM for those into separate modules. See document [adapters](https://github.com/tebl/C64-JoyKEY/blob/main/documentation/adapters.md) for a list of available and tested adapters, click on the ones you are interested in to get a BOM for those.

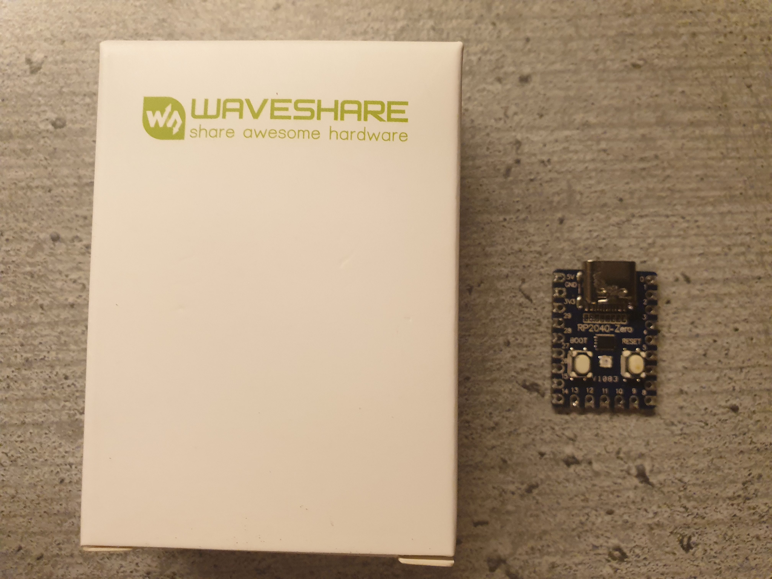
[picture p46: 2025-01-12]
gallery/build/adapter9_2040/005.jpg

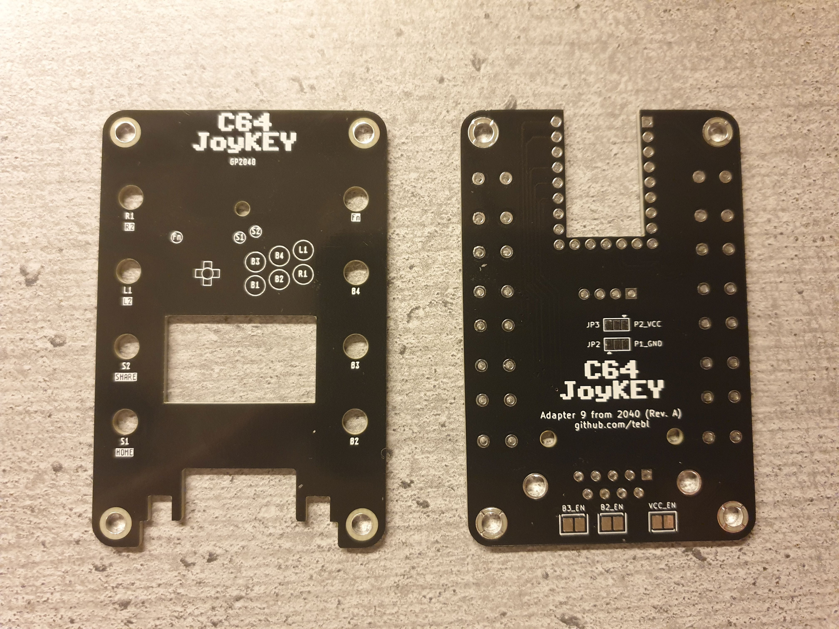
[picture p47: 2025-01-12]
gallery/build/adapter9_2040/002.jpg

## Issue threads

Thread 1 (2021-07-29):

Not an issue, just a question...

Shadowtrance, 2021-07-29:
Just got some of these boards made to use with my c64 and such, nice little creation. :)

Oddly enough, amongst all my parts I have zero 270 ohm resistors anywhere, 220 and 360 are probably the closest I have on hand. haha

Is there any other value I can safely use in their place? or can I just omit them totally until I get some?

Also got your Pi1541 hat made too which works a treat. :)

tebl, 2021-07-29:
They are just there in order to somewhat protect the computer in case the
polarity haven't been set up to match, a 220 resistor would probably work
just the same. A wire would also work though it would offer no "failsafe".

tor. 29. jul. 2021, 14:41 skrev Shadowtrance ***@***.***>:

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

Closed 2021-08-04.

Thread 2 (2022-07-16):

Underglow LED without arduino.

Retrofletch, 2022-07-16:
i noticed that because the arduino controls the underglow led's there will be no keycap light when not using the arduino.

I figured out that its basicly just sending vcc to the base pin of the transistor thru a 1k resistor so linking any VCC to R13 makes it work, is there any better way of doing this? or any technical reason why i should not solve it that way?

( i have the version before you added the 3 push buttons at bottom left )

thanks /Fletch

tebl, 2022-07-16:
I think it depends on whether the Arduino is installed at all, but I think
the easiest is probably removing Q1 entirely, then adding a short wire
between pins 1 and 3 (that way you can still remove KEY-LED jumper to
disable it when needed). If the LEDs are too bright, use a resistor instead
of the wire.

lør. 16. jul. 2022, 12:17 skrev RetroFletch ***@***.***>:

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

Retrofletch, 2022-07-16:
Will try that on the next build, thanks

Closed 2022-08-01.

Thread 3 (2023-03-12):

Missing libraries

wins4, 2023-03-12:
Hi,

I recently built the circuit. I also tried to program my arduino pro micro. Unfortunately I can't because some h-files are missing, e.g. the joystick.h. led.h etc. Would you be so kind to publish the missing libs?

Regards,
Achim

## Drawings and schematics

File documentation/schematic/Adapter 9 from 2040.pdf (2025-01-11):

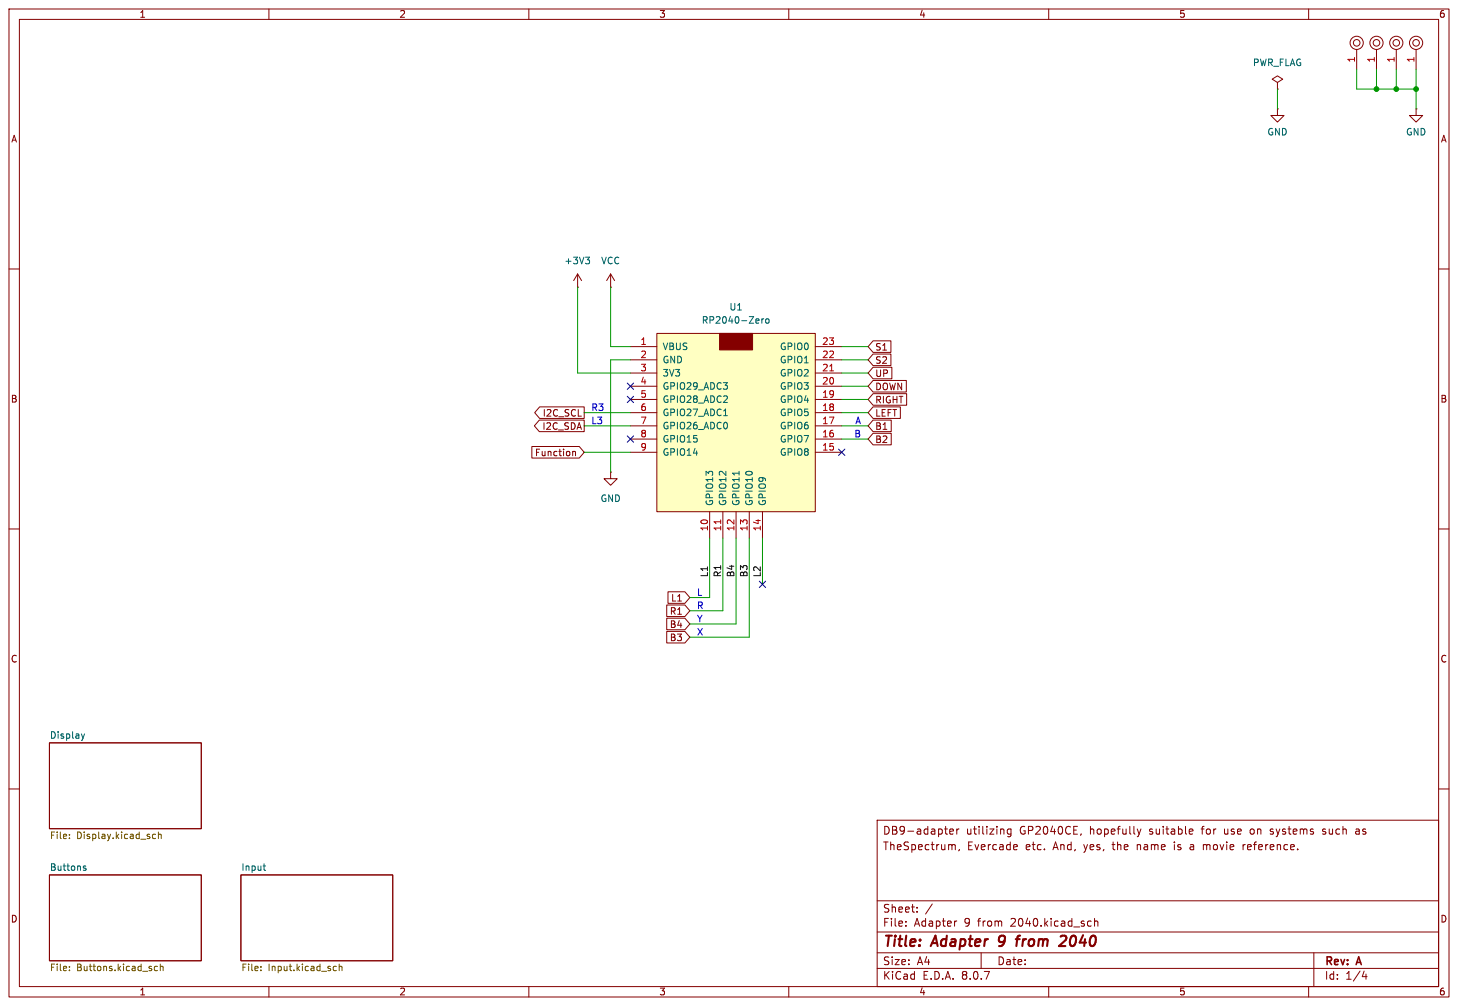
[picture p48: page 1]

Input File: Input.kicad_sch Buttons File: Buttons.kicad_sch Display File: Display.kicad_sch

Id: 1/4 Title: Adapter 9 from 2040

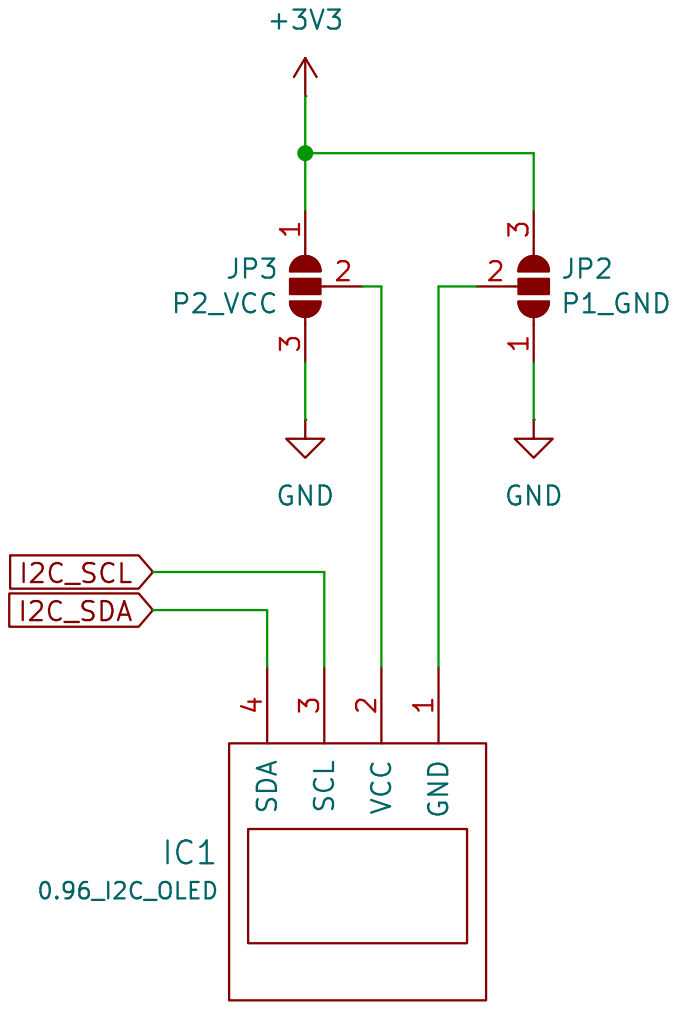
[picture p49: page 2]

Id: 4/4 Title: File: Display.kicad_sch Sheet: /Display/

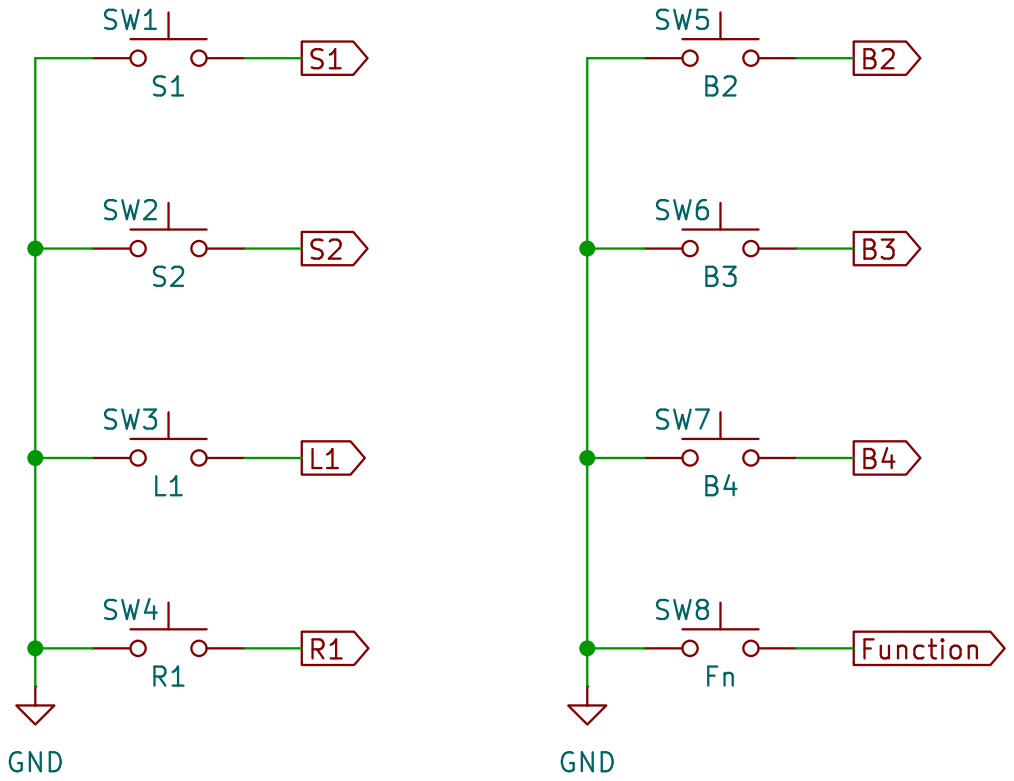
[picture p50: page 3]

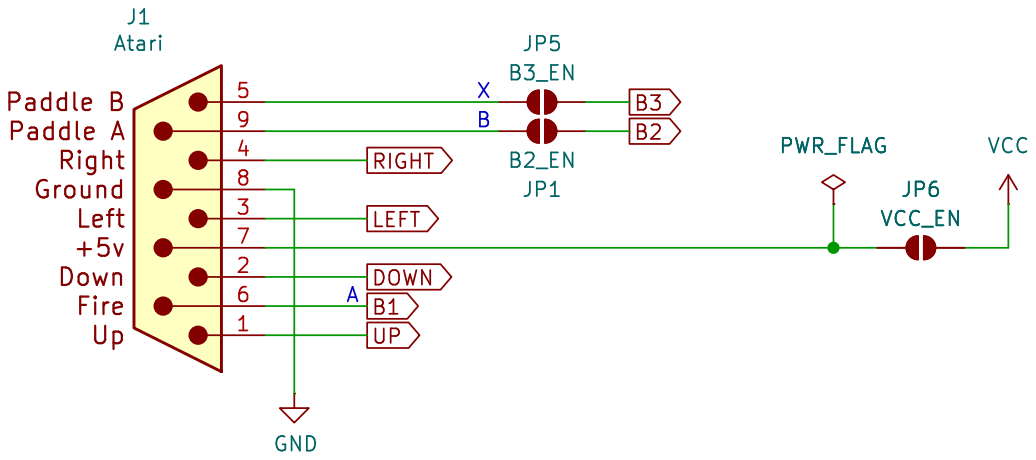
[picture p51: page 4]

Id: 4/4 Title: File: Input.kicad_sch Sheet: /Input/

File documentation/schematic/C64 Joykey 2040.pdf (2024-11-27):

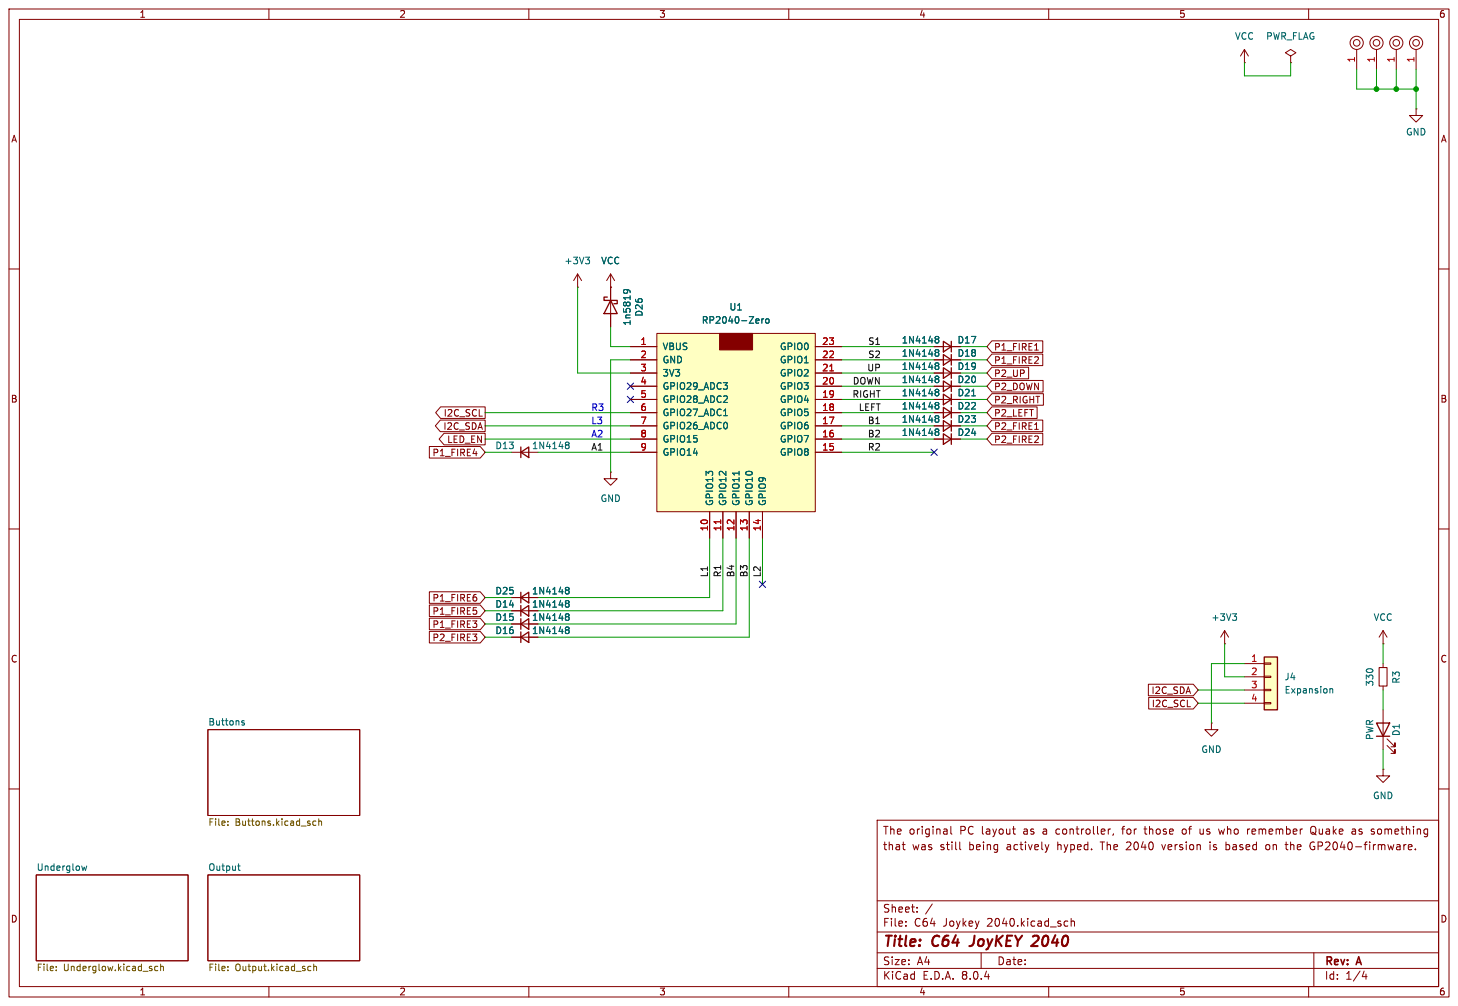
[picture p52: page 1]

Output File: Output.kicad_sch Buttons File: Buttons.kicad_sch Underglow

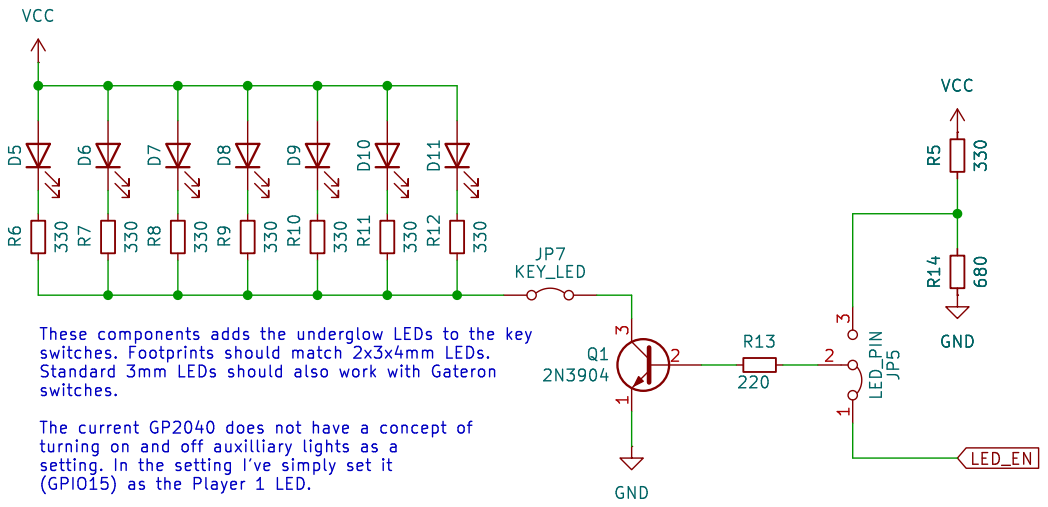
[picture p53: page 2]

switches. The current GP2040 does not have a concept of

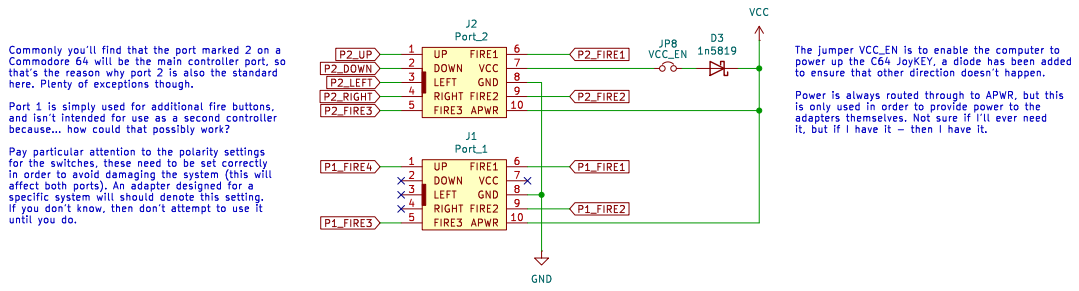
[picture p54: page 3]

power up the C64 JoyKEY, a diode has been added

that's the reason why port 2 is also the standard

is only used in order to provide power to the
it, but if I have it - then I have it.

Id: 3/4 Title: File: Output.kicad_sch Sheet: /Output/

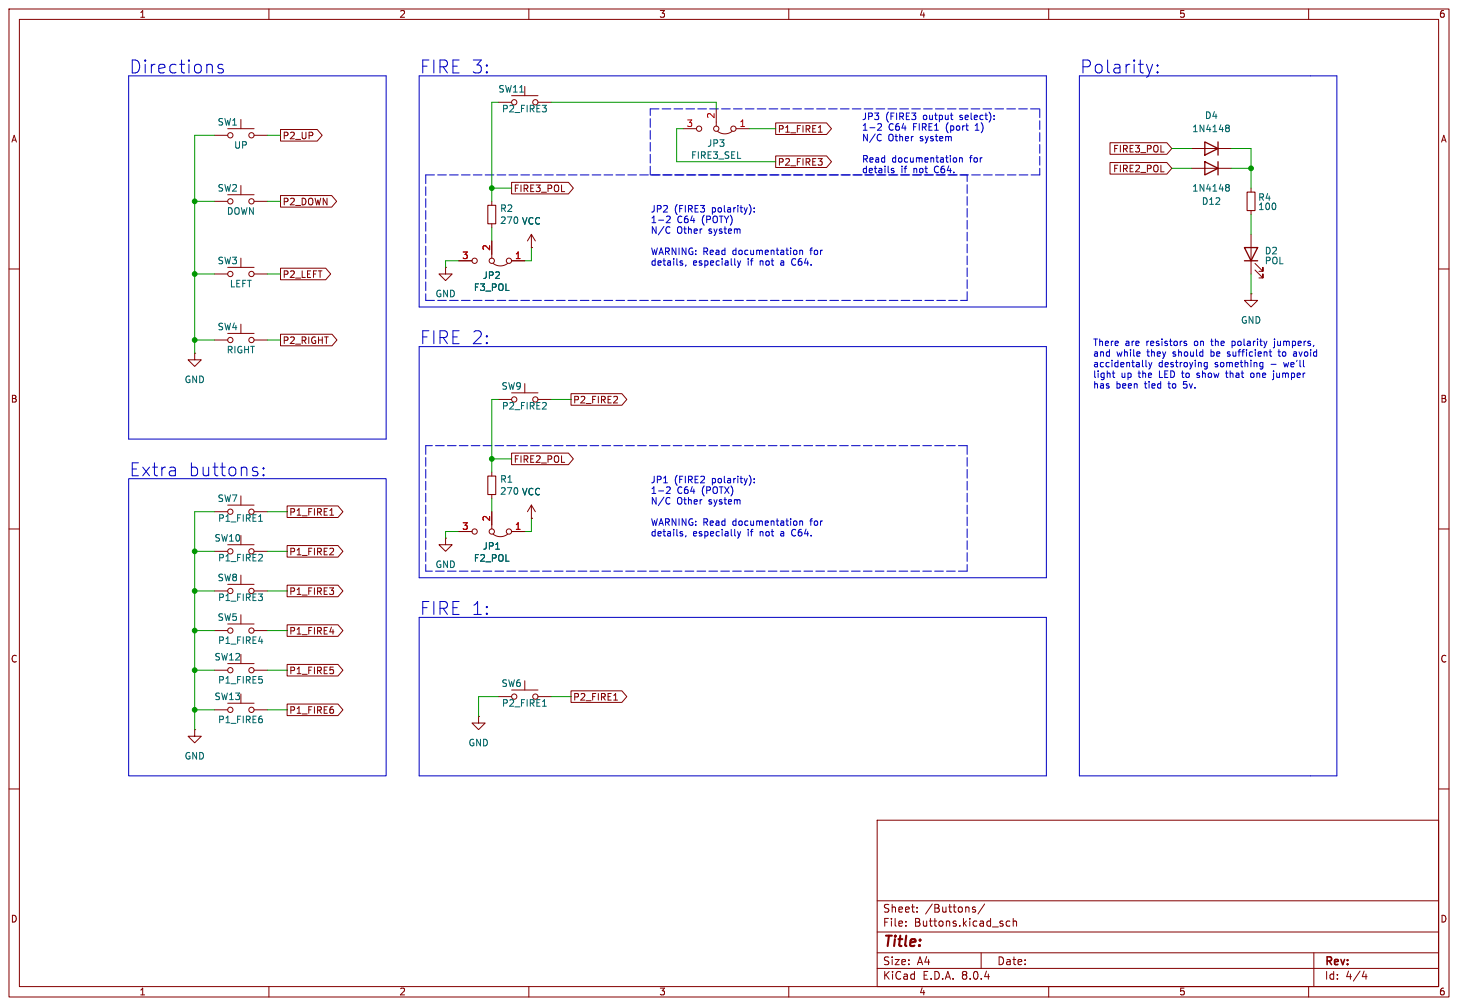
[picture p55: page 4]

light up the LED to show that one jumper has been tied to 5v. Directions

Id: 4/4 Title: File: Buttons.kicad_sch Sheet: /Buttons/ R1

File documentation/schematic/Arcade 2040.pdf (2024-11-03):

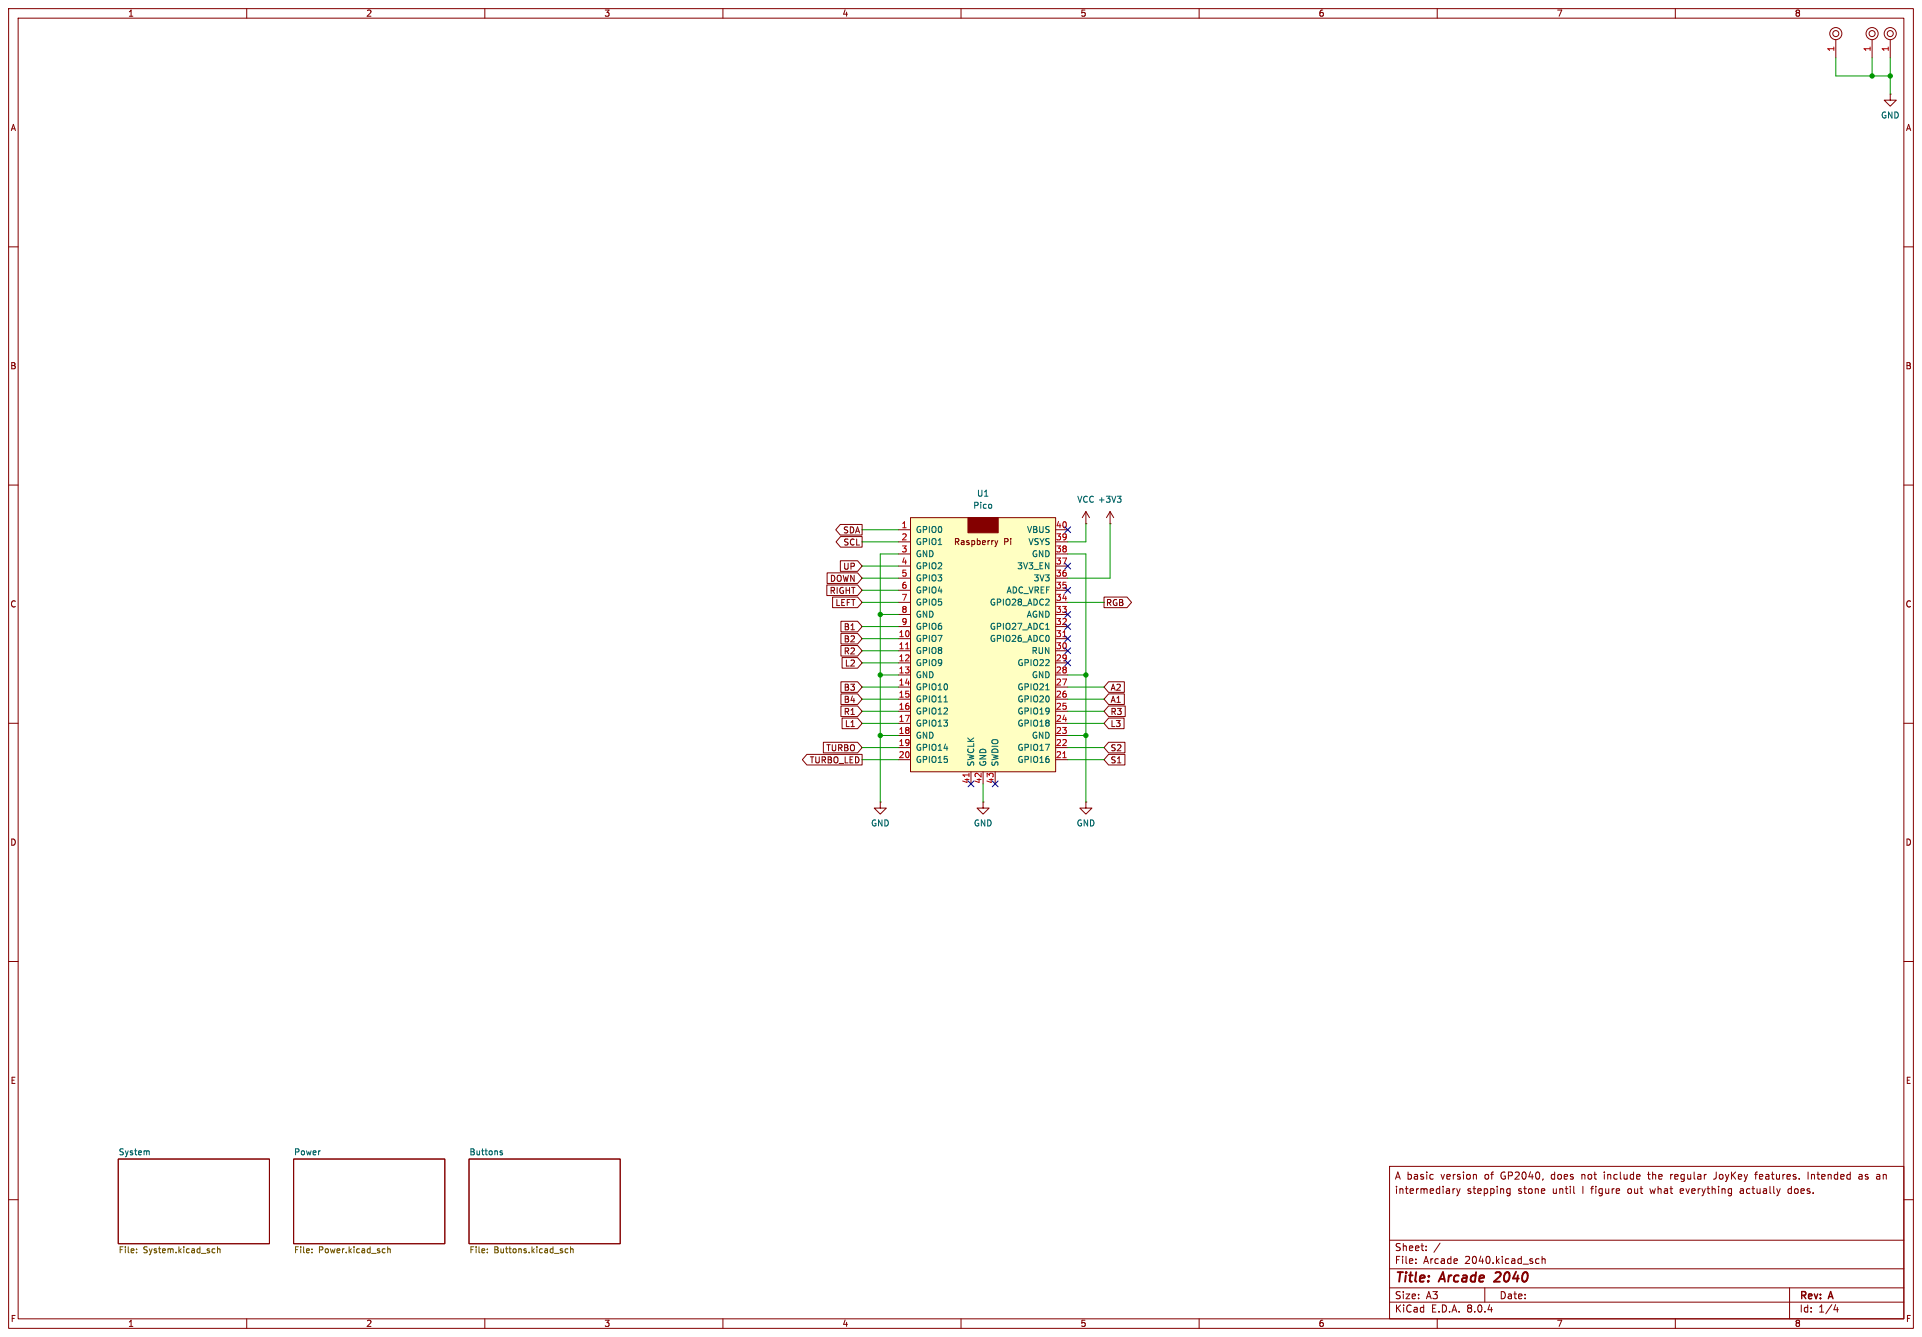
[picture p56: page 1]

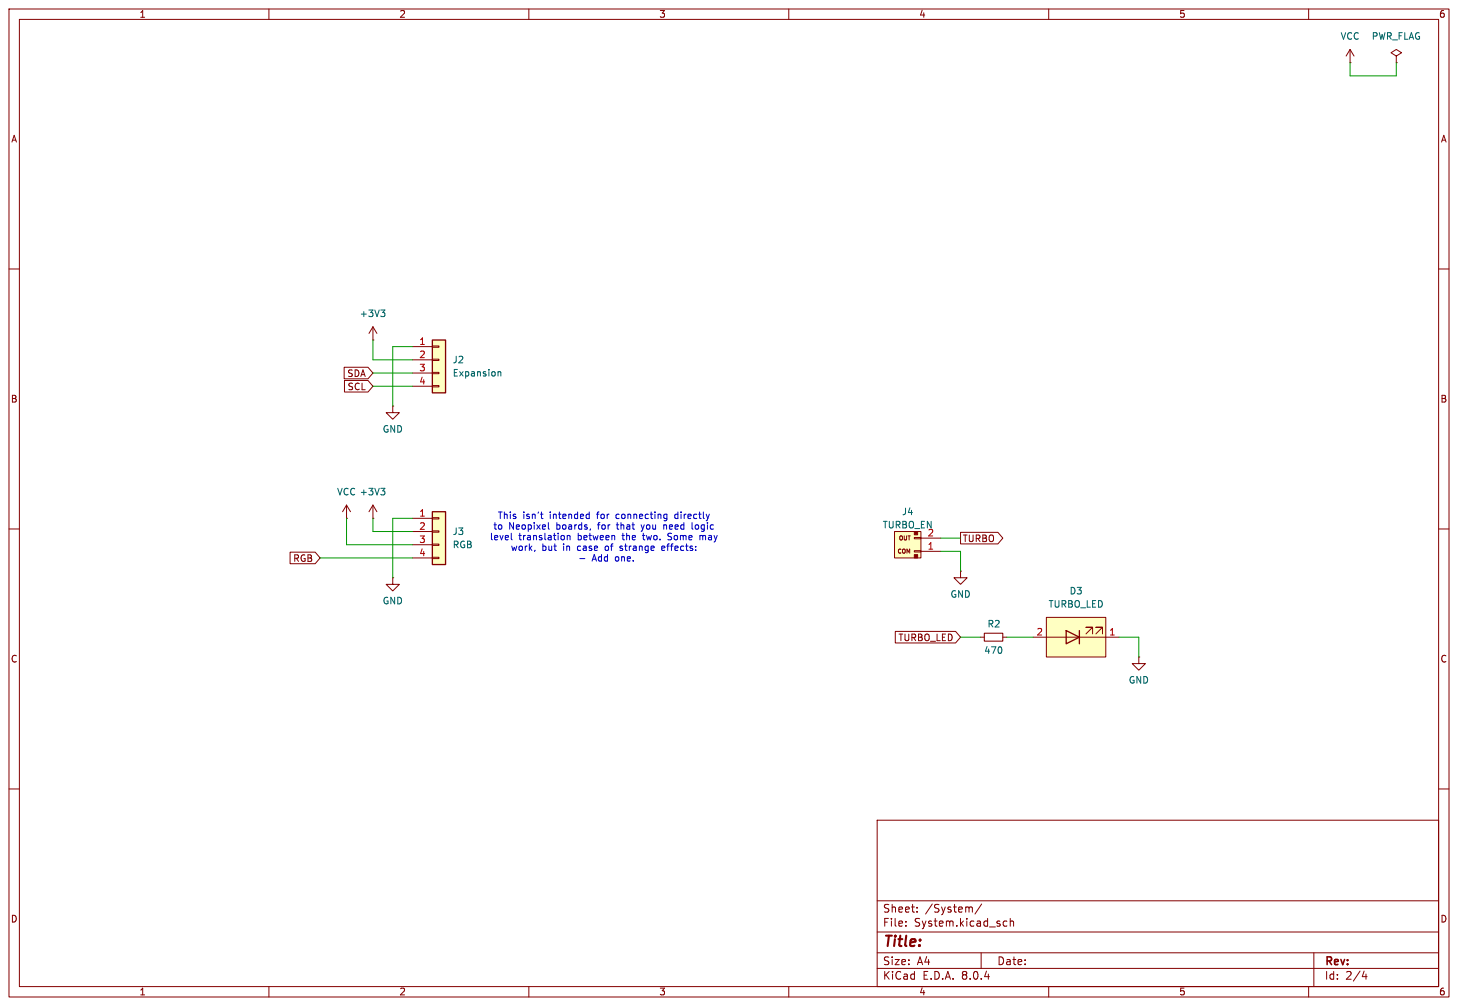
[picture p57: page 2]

to Neopixel boards, for that you need logic

Id: 2/4 Title: File: System.kicad_sch Sheet: /System/ GND

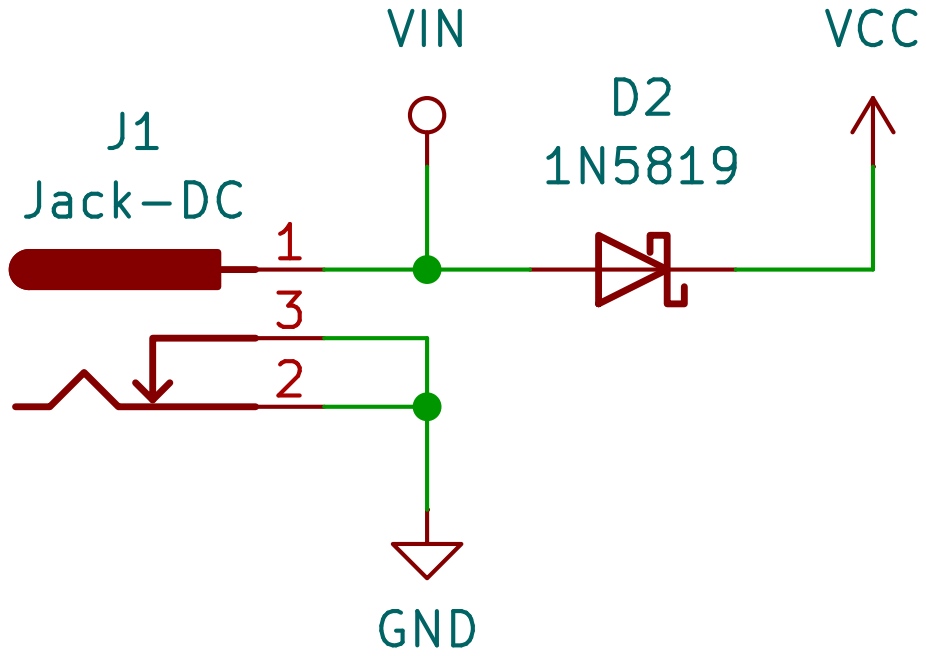
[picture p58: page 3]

Id: 3/4 Title: File: Power.kicad_sch Sheet: /Power/

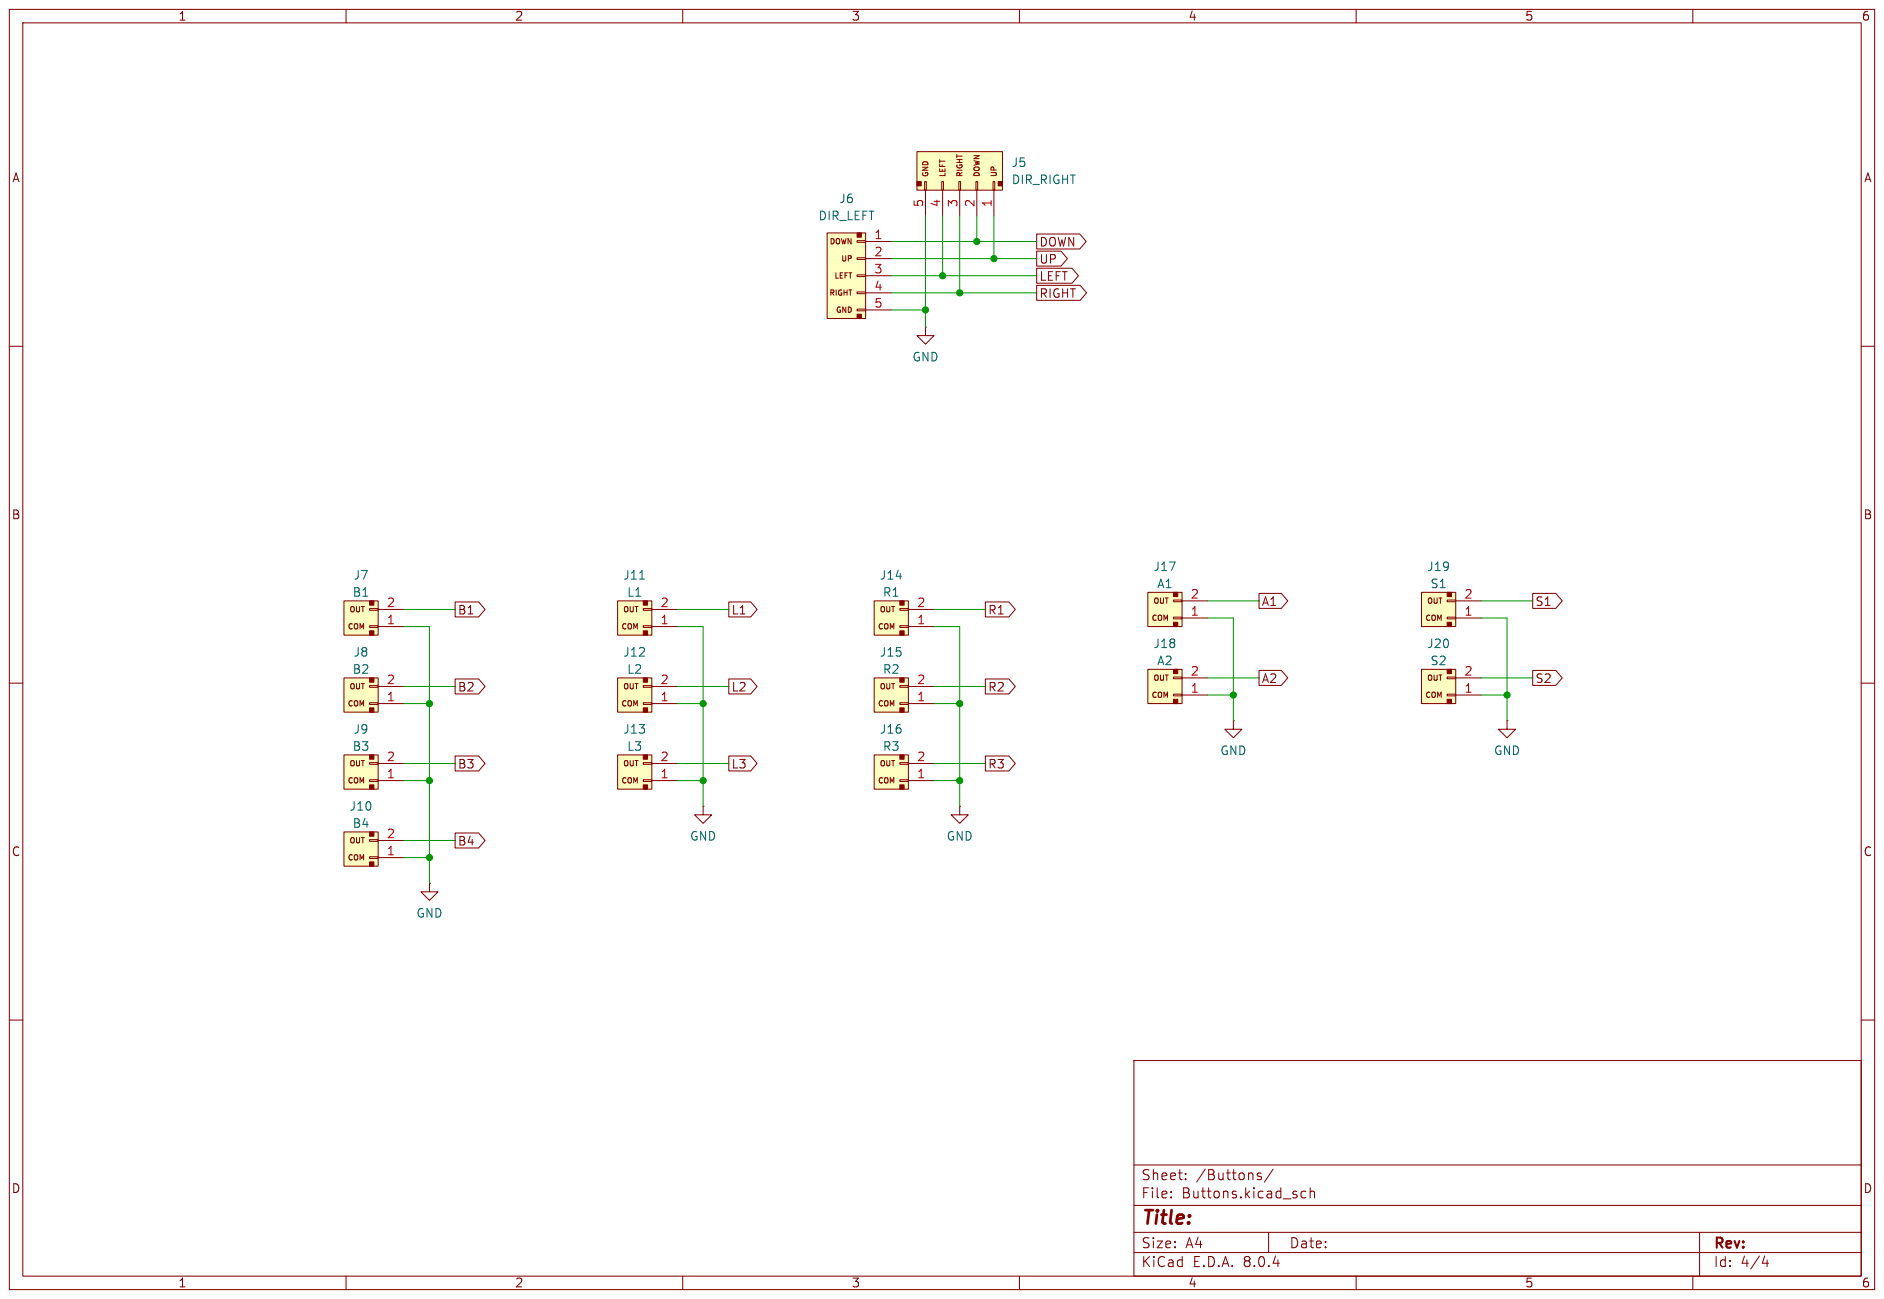
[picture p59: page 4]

Id: 4/4 Title: File: Buttons.kicad_sch Sheet: /Buttons/ GND

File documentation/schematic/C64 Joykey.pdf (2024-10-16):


(this is by design).

File: C64 Joykey.kicad_sch Sheet: / VCC

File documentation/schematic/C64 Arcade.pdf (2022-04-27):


There will be an alternate Arduino firmware where FIRE2/FIRE3
controls various forms of autofire (for single-button systems). For the default FW or units without an Arduino Pro Micro

Read documentation for details if not C64. JP2 (FIRE3 polarity):

File: C64 Arcade.sch Sheet: / R16 10k R5

Read documentation for details if not C64.

arcade parts instead of Cherry MX switches.

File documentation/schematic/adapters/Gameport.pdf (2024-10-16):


VCC
Analog 4 (Joystick 2 Y-Axis) Button 1 Button 2 Button 3 Button 4 GND GND MIDI RxD MIDI TxD

Rewires the C64 JoyKEY for a 4-button layout suitable for use with PCs with a 15-pin
gameport. While originally a system for analog joysticks, the adoption of gamepads such
File: Gameport.sch Sheet: / *DESIGN IS UNTESTED* as the Gravis gamepad makes this a viable option for many games.

Id: 1/1 Title: Gameport (C64 JoyKEY)

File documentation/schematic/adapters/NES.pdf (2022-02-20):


Transforms the C64 JoyKEY into a gamepad for the Nintendo Entertainment System. R6 1k SW1 START GND GND

Id: 1/1 Title: NES Adapter (C64 JoyKEY) File: NES.sch Sheet: / SELECT is placed on the third fire button, START placed on adapter itself or recent JoyKEY.

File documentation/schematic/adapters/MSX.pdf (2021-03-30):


Rewires the C64 JoyKEY for a 2-button layout suitable for use with MSX-line of +5v Button 1 Button 2 Down Ground

Id: 1/1 Title: MSX (C64 JoyKEY) File: MSX.sch Sheet: / Adapter is untested!

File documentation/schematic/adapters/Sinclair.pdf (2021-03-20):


to change the pinouts (mostly to keep people from buying Atari-style joysticks). Not to be confused with
the Atari-compatible Kempston interfaces.

There are no active components on this, so you may as well just create a dedicated cable with these
changes instead of having a straight-through IDC to DE-9.

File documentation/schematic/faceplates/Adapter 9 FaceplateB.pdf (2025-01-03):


Id: 1/1 Title: Adapter 9 Faceplate B

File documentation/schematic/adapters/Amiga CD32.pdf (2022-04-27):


File: Amiga CD32.sch Sheet: /
Id: 1/1 Title: Amiga CD32 Adapter (C64 JoyKEY)

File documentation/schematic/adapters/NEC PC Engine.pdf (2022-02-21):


File: NEC PC Engine.sch Sheet: /
Id: 1/1 Title: NEC PC Engine Adapter (C64 JoyKEY)

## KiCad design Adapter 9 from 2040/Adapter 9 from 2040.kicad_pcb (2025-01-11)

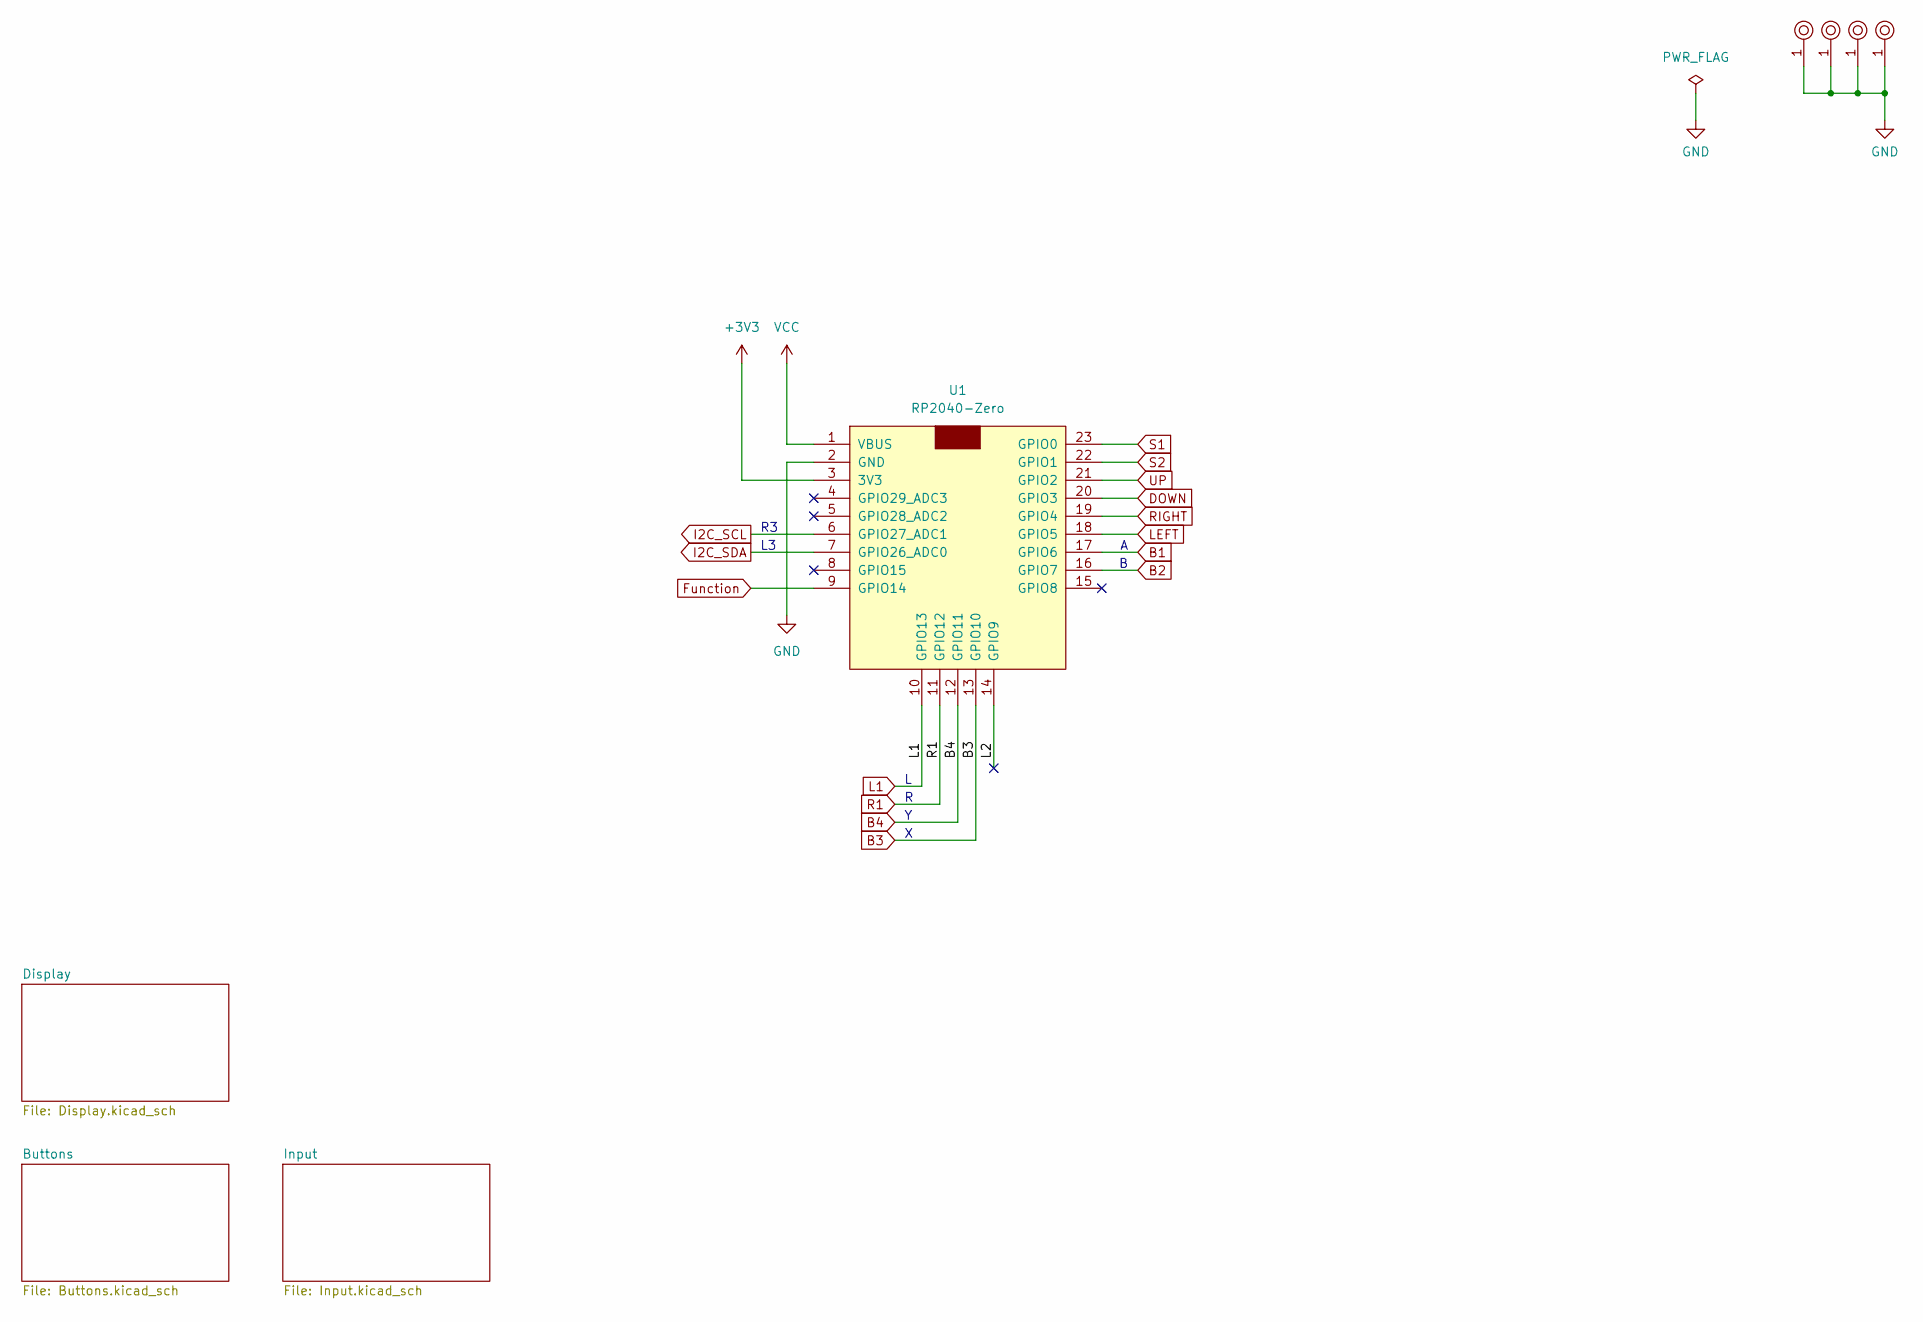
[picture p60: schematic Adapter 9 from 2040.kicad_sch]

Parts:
M1, M2, M3, M4: Mounting; M3_pin
U1: RP2040-Zero; RP2040-Zero_Clean

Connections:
+3V3: U1.3 (3V3); also elsewhere on the board
/L2: U1.14 (GPIO9)
/L2_1: U1.14 (GPIO9)
B1: U1.17 (GPIO6); also elsewhere on the board
B2: U1.16 (GPIO7); also elsewhere on the board
B3: U1.13 (GPIO10); also elsewhere on the board
B4: U1.12 (GPIO11); also elsewhere on the board
DOWN: U1.20 (GPIO3); also elsewhere on the board
Function: U1.9 (GPIO14); also elsewhere on the board
GND: M1.1, M2.1, M3.1, M4.1, U1.2 (GND); also elsewhere on the board
I2C_SCL: U1.6 (GPIO27_ADC1); also elsewhere on the board
I2C_SDA: U1.7 (GPIO26_ADC0); also elsewhere on the board
L1: U1.10 (GPIO13); also elsewhere on the board
LEFT: U1.18 (GPIO5); also elsewhere on the board
R1: U1.11 (GPIO12); also elsewhere on the board
RIGHT: U1.19 (GPIO4); also elsewhere on the board
S1: U1.23 (GPIO0); also elsewhere on the board
S2: U1.22 (GPIO1); also elsewhere on the board
UP: U1.21 (GPIO2); also elsewhere on the board
VCC: U1.1 (VBUS); also elsewhere on the board

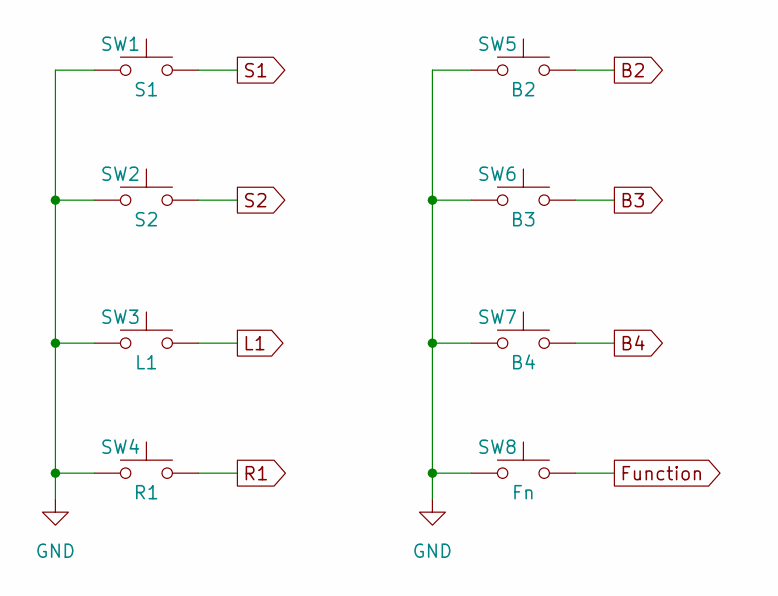
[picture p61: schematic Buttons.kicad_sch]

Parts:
SW1: S1; SW_PUSH_6mm
SW2: S2; SW_PUSH_6mm
SW3: L1; SW_PUSH_6mm
SW4: R1; SW_PUSH_6mm
SW5: B2; SW_PUSH_6mm
SW6: B3; SW_PUSH_6mm
SW7: B4; SW_PUSH_6mm
SW8: Fn; SW_PUSH_6mm

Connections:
B2: SW5.1; also elsewhere on the board
B3: SW6.1; also elsewhere on the board
B4: SW7.1; also elsewhere on the board
Function: SW8.1; also elsewhere on the board
GND: SW1.2, SW2.2, SW3.2, SW4.2, SW5.2, SW6.2, SW7.2, SW8.2; also elsewhere on the board
L1: SW3.1; also elsewhere on the board
R1: SW4.1; also elsewhere on the board
S1: SW1.1; also elsewhere on the board
S2: SW2.1; also elsewhere on the board

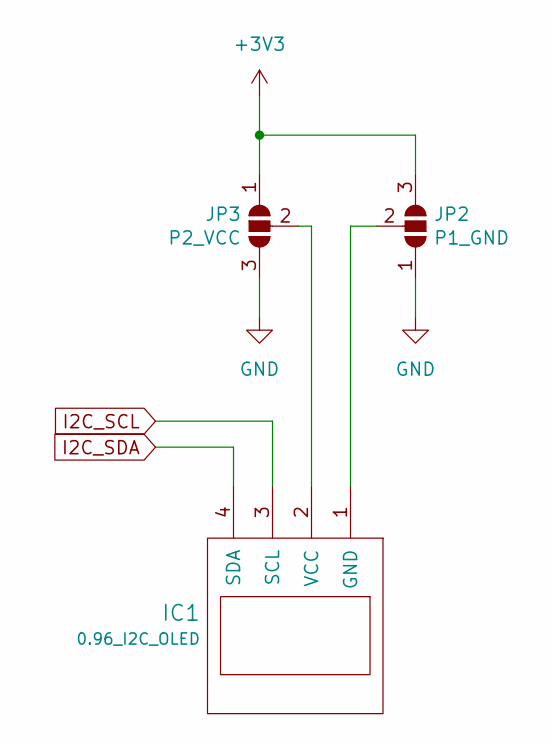
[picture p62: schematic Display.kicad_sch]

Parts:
IC1: 0.96_I2C_OLED; 0.96_I2C_OLED_NEW_Top
JP2: P1_GND; SolderJumper-3_P1.3mm_Open_Pad1.0x1.5mm
JP3: P2_VCC; SolderJumper-3_P1.3mm_Open_Pad1.0x1.5mm

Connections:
+3V3: JP2.3 (B), JP3.1 (A); also elsewhere on the board
GND: JP2.1 (A), JP3.3 (B); also elsewhere on the board
I2C_SCL: IC1.3 (SCL); also elsewhere on the board
I2C_SDA: IC1.4 (SDA); also elsewhere on the board
unnamed: IC1.1 (GND), JP2.2 (C)
unnamed: IC1.2 (VCC), JP3.2 (C)

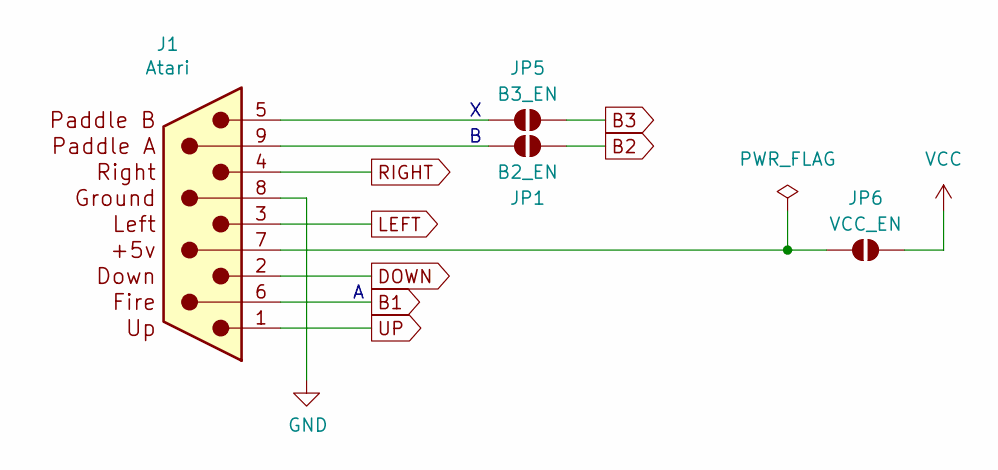
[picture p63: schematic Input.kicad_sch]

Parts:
J1: Atari; DSUB-9_Male_Horizontal_P2.77x2.84mm_EdgePinOffset7.70mm_Hou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
JP1: B2_EN; bridge
JP5: B3_EN; bridge
JP6: VCC_EN; bridge

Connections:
B1: J1.6; also elsewhere on the board
B2: JP1.2 (B); also elsewhere on the board
B3: JP5.2 (B); also elsewhere on the board
DOWN: J1.2; also elsewhere on the board
GND: J1.8 (GND); also elsewhere on the board
LEFT: J1.3; also elsewhere on the board
unnamed: J1.7 (VCC), JP6.1 (A)
unnamed: J1.9, JP1.1 (A)
unnamed: J1.5, JP5.1 (A)
RIGHT: J1.4; also elsewhere on the board
UP: J1.1; also elsewhere on the board
VCC: JP6.2 (B); also elsewhere on the board

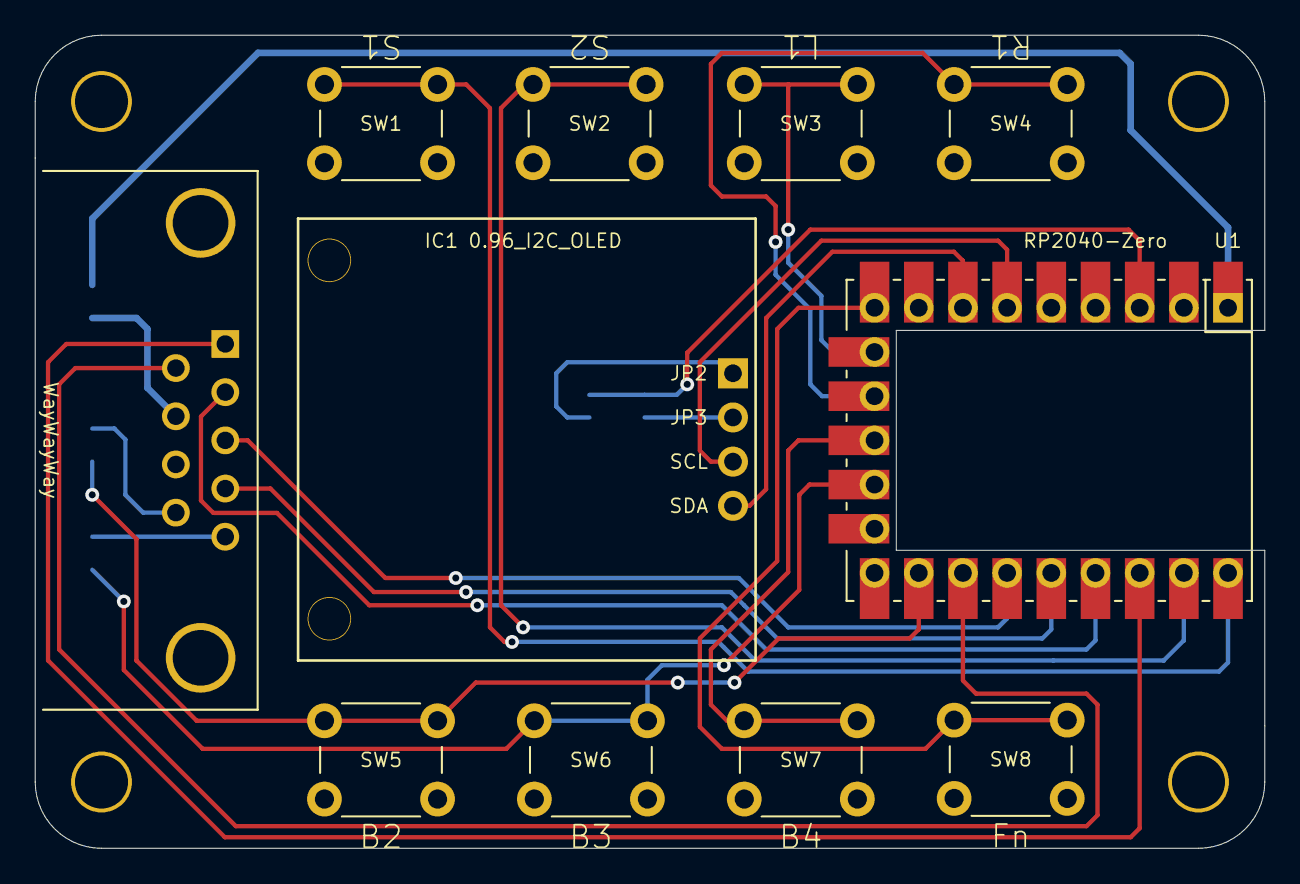
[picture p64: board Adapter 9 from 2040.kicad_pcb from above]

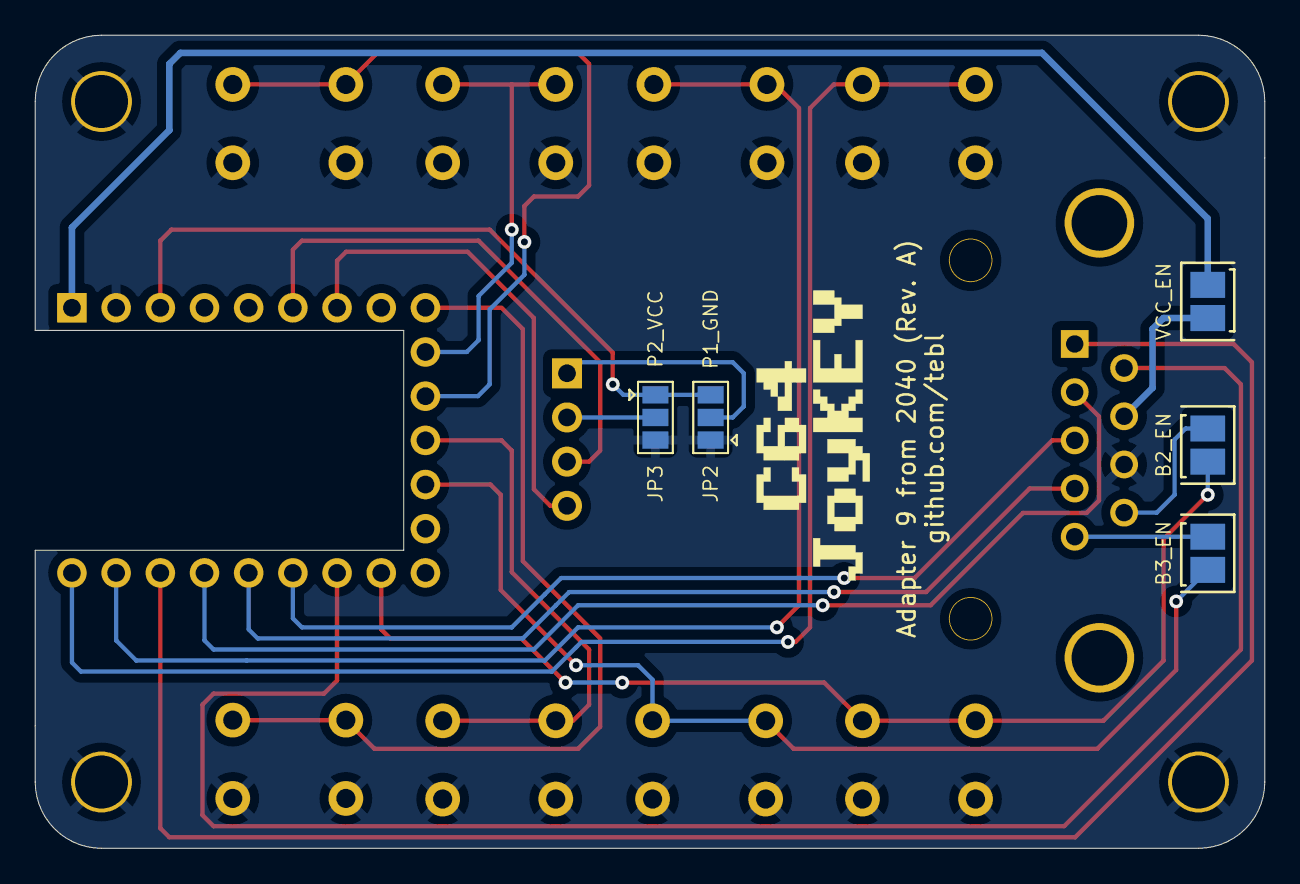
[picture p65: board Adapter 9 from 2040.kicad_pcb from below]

Board: 2 copper layers, 70.7 x 46.7 mm, 20 parts (5 on the bottom side), 23 nets.

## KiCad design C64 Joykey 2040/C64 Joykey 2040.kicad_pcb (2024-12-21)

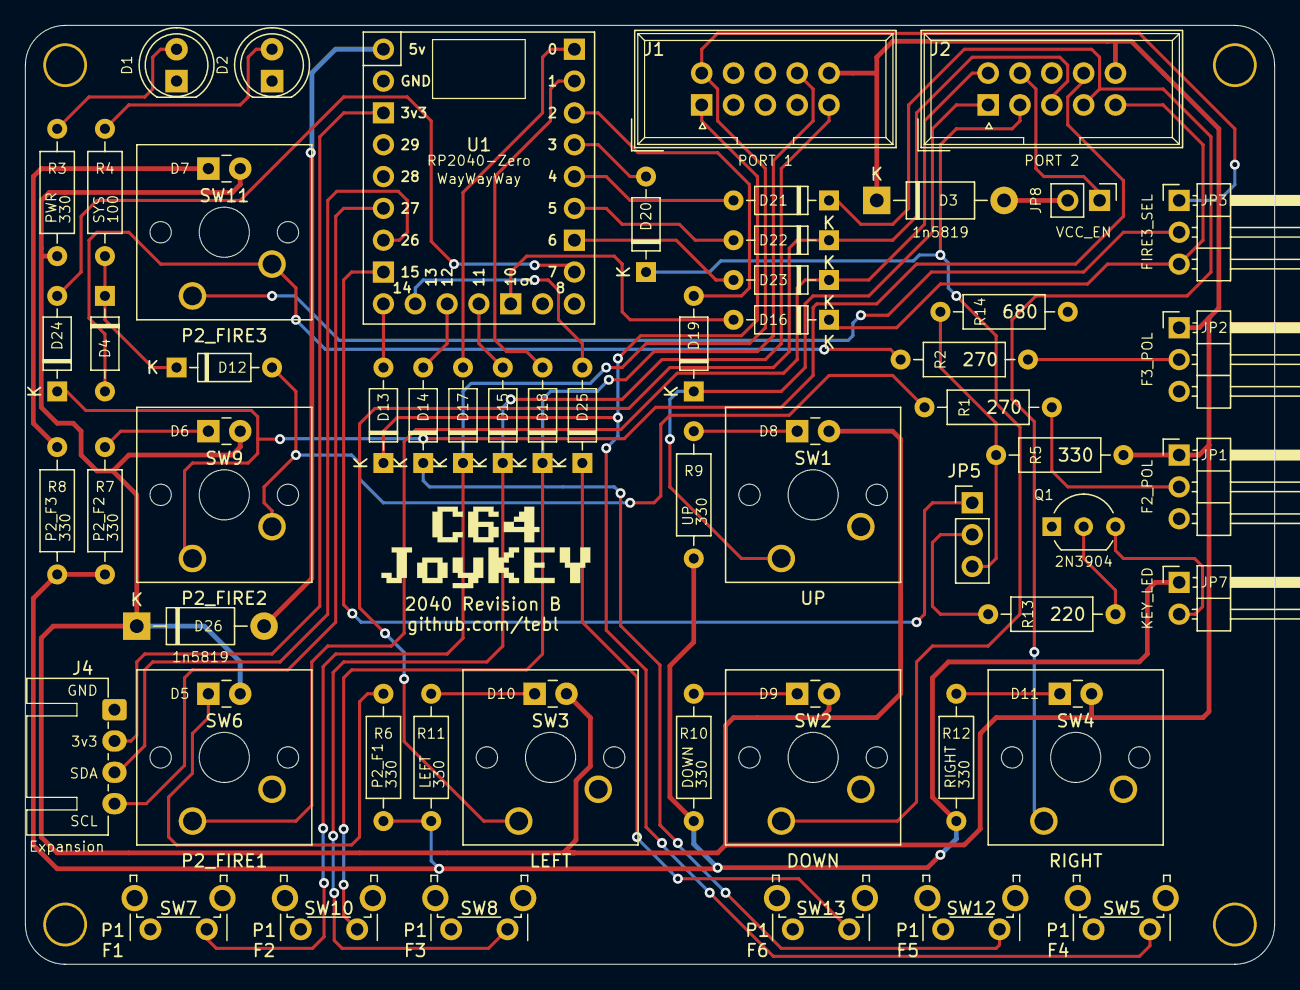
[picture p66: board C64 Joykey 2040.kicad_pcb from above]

Board: 2 copper layers, 99.7 x 74.9 mm, 68 parts (0 on the bottom side), 55 nets.

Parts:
D1: PWR; LED_D5.0mm
D2: POL; LED_D5.0mm
D3, D26: 1n5819; D_DO-41_SOD81_P10.16mm_Horizontal
D4, D12, D13, D14, D15, D16, D17, D18, D19, D20, D21, D22, D23, D24, D25: 1N4148; D_DO-35_SOD27_P7.62mm_Horizontal
D5, D6, D7, D8, D9, D10, D11: LED; LED_Rectangular_W3.0mm_H2.0mm
J1: Port_1; IDC_Joystick
J2: Port_2; IDC_Joystick
J4: Expansion; JST_XH_B4B-XH-A_1x04_P2.50mm_Right_Angle
JP1: F2_POL; PinHeader_1x03_P2.54mm_Horizontal
JP2: F3_POL; PinHeader_1x03_P2.54mm_Horizontal
JP3: FIRE3_SEL; PinHeader_1x03_P2.54mm_Horizontal
JP5: LED_PIN; PinHeader_1x03_P2.54mm_Vertical
JP7: KEY_LED; PinHeader_1x02_P2.54mm_Horizontal
JP8: VCC_EN; PinHeader_1x02_P2.54mm_Vertical
M1, M2, M3, M4: Mounting; M3_pin
Q1: 2N3904; TO-92_Inline_Wide
R1, R2: 270; R_Axial_DIN0207_L6.3mm_D2.5mm_P10.16mm_Horizontal
R3, R5, R6, R7, R8, R9, R10, R11, R12: 330; R_Axial_DIN0207_L6.3mm_D2.5mm_P10.16mm_Horizontal
R4: 100; R_Axial_DIN0207_L6.3mm_D2.5mm_P10.16mm_Horizontal
R13: 220; R_Axial_DIN0207_L6.3mm_D2.5mm_P10.16mm_Horizontal
R14: 680; R_Axial_DIN0207_L6.3mm_D2.5mm_P10.16mm_Horizontal
SW1: UP; SW_Cherry_MX_1.00u_PCB
SW2: DOWN; SW_Cherry_MX_1.00u_PCB
SW3: LEFT; SW_Cherry_MX_1.00u_PCB
SW4: RIGHT; SW_Cherry_MX_1.00u_PCB
SW5: P1_FIRE4; SW_Tactile_SPST_Angled_PTS645Vx31-2LFS
SW6: P2_FIRE1; SW_Cherry_MX_1.00u_PCB
SW7: P1_FIRE1; SW_Tactile_SPST_Angled_PTS645Vx31-2LFS
SW8: P1_FIRE3; SW_Tactile_SPST_Angled_PTS645Vx31-2LFS
SW9: P2_FIRE2; SW_Cherry_MX_1.00u_PCB
SW10: P1_FIRE2; SW_Tactile_SPST_Angled_PTS645Vx31-2LFS
SW11: P2_FIRE3; SW_Cherry_MX_1.00u_PCB
SW12: P1_FIRE5; SW_Tactile_SPST_Angled_PTS645Vx31-2LFS
SW13: P1_FIRE6; SW_Tactile_SPST_Angled_PTS645Vx31-2LFS
U1: RP2040-Zero; RP2040-Zero-THT

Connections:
+3V3: J4.2, U1.3 (3V3)
/A1: D13.2 (A), U1.9 (GPIO14)
/B1: D23.2 (A), U1.17 (GPIO6)
/B2: D24.2 (A), U1.16 (GPIO7)
/B3: D16.2 (A), U1.13 (GPIO10)
/B4: D15.2 (A), U1.12 (GPIO11)
/DOWN: D20.2 (A), U1.20 (GPIO3)
/L1: D25.2 (A), U1.10 (GPIO13)
/LEFT: D22.2 (A), U1.18 (GPIO5)
/R1: D14.2 (A), U1.11 (GPIO12)
/RIGHT: D21.2 (A), U1.19 (GPIO4)
/S1: D17.2 (A), U1.23 (GPIO0)
/S2: D18.2 (A), U1.22 (GPIO1)
/UP: D19.2 (A), U1.21 (GPIO2)
FIRE2_POL: D12.2 (A), R1.1, SW9.2
FIRE3_POL: D4.2 (A), R2.1, SW11.2
GND: D1.1 (K), D2.1 (K), J1.8, J2.8, J4.1, JP1.3 (B), JP2.3 (B), M1.1, M2.1, M3.1, M4.1, Q1.1 (E), R14.1, SW1.2, SW2.2, SW3.2, SW4.2, SW5.2, SW6.2, SW7.2, SW8.2, SW10.2, SW12.2, SW13.2, U1.2 (GND)
I2C_SCL: J4.4, U1.6 (GPIO27_ADC1)
I2C_SDA: J4.3, U1.7 (GPIO26_ADC0)
LED_EN: JP5.1 (A), U1.8 (GPIO15)
unnamed: D1.2 (A), R3.1
unnamed: D2.2 (A), R4.1
unnamed: D3.2 (A), JP8.2
unnamed: D5.1 (K), R6.1
unnamed: D6.1 (K), R7.1
unnamed: D7.1 (K), R8.1
unnamed: D8.1 (K), R9.1
unnamed: D9.1 (K), R10.1
unnamed: D10.1 (K), R11.1
unnamed: D11.1 (K), R12.1
unnamed: D4.1 (K), D12.1 (K), R4.2
unnamed: D26.2 (A), U1.1 (VBUS)
unnamed: J2.7, JP8.1
unnamed: JP1.2 (C), R1.2
unnamed: JP2.2 (C), R2.2
unnamed: JP3.2 (C), SW11.1
unnamed: JP5.3 (B), R5.1, R14.2
unnamed: JP5.2 (C), R13.2
unnamed: JP7.1 (A), R6.2, R7.2, R8.2, R9.2, R10.2, R11.2, R12.2
unnamed: JP7.2 (B), Q1.3 (C)
unnamed: Q1.2 (B), R13.1
P1_FIRE1: D17.1 (K), J1.6, JP3.1 (A), SW7.1
P1_FIRE2: D18.1 (K), J1.9, SW10.1
P1_FIRE3: D15.1 (K), J1.5, SW8.1
P1_FIRE4: D13.1 (K), J1.1, SW5.1
P1_FIRE5: D14.1 (K), SW12.1
P1_FIRE6: D25.1 (K), SW13.1
P2_DOWN: D20.1 (K), J2.2, SW2.1
P2_FIRE1: D23.1 (K), J2.6, SW6.1
P2_FIRE2: D24.1 (K), J2.9, SW9.1
P2_FIRE3: D16.1 (K), J2.5, JP3.3 (B)
P2_LEFT: D22.1 (K), J2.3, SW3.1
P2_RIGHT: D21.1 (K), J2.4, SW4.1
P2_UP: D19.1 (K), J2.1, SW1.1
VCC: D3.1 (K), D5.2 (A), D6.2 (A), D7.2 (A), D8.2 (A), D9.2 (A), D10.2 (A), D11.2 (A), D26.1 (K), J1.10 (EX_VCC), J2.10 (EX_VCC), JP1.1 (A), JP2.1 (A), R3.2, R5.2

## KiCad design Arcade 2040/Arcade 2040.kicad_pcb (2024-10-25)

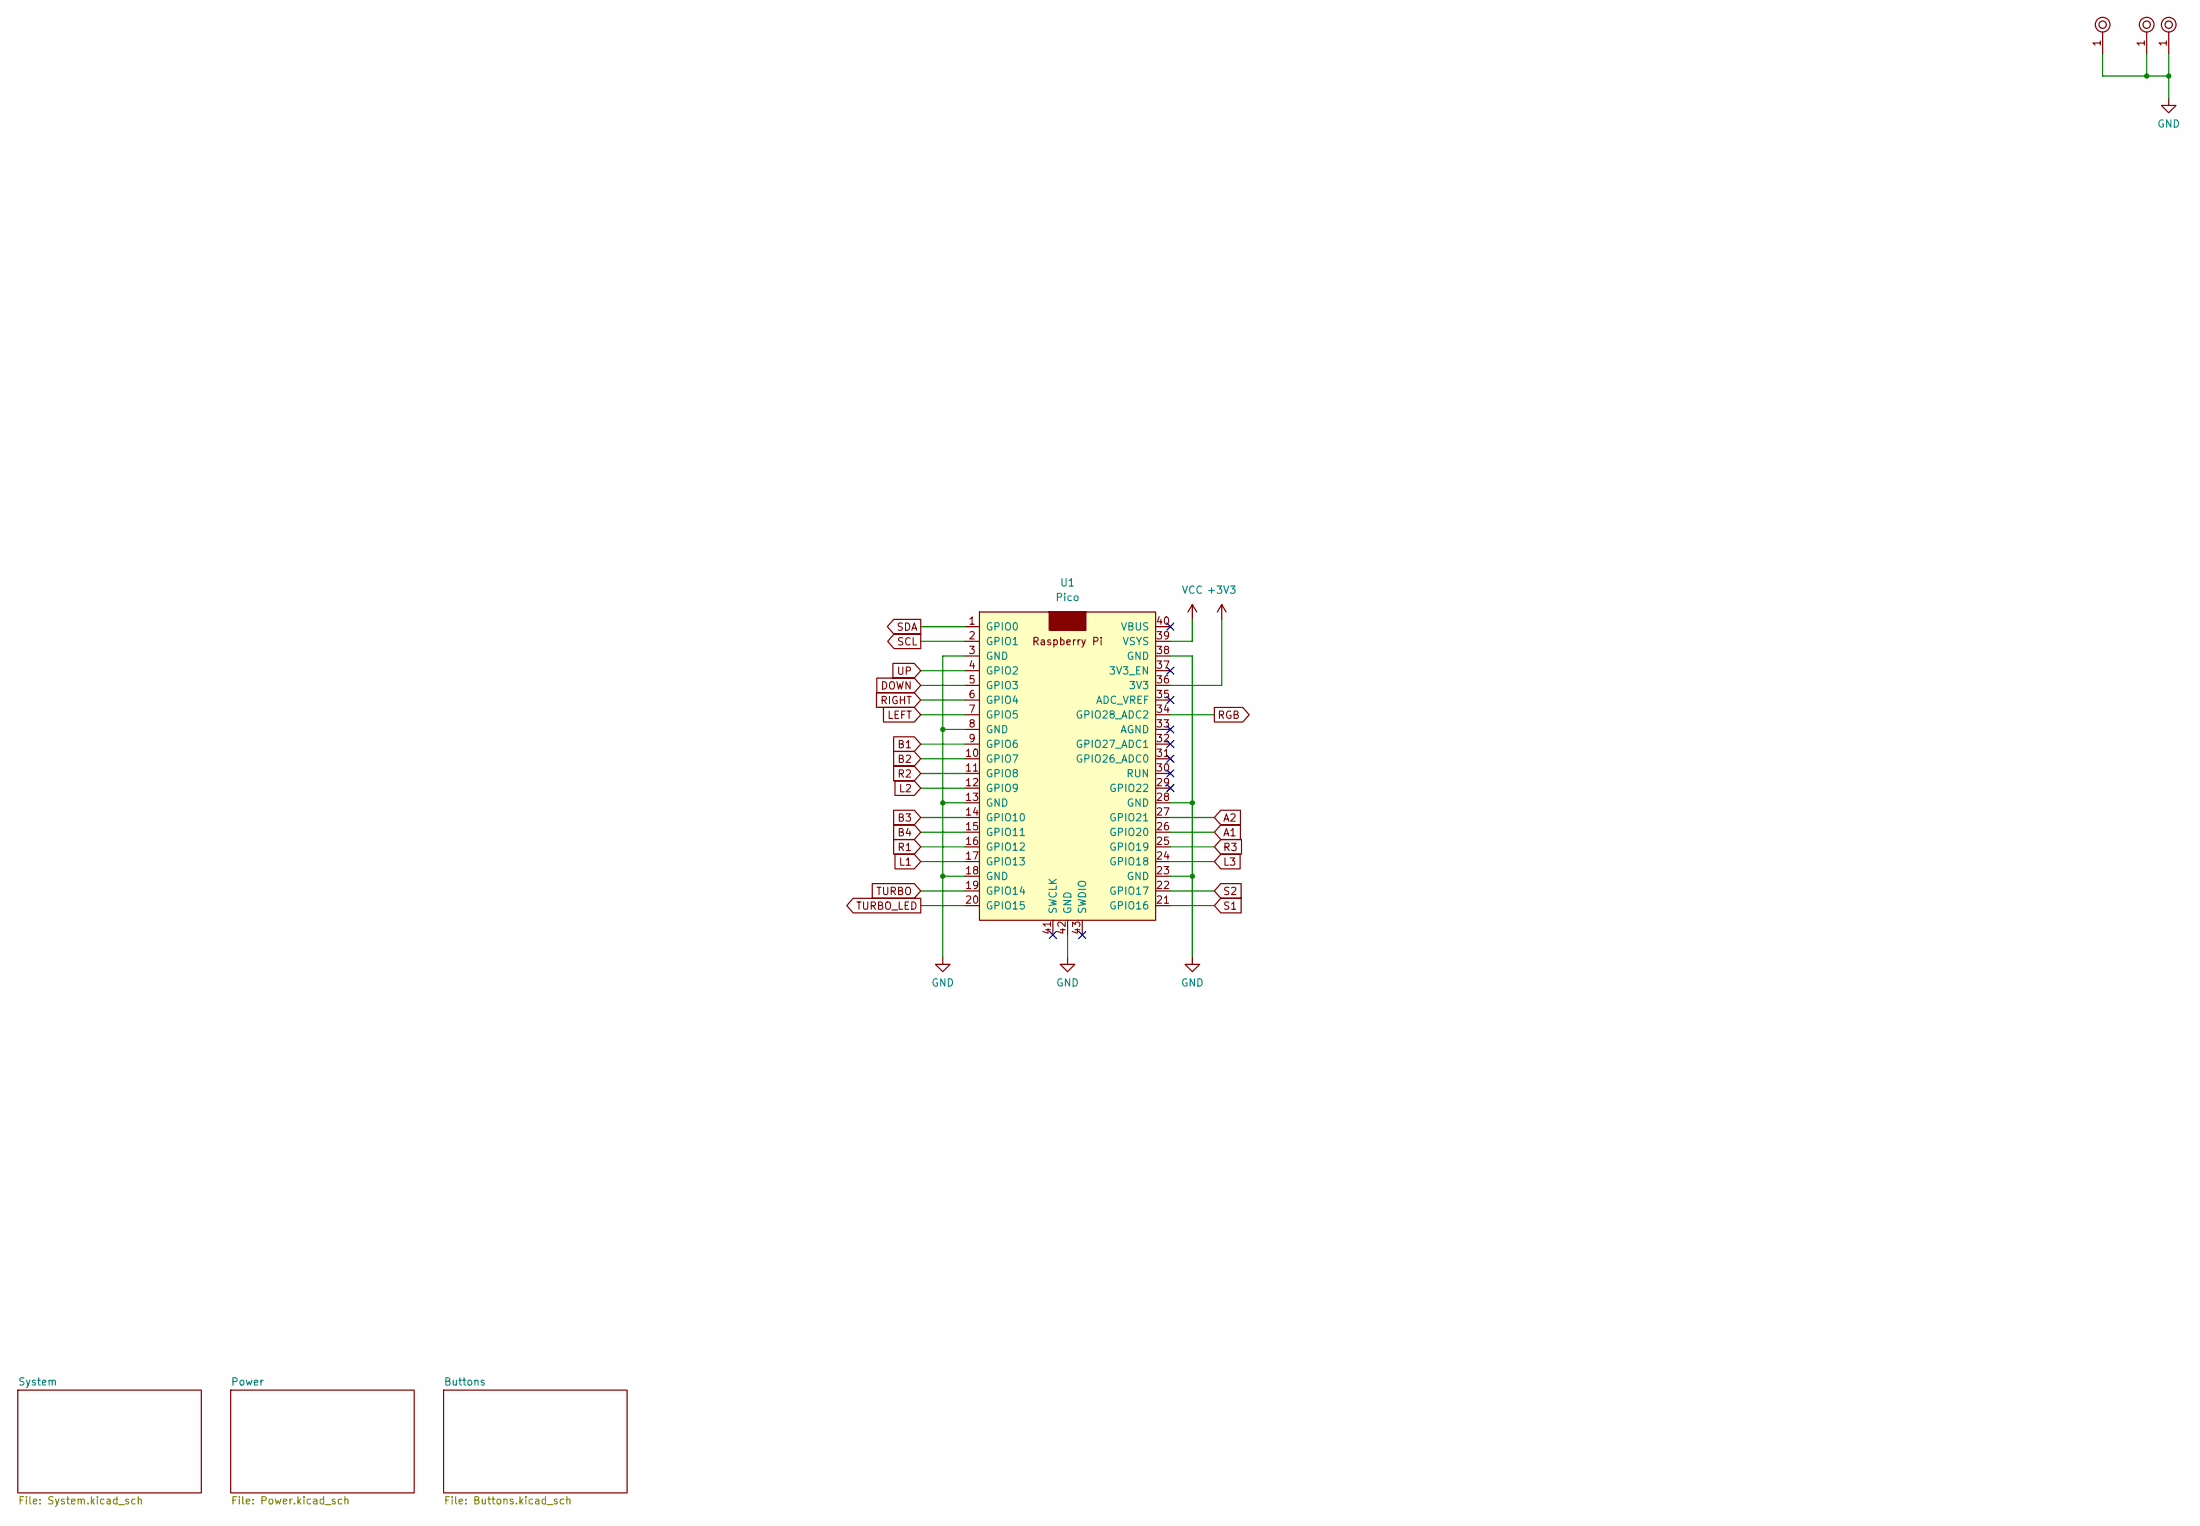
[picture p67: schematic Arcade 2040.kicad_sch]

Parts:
M1, M3, M4: Mounting; M3_pin
U1: Pico; RPi_Pico_SMD_TH_Clean

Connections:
+3V3: U1.36 (3V3); also elsewhere on the board
A1: U1.26 (GPIO20); also elsewhere on the board
A2: U1.27 (GPIO21); also elsewhere on the board
B1: U1.9 (GPIO6); also elsewhere on the board
B2: U1.10 (GPIO7); also elsewhere on the board
B3: U1.14 (GPIO10); also elsewhere on the board
B4: U1.15 (GPIO11); also elsewhere on the board
DOWN: U1.5 (GPIO3); also elsewhere on the board
GND: M1.1, M3.1, M4.1, U1.3 (GND), U1.8 (GND), U1.13 (GND), U1.18 (GND), U1.23 (GND), U1.28 (GND), U1.38 (GND), U1.42 (GND); also elsewhere on the board
L1: U1.17 (GPIO13); also elsewhere on the board
L2: U1.12 (GPIO9); also elsewhere on the board
L3: U1.24 (GPIO18); also elsewhere on the board
LEFT: U1.7 (GPIO5); also elsewhere on the board
R1: U1.16 (GPIO12); also elsewhere on the board
R2: U1.11 (GPIO8); also elsewhere on the board
R3: U1.25 (GPIO19); also elsewhere on the board
RGB: U1.34 (GPIO28_ADC2); also elsewhere on the board
RIGHT: U1.6 (GPIO4); also elsewhere on the board
S1: U1.21 (GPIO16); also elsewhere on the board
S2: U1.22 (GPIO17); also elsewhere on the board
SCL: U1.2 (GPIO1); also elsewhere on the board
SDA: U1.1 (GPIO0); also elsewhere on the board
TURBO: U1.19 (GPIO14); also elsewhere on the board
TURBO_LED: U1.20 (GPIO15); also elsewhere on the board
UP: U1.4 (GPIO2); also elsewhere on the board
VCC: U1.39 (VSYS); also elsewhere on the board

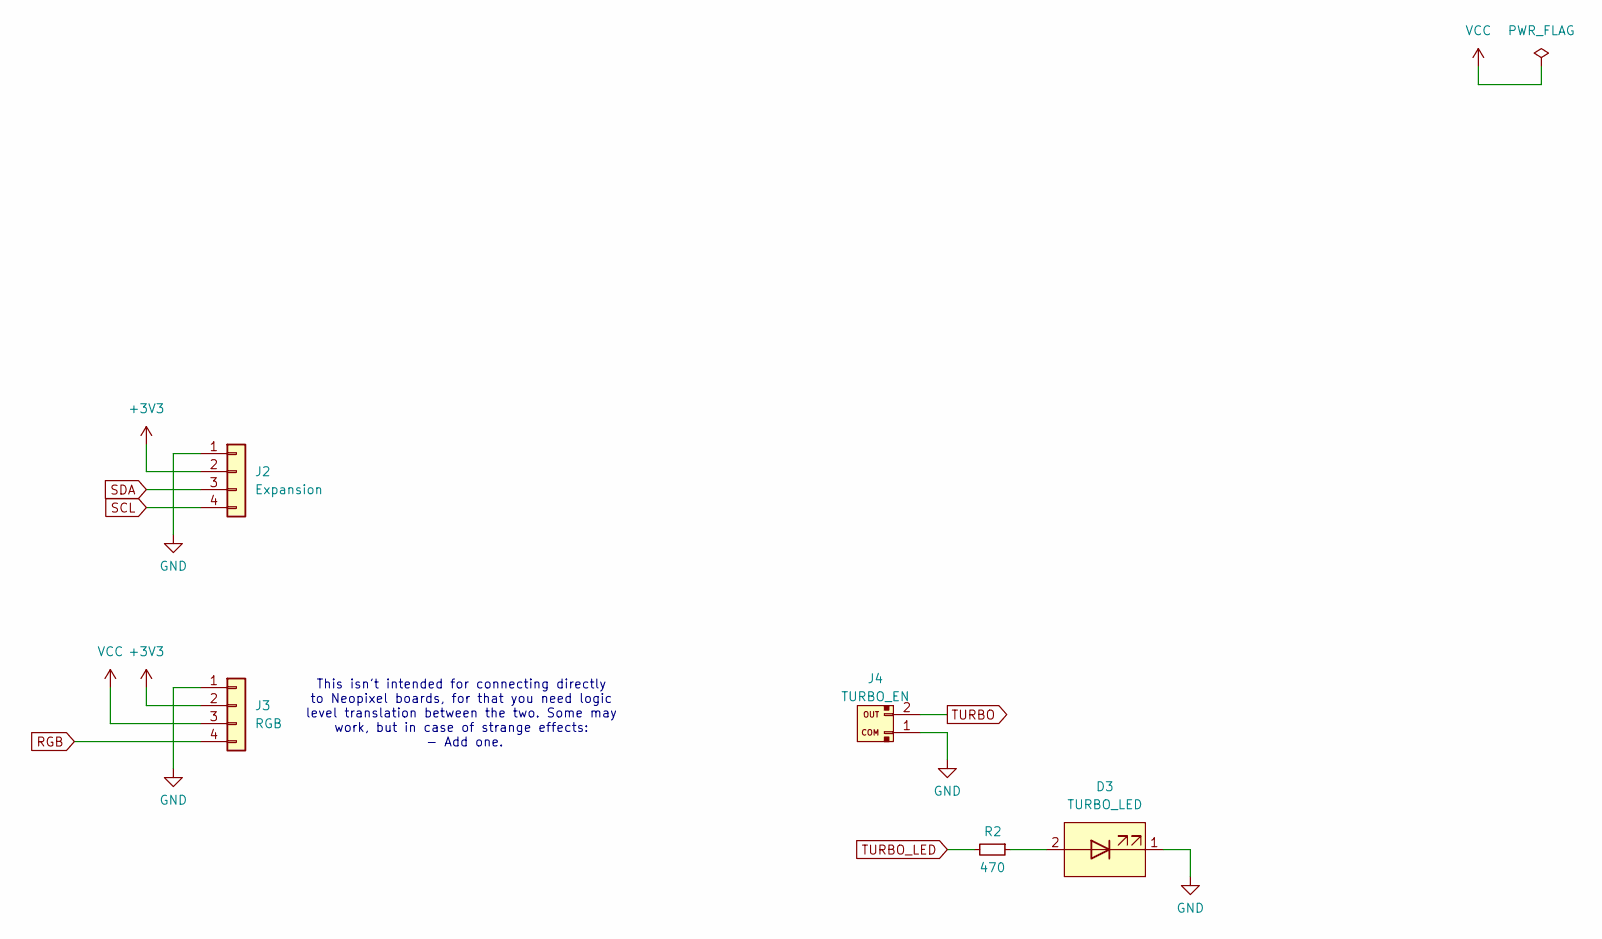
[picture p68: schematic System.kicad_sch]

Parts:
D3: TURBO_LED; JST_XH_B2B-XH-A_1x02_P2.50mm_Vertical
J2: Expansion; JST_XH_B4B-XH-A_1x04_P2.50mm_Vertical
J3: RGB; JST_XH_B4B-XH-A_1x04_P2.50mm_Vertical
J4: TURBO_EN; JST_XH_B2B-XH-A_1x02_P2.50mm_Vertical
R2: 470; R_Axial_DIN0207_L6.3mm_D2.5mm_P10.16mm_Horizontal

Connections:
+3V3: J2.2, J3.2; also elsewhere on the board
GND: D3.1 (K), J2.1, J3.1, J4.1; also elsewhere on the board
unnamed: D3.2 (A), R2.1
RGB: J3.4; also elsewhere on the board
SCL: J2.4; also elsewhere on the board
SDA: J2.3; also elsewhere on the board
TURBO: J4.2; also elsewhere on the board
TURBO_LED: R2.2; also elsewhere on the board
VCC: J3.3; also elsewhere on the board

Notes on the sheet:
This isn't intended for connecting directly to Neopixel boards, for that you need logic level translation between the two. Some may work, but in case of strange effects: - Add one.

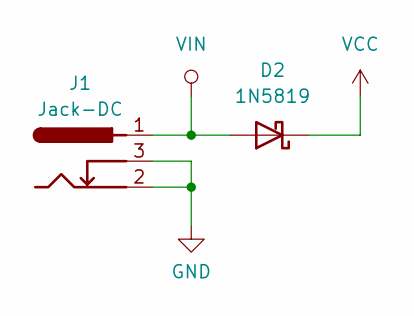
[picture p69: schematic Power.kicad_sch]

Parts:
D2: 1N5819; D_DO-41_SOD81_P10.16mm_Horizontal
J1: Jack-DC; BARREL_JACK

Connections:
GND: J1.2, J1.3; also elsewhere on the board
VCC: D2.1 (K); also elsewhere on the board
VIN: D2.2 (A), J1.1

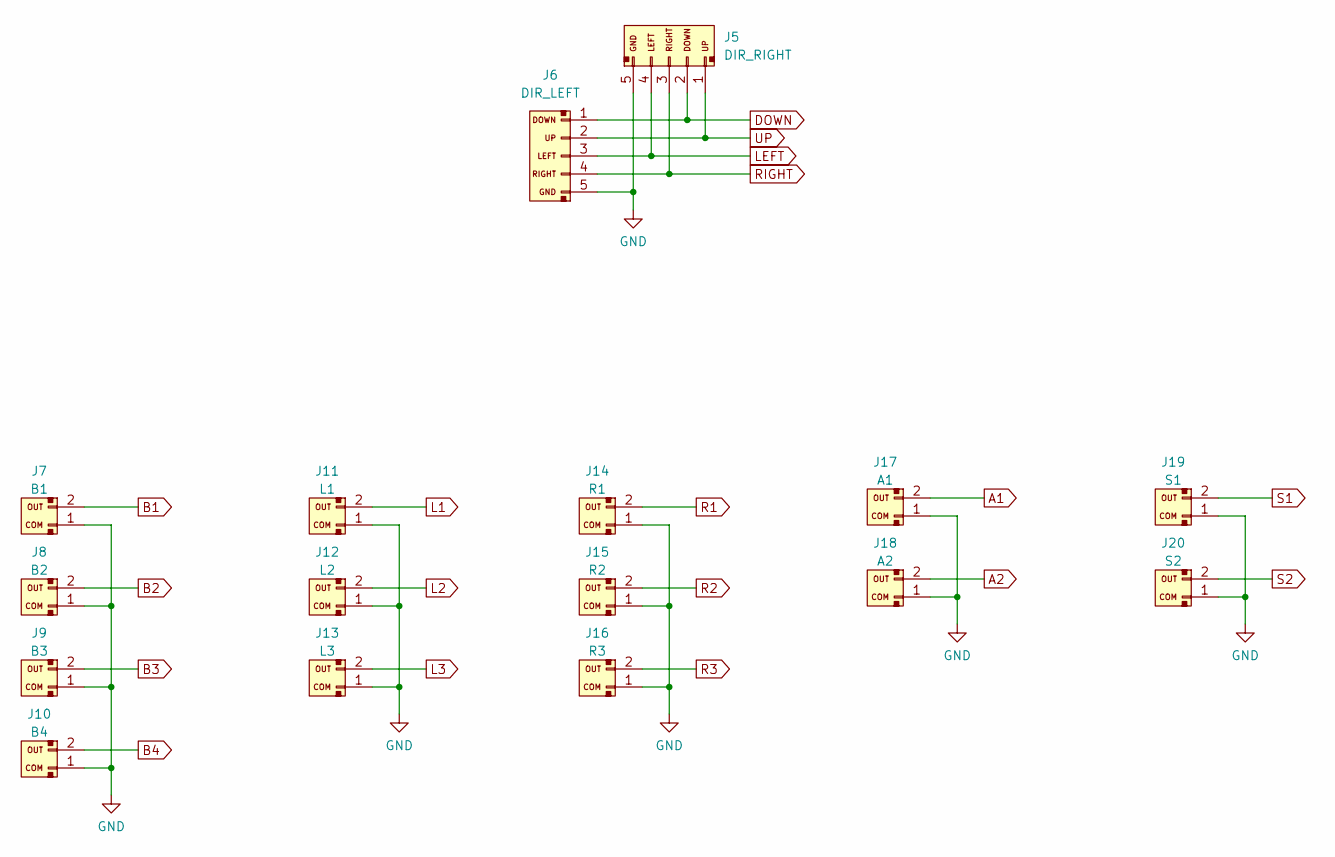
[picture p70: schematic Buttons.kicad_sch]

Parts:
J5: DIR_RIGHT; JST_XH_B5B-XH-A_1x05_P2.50mm_Vertical
J6: DIR_LEFT; JST_XH_B5B-XH-A_1x05_P2.50mm_Vertical
J7: B1; JST_XH_B2B-XH-A_1x02_P2.50mm_Vertical
J8: B2; JST_XH_B2B-XH-A_1x02_P2.50mm_Vertical
J9: B3; JST_XH_B2B-XH-A_1x02_P2.50mm_Vertical
J10: B4; JST_XH_B2B-XH-A_1x02_P2.50mm_Vertical
J11: L1; JST_XH_B2B-XH-A_1x02_P2.50mm_Vertical
J12: L2; JST_XH_B2B-XH-A_1x02_P2.50mm_Vertical
J13: L3; JST_XH_B2B-XH-A_1x02_P2.50mm_Vertical
J14: R1; JST_XH_B2B-XH-A_1x02_P2.50mm_Vertical
J15: R2; JST_XH_B2B-XH-A_1x02_P2.50mm_Vertical
J16: R3; JST_XH_B2B-XH-A_1x02_P2.50mm_Vertical
J17: A1; JST_XH_B2B-XH-A_1x02_P2.50mm_Vertical
J18: A2; JST_XH_B2B-XH-A_1x02_P2.50mm_Vertical
J19: S1; JST_XH_B2B-XH-A_1x02_P2.50mm_Vertical
J20: S2; JST_XH_B2B-XH-A_1x02_P2.50mm_Vertical

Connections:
A1: J17.2; also elsewhere on the board
A2: J18.2; also elsewhere on the board
B1: J7.2; also elsewhere on the board
B2: J8.2; also elsewhere on the board
B3: J9.2; also elsewhere on the board
B4: J10.2; also elsewhere on the board
DOWN: J5.2, J6.1; also elsewhere on the board
GND: J5.5, J6.5, J7.1, J8.1, J9.1, J10.1, J11.1, J12.1, J13.1, J14.1, J15.1, J16.1, J17.1, J18.1, J19.1, J20.1; also elsewhere on the board
L1: J11.2; also elsewhere on the board
L2: J12.2; also elsewhere on the board
L3: J13.2; also elsewhere on the board
LEFT: J5.4, J6.3; also elsewhere on the board
R1: J14.2; also elsewhere on the board
R2: J15.2; also elsewhere on the board
R3: J16.2; also elsewhere on the board
RIGHT: J5.3, J6.4; also elsewhere on the board
S1: J19.2; also elsewhere on the board
S2: J20.2; also elsewhere on the board
UP: J5.1, J6.2; also elsewhere on the board

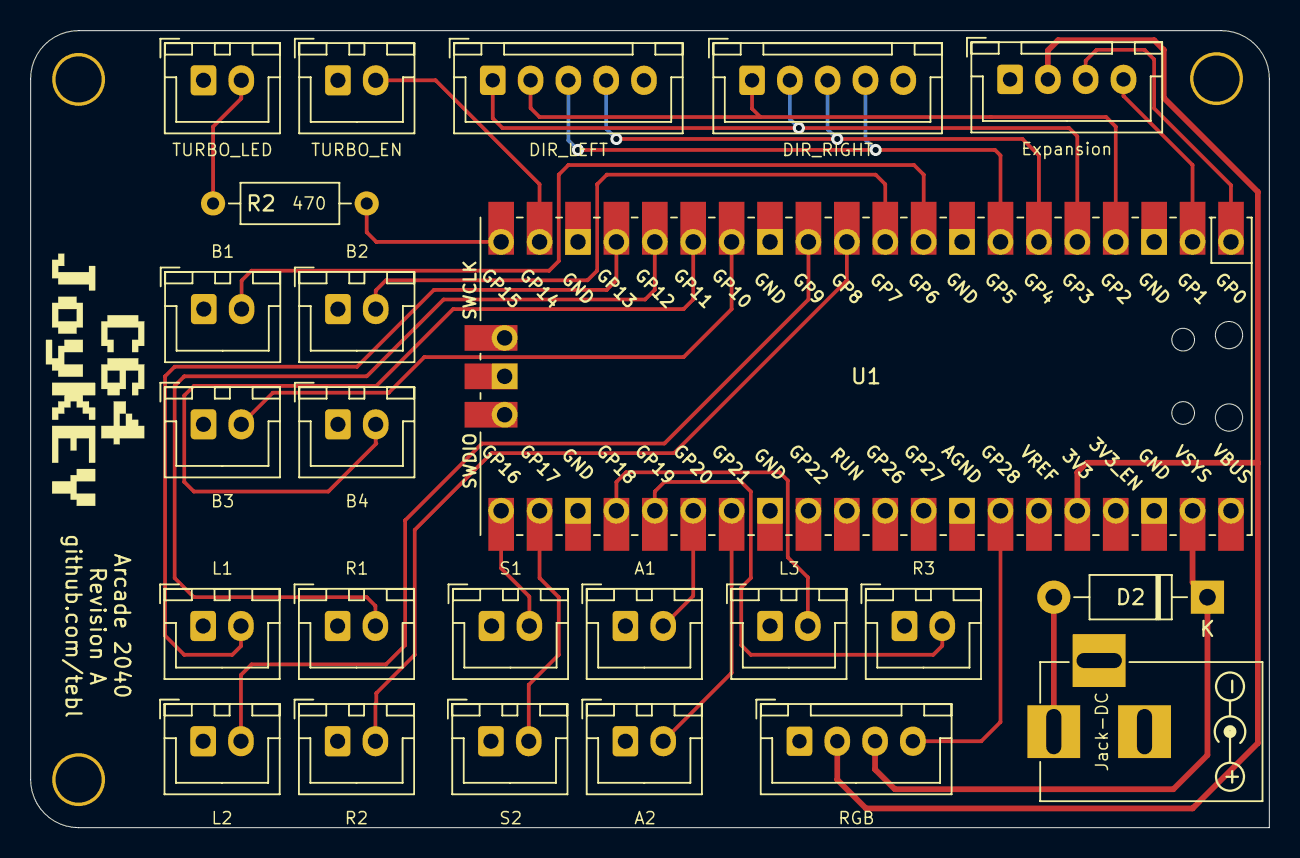
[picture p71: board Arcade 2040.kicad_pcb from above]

Board: 2 copper layers, 81.9 x 52.7 mm, 27 parts (0 on the bottom side), 28 nets.

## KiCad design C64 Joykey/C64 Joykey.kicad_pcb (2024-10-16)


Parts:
A1: Arduino_Pro_Micro
D1: PWR; LED_D5.0mm
D2: SYS; LED_D5.0mm
D3: 1n5819; D_DO-41_SOD81_P10.16mm_Horizontal
D4: 1n4148; D_DO-35_SOD27_P7.62mm_Horizontal
D5, D6, D7, D8, D9, D10, D11: LED; LED_Rectangular_W3.0mm_H2.0mm
J1: Port_1; IDC_Joystick
J2: Port_2; IDC_Joystick
JP1: F2_POL; PinHeader_1x03_P2.54mm_Horizontal
JP2: F3_POL; PinHeader_1x03_P2.54mm_Horizontal
JP3: FIRE3_SEL; PinHeader_1x03_P2.54mm_Horizontal
JP4: DEFAULT_FW; bridge
JP5: LED_SEL; select
JP6: DEFAULT_FW; bridge_r
JP7: KEY_LED; PinHeader_1x02_P2.54mm_Horizontal
JP8: VCC_EN; PinHeader_1x02_P2.54mm_Vertical
JP9: ARD_EN; PinHeader_1x02_P2.54mm_Vertical
M1, M2, M3, M4: Mounting; M3_pin
Q1: 2N3904; 2N3904_TO-92_Horizontal_FlatSideDown
R1, R2: 270; R_Axial_DIN0207_L6.3mm_D2.5mm_P10.16mm_Horizontal
R3, R4, R6, R7, R8, R9, R10, R11, R12: 330; R_Axial_DIN0207_L6.3mm_D2.5mm_P10.16mm_Horizontal
R5, R14, R15, R16, R17, R18, R19, R20, R21: 10k; R_Axial_DIN0207_L6.3mm_D2.5mm_P10.16mm_Horizontal
R13: 1k; R_Axial_DIN0207_L6.3mm_D2.5mm_P10.16mm_Horizontal
SW1: P2_FIRE1; SW_Cherry_MX_1.00u_PCB
SW2: P2_FIRE2; SW_Cherry_MX_1.00u_PCB
SW3: P2_FIRE3; SW_Cherry_MX_1.00u_PCB
SW4: UP; SW_Cherry_MX_1.00u_PCB
SW5: DOWN; SW_Cherry_MX_1.00u_PCB
SW6: LEFT; SW_Cherry_MX_1.00u_PCB
SW7: RIGHT; SW_Cherry_MX_1.00u_PCB
SW8: RESET; SW_PUSH_6mm
SW9: P1_FIRE1; SW_Tactile_SPST_Angled_PTS645Vx31-2LFS
SW10: P1_FIRE2; SW_Tactile_SPST_Angled_PTS645Vx31-2LFS
SW11: P1_FIRE3; SW_Tactile_SPST_Angled_PTS645Vx31-2LFS
SW12: P1_FIRE4; SW_Tactile_SPST_Angled_PTS645Vx31-2LFS

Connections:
/FIRE1_IN: A1.5 (D2), R17.1
/FIRE1_OUT: A1.8 (D5), D4.1 (K)
/FIRE2_IN: A1.6 (D3), R16.1
/FIRE2_OUT: A1.10 (D7), R14.1
/FIRE3_IN: A1.7 (D4), R15.1
/PWR: A1.12 (D9), JP5.3 (B)
/SYS: A1.13 (D10), R4.2
/UNDERGLOW: A1.9 (D6), R13.2
FIRE2_POL: A1.20 (D21), R1.1, SW2.2, SW10.2
FIRE3_POL: A1.19 (D20), R2.1, SW3.2, SW11.2
GND: A1.3 (GND), A1.4 (GND), A1.23 (GND), D1.1 (K), D2.1 (K), J1.8, J2.8, JP1.3 (B), JP2.3 (B), M1.1, M2.1, M3.1, M4.1, Q1.1 (E), SW1.2, SW4.2, SW5.2, SW6.2, SW7.2, SW8.2, SW9.2, SW12.2
unnamed: A1.15 (D14), R21.2
unnamed: A1.16 (D15), R20.2
unnamed: A1.17 (D18), R19.2
unnamed: A1.18 (D19), R18.2
unnamed: A1.22 (RST), SW8.1
unnamed: A1.21 (VCC), JP9.1
unnamed: D1.2 (A), R3.1
unnamed: D2.2 (A), R4.1
unnamed: D3.2 (A), JP8.2
unnamed: D4.2 (A), R5.1
unnamed: D5.1 (K), R6.1
unnamed: D6.1 (K), R7.1
unnamed: D7.1 (K), R8.1
unnamed: D8.1 (K), R9.1
unnamed: D9.1 (K), R10.1
unnamed: D10.1 (K), R11.1
unnamed: D11.1 (K), R12.1
unnamed: J2.7, JP8.1
unnamed: JP1.2 (C), R1.2
unnamed: JP2.2 (C), R2.2
unnamed: JP3.2 (C), R15.2, SW3.1
unnamed: JP4.1, R17.2, SW1.1
unnamed: JP5.2 (C), R3.2
unnamed: JP6.1, R16.2, SW2.1
unnamed: JP7.1, R6.2, R7.2, R8.2, R9.2, R10.2, R11.2, R12.2
unnamed: Q1.2 (B), R13.1
unnamed: JP7.2, Q1.3 (C)
P1_FIRE1: J1.6, JP3.1 (A), SW9.1
P1_FIRE2: J1.9, SW10.1
P1_FIRE3: J1.5, SW11.1
P1_FIRE4: J1.1, SW12.1
P2_DOWN: J2.2, R20.1, SW5.1
P2_FIRE1: J2.6, JP4.2, R5.2
P2_FIRE2: J2.9, JP6.2, R14.2
P2_FIRE3: J2.5, JP3.3 (B)
P2_LEFT: J2.3, R21.1, SW6.1
P2_RIGHT: J2.4, R19.1, SW7.1
P2_UP: J2.1, R18.1, SW4.1
VCC: D3.1 (K), D5.2 (A), D6.2 (A), D7.2 (A), D8.2 (A), D9.2 (A), D10.2 (A), D11.2 (A), J1.10 (EX_VCC), J2.10 (EX_VCC), JP1.1 (A), JP2.1 (A), JP5.1 (A), JP9.2

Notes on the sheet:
As is common, but definitely not always, on the Commodore 64, port 2 is the main controller port. Port 1 is simply used for additional fire buttons, at the moment it does not include direction signals (this is by design). Pay particular attention to the polarity settings for the switches, these nee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
JP3 (FIRE3 output select): 1-2 C64 FIRE1 (port 1) N/C Other system Read documentation for details if not C64.
JP2 (FIRE3 polarity): 1-2 C64 (POTY) N/C Other system WARNING: Read documentation for details, especially if not a C64.
OUTPUT:
WASD-style keypad for use with vintage computers, can also be used as a simple USB keyboard with Arduino Pro Micro installed. Note that selecting the wrong polarity may not be a good thing depending on which system you're connecting it to (not installing a jumper here may be the safe choice).
Underglow LEDs:
There will be an alternate Arduino firmware where FIRE2/FIRE3 controls various forms of autofire (for single-button systems). For the default FW or units without an Arduino Pro Micro installed, JP4/JP6 must be linked.
DIRECTIONS:
FIRE 2:
JP1 (FIRE2 polarity): 1-2 C64 (POTX) N/C Other system WARNING: Read documentation for details, especially if not a C64.
Linking 1-2 will light PWR LED permanently, 2-3 allows Arduino to take control of it instead.
These components adds the underglow LEDs to the key switches. Footprints should match 2x3x4mm LEDs. Standard 3mm should also work with Gateron switches.
FIRE 3:
FIRE 1:


Board: 2 copper layers, 99.7 x 74.9 mm, 61 parts (0 on the bottom side), 50 nets.

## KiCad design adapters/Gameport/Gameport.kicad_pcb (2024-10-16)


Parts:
C1: 100nF; C_Disc_D4.7mm_W2.5mm_P5.00mm
J1: Port 1; IDC_Joystick
J2: Port 2; IDC_Joystick
J3: Gameport; Gameport_IDC
JP1: VCC_EN; PinHeader_1x02_P2.54mm_Vertical
M1, M2, M3, M4: Mounting; M3_pin
Q1, Q2: 2N3906; TO-92_Inline_Wide
R1, R5, R6, R8: 10k; R_Axial_DIN0207_L6.3mm_D2.5mm_P10.16mm_Horizontal
R2, R3, R4, R7, R9, R10: 47k; R_Axial_DIN0207_L6.3mm_D2.5mm_P10.16mm_Horizontal
U1: 4066; DIP-14_W7.62mm_Socket_LongPads

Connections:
GND: C1.2, J1.8, J2.8, J3.4 (GND), J3.5 (GND), R2.1, R3.1, U1.7 (VSS)
JK_DOWN: J2.2, R6.1, U1.6
JK_FIRE1: J2.6, J3.2 (VCC)
JK_FIRE2: J2.9, J3.7 (BTN2)
JK_FIRE3: J2.5, J3.10 (BTN3)
JK_FIRE4: J1.6, J3.14 (BTN4)
JK_LEFT: J2.3, R8.1, U1.5
JK_RIGHT: J2.4, R1.1, U1.13
JK_UP: J2.1, R5.1, U1.12
unnamed: J2.7, JP1.2
unnamed: Q1.2 (B), R2.2, U1.8
unnamed: Q1.3 (C), R4.2, R9.1
unnamed: Q2.2 (B), R3.2, U1.2
unnamed: Q2.3 (C), R7.2, R10.1
PC_X: J3.3 (A1), R10.2, U1.4
PC_Y: J3.6 (A2), R9.2, U1.10
VCC: C1.1, J3.1 (VCC), JP1.1, Q1.1 (E), Q2.1 (E), R1.2, R4.1, R5.2, R6.2, R7.1, R8.2, U1.1, U1.3, U1.9, U1.11, U1.14 (VDD)


Board: 2 copper layers, 58.4 x 43.8 mm, 22 parts (0 on the bottom side), 17 nets.

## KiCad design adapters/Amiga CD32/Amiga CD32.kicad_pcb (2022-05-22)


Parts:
C1, C2: 100nF; C_Disc_D4.7mm_W2.5mm_P5.00mm
C3: 47uF; CP_Radial_D5.0mm_P2.00mm
C4, C5: 220pF; C_Disc_D4.7mm_W2.5mm_P5.00mm
J1: Port 1; IDC_Joystick
J2: Port 2; IDC_Joystick
J3: Amiga CD32; IDC_Joystick
JP1: VCC_EN; bridge_r
L1: L; L_Axial_L6.6mm_D2.7mm_P10.16mm_Horizontal_Vishay_IM-2
M1, M2, M3, M4: Mounting; M3_pin
R1, R3, R4, R11, R14: 10k; R_Axial_DIN0207_L6.3mm_D2.5mm_P10.16mm_Horizontal
R2, R5, R6, R10: 10k; R_Axial_DIN0207_L6.3mm_D2.5mm_P7.62mm_Horizontal
R9: 2k2; R_Axial_DIN0207_L6.3mm_D2.5mm_P7.62mm_Horizontal
R12: 1k; R_Axial_DIN0207_L6.3mm_D2.5mm_P7.62mm_Horizontal
R13: 100; R_Axial_DIN0207_L6.3mm_D2.5mm_P7.62mm_Horizontal
SW1: PLAY; SW_PUSH_6mm
U1: 74LS125; DIP-14_W7.62mm_Socket_LongPads
U2: 74LS165; DIP-16_W7.62mm_Socket_LongPads

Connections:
CD32_BLU: J2.9, R14.2, U2.6 (D7)
CD32_FF: J1.5, R5.2, U2.14 (D3)
CD32_GRN: J2.5, R2.2, U2.3 (D4)
CD32_PLAY: J1.1, R6.2, SW1.2, U2.12 (D1)
CD32_RED: J2.6, R1.2, U1.12, U2.5 (D6)
CD32_REW: J1.9, R4.2, U2.13 (D2)
CD32_YEL: J1.6, R3.2, U2.4 (D5)
DOWN: J2.2, J3.2
FIRE1: J3.6, R10.1, U1.11, U2.2 (CP)
FIRE2: C5.1, J3.9, L1.1
FIRE3: J3.5, U1.1
GND: C1.2, C2.2, C3.2, C4.1, C5.2, J1.8, J2.8, J3.8, R9.2, SW1.1, U1.5, U1.7 (GND), U1.10, U2.8 (GND), U2.15 (~CE)
LEFT: J2.3, J3.3
unnamed: C4.2, R11.1, U1.6, U2.1 (~PL)
unnamed: J2.7, JP1.1 (A)
unnamed: L1.2, U1.8
unnamed: R9.1, U1.3, U1.4, U1.13
unnamed: R12.2, U2.11 (D0)
unnamed: R13.1, U2.10 (DS)
unnamed: U1.9, U2.9 (Q7)
RIGHT: J2.4, J3.4
UP: J2.1, J3.1
VCC: C1.1, C2.1, C3.1, J3.7, JP1.2 (B), R1.1, R2.1, R3.1, R4.1, R5.1, R6.1, R10.2, R11.2, R12.1, R13.2, R14.1, U1.2, U1.14 (VCC), U2.16 (VCC)


Board: 2 copper layers, 58.4 x 38.1 mm, 29 parts (0 on the bottom side), 23 nets.

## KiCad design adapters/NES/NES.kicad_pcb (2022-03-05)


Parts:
C1: 100nF; C_Disc_D4.7mm_W2.5mm_P5.00mm
J1: Port 1; IDC_Joystick
J2: Port 2; IDC_Joystick
J3: NES_Gamepad; NES_Output
JP1: VCC_EN; PinHeader_1x02_P2.54mm_Vertical
M1, M2, M3, M4: Mounting; M3_pin
R1, R2, R3, R4, R5, R6, R7, R8: 1k; R_Axial_DIN0207_L6.3mm_D2.5mm_P10.16mm_Horizontal
SW1: START; SW_PUSH_6mm
U1: CD4021; DIP-16_W7.62mm_Socket_LongPads

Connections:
/A: J2.9, R1.2, U1.1 (P8)
/B: J2.6, R2.2, U1.15 (P7)
/DOWN: J2.2, R6.2, U1.5 (P3)
/LEFT: J2.3, R7.2, U1.6 (P2)
/RIGHT: J2.4, R8.2, U1.7 (P1)
/SELECT: J1.6, R3.2, U1.14 (P6)
/START: J1.9, R4.2, SW1.2, U1.13 (P5)
/UP: J2.1, R5.2, U1.4
CLK: J3.2 (CLK), U1.10 (CLK)
DATA: J3.4 (DATA), U1.3 (Q8)
GND: C1.2, J1.8, J2.8, J3.1 (GND), SW1.1, U1.8 (GND), U1.11 (DS)
LATCH: J3.3 (LATCH), U1.9 (PL)
unnamed: J2.7, JP1.1
VCC: C1.1, J3.5 (VCC), JP1.2, R1.1, R2.1, R3.1, R4.1, R5.1, R6.1, R7.1, R8.1, U1.16 (VCC)


Board: 2 copper layers, 58.4 x 38.1 mm, 19 parts (0 on the bottom side), 14 nets.

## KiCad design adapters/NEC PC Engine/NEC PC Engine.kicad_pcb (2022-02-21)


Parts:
C1: 100nF; C_Disc_D4.7mm_W2.5mm_P5.00mm
C3: 10uF; CP_Radial_D4.0mm_P2.00mm
J1: Port 1; IDC_Joystick
J2: Port 2; IDC_Joystick
J3: PC Engine; NEC_Output
JP1: VCC_EN; PinHeader_1x02_P2.54mm_Vertical
M1, M2, M3, M4: Mounting; M3_pin
R1, R2, R3, R4, R5, R6, R7, R8, R9, R10: 47k; R_Axial_DIN0207_L6.3mm_D2.5mm_P10.16mm_Horizontal
R11, R12, R13, R14: 330; R_Axial_DIN0207_L6.3mm_D2.5mm_P10.16mm_Horizontal
U1: 74HCT157; DIP-16_W7.62mm_Socket_LongPads

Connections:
/DOWN: J2.2, R6.2, U1.10 (I1c)
/I: J2.9, R1.2, U1.2 (I0a)
/II: J2.6, R3.2, U1.5 (I0b)
/LEFT: J2.3, R8.2, U1.13 (I1d)
/RIGHT: J2.4, R4.2, U1.6 (I1b)
/RUN: J1.9, R7.2, U1.14 (I0d)
/SELECT: J1.6, R5.2, U1.11 (I0c)
/UP: J2.1, R2.2, U1.3 (I1a)
CLR: J3.7 (CLR), R10.2, U1.15 (E)
D0: J3.2 (D0), R11.2
D1: J3.3 (D1), R12.2
D2: J3.4 (D2), R13.2
D3: J3.5 (D3), R14.2
GND: C1.2, C3.2, J1.8, J2.8, J3.8 (GND), U1.8 (GND)
unnamed: J2.7, JP1.1
unnamed: R11.1, U1.4 (Za)
unnamed: R12.1, U1.7 (Zb)
unnamed: R13.1, U1.9 (Zc)
unnamed: R14.1, U1.12 (Zd)
SEL: J3.6 (SEL), R9.2, U1.1 (S)
VCC: C1.1, C3.1, J3.1 (VCC), JP1.2, R1.1, R2.1, R3.1, R4.1, R5.1, R6.1, R7.1, R8.1, R9.1, R10.1, U1.16 (VCC)


Board: 2 copper layers, 58.4 x 38.1 mm, 25 parts (0 on the bottom side), 21 nets.

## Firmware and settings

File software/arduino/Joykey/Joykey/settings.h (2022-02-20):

#include "constants.h"

/*
 * Settings
 */
#define LED_PWR_MAX 56                // Maximum brightness
#define LED_SYS_MAX 64                // Maximum brightness
#define LED_SHUTOFF 5000              // Time after boot when fade starts
#define LED_FADE_SPEED 200            // Delay between LED fade steps
#define LED_STEP 8                    // Change per step when fading
#define LED_FLASH_DELAY 100           // Delay between blink steps
#define BOOT_MODE_THRESHOLD 1000      // Time needed before alternate mode
#define USB_DEBOUNCE_DELAY 10         // Debounce delay for keys
#define LED_DISABLE_RX_TX             // Disable RX/TX LEDs on Arduino

/* Controls underglow effects, if available - setting LED_UNDERGLOW_MAX to 0
 * will disable it entirely. Effects are not available in the default mode
 * (for vintage systems), you should only activate one of them.
 */
#define LED_UNDERGLOW_MAX 128         // Maximum brightness
#define LED_UNDERGLOW_STEP 8          // Change per step when fading.
#define LED_UNDERGLOW_FADE_SPEED 200  // Num ms. between fade out steps
#define LED_UNDERGLOW_MIN 1           // Uncomment to keep underglow above MIN.
#define UNDERGLOW_EFFECT_BOOST        // Underglow fades in on activity.
// #define UNDERGLOW_EFFECT_FLASH     // Underglow goes to max then fades without activity.

/* This controls the underglow LEDs when in the default mode, this should only
 * be enabled if you know that you can safely power that much from the joystick
 * port of whatever you've connected the C64 JoyKEY to.
 */
// #define DEFAULT_UNDERGLOW 16       // Uncomment to enable, also set brightness

/* Specify KEY_MODE_JOYSTICK to have the alternate mode identify the
 * device as a joystick, alternatively you can use KEY_MODE_USB to have it
 * function as a weird keyboard (see KEY_MAP_DEFAULT below for keymap used). 
 */
#define USB_ALTERNATE_MODE KEY_MODE_JOYSTICK
// #define USB_ALTERNATE_MODE KEY_MODE_USB

/* Uncomment this line to force the alternate mode, this is useful if you only
 * want to use the C64 JoyKEY over USB and do not want to connect it to a
 * vintage system of any kind. The mode used is the one specified by 
 * USB_ALTERNATE_MODE above. FORCE_DEFAULT forces the default mode instead.
 */
//#define FORCE_DEFAULT
// #define USB_FORCE_ALTERNATE

/* Specify the key mapping to use when setting USB_ALTERNATE_MODE to
 * KEY_MODE_USB (used as a USB keyboard). Valid options are:
 *   KEYMAP_WASD_KEYS         - WASD
 *   KEYMAP_CURSOR_GAME       - Cursor keys
 *   KEYMAP_CURSOR_EDITOR     - Same as above except FIRE1/2/3 is copy/paste/cut
 *   KEYMAP_PLATFORMIO        - Fire keys compile, upload and open serial 
 *                              terminal (PlatformIO).
 *   KEYMAP_FUNCTIONS         - Function keys F13-F19 (useful when module used
 *                              as a macro keyboard such as a streamdeck).
 *   KEYCODES_VICE            - VICE numpad joystick, joystick-mode recommended
 *                              used instead.
 * 
 * If you do not like any of these, feel free to modify one of these within
 * the file constants.h - or create your own.
 */
#define KEYMAP_DEFAULT KEYMAP_CURSOR_GAME

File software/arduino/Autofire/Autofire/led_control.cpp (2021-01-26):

#include <Arduino.h>
#include "constants.h"
#include "settings.h"

#define LED_INDEX_PWR 0
#define LED_INDEX_SYS 1
#define LED_INDEX_UNDERGLOW 2

int current_pwr = LED_PWR_MAX;
int current_sys = LED_SYS_MAX;
int current_underglow = LED_UNDERGLOW_MAX;

int led_values[] = { LED_PWR_MAX, LED_SYS_MAX, LED_UNDERGLOW_MAX };
const int led_max[] = { LED_PWR_MAX, LED_SYS_MAX, LED_UNDERGLOW_MAX };
const int led_pins[] = { PIN_PWR, PIN_SYS, PIN_UNDERGLOW }; 

/* Updates the LED as indicated by the index. Values will be forced within
 * 0 and max_value, making things a bit easier in other code - note that a
 * maximum value of 0 will always take precedence (can never be turned on). 
 */
void set_led(const int index, int value) {
  if (value < LED_OFF) value = LED_OFF;
  if (value > led_max[index]) value = led_max[index];

  led_values[index] = value;
  analogWrite(led_pins[index], value);
}

/* Set LED state, this just toggles between full value and completely off. */
void set_led(const int index, const bool value) {
  set_led(index, (value ? led_max[index] : LED_OFF));
}

/* Fades out the LED indicated using index. */
void fade_led(const int index, const int step_size) {
  if (led_values[index] == LED_OFF) return;
  set_led(index, led_values[index] - step_size);
}

/* Same as above, except we ensure we stay above the specified lower limit. All
 * of this is ignored if the LED has been permanently set to be in the off state.
 */
void fade_led(const int index, const int minimum, const int step_size) {
  if (led_values[index] == LED_OFF && led_max[index] == LED_OFF) return;
  int value = led_values[index] - step_size;
  if (value < minimum) value = minimum;
  set_led(index, value);
}

/* The opposite of fade_led. */
void boost_led(const int index, const int step_size) {
  set_led(index, led_values[index] + step_size);
}

/* Check if a specific LED has been turned on */
bool is_led_on(const int index) {
  return led_values[index] > LED_OFF;
}

/* Delay used when spacing out user feedback. Note that this is a blocking
 * function, so it'll probably not be much use when we want to respond to
 * keypresses in due time. */
void flash_delay() { delay(LED_FLASH_DELAY); }

void flash_led(const int index, const int num_flashes) {
  for (int i = 0; i < num_flashes; i++) {
  if (i > 0) flash_delay();
      set_led(index, true);
      flash_delay();
      set_led(index, false);
  }
}

bool is_pwr_on() { return is_led_on(LED_INDEX_PWR); }
void set_pwr(int value) { set_led(LED_INDEX_PWR, value); }
void set_pwr(bool value) { set_led(LED_INDEX_PWR, value); }
void fade_pwr() { fade_led(LED_INDEX_PWR, LED_STEP); }
void flash_pwr(int num_flashes) { flash_led(LED_INDEX_PWR, num_flashes); }
bool is_sys_on() { return is_led_on(LED_INDEX_SYS); }
void set_sys(int value) { set_led(LED_INDEX_SYS, value); }
void set_sys(bool value) { set_led(LED_INDEX_SYS, value); }
void fade_sys() { fade_led(LED_INDEX_SYS, LED_STEP); }
void flash_sys(int num_flashes) { flash_led(LED_INDEX_SYS, num_flashes); }
void set_underglow(int value) { set_led(LED_INDEX_UNDERGLOW, value); }
void set_underglow(bool value) { set_led(LED_INDEX_UNDERGLOW, value); }
void fade_underglow() { fade_led(LED_INDEX_UNDERGLOW, LED_UNDERGLOW_STEP); }
void fade_underglow(const int minimum) { fade_led(LED_INDEX_UNDERGLOW, minimum); };
void boost_underglow() { boost_led(LED_INDEX_UNDERGLOW, LED_UNDERGLOW_STEP); }
void flash_underglow(int num_flashes) { flash_led(LED_INDEX_UNDERGLOW, num_flashes); }

void init_led() {
  pinMode(PIN_PWR, OUTPUT);
  set_pwr(true);

  pinMode(PIN_SYS, OUTPUT);
  set_sys(LED_OFF);

  pinMode(PIN_UNDERGLOW, OUTPUT);
  set_underglow(LED_OFF);
}

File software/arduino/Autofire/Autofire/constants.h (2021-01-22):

#ifndef _CONSTANTS_H
#define _CONSTANTS_H

/* 
 * Pin definitions 
 */
#define PIN_FIRE1 2
#define PIN_FIRE1_OUT 5
#define PIN_FIRE2 3
#define PIN_FIRE2_POL 21
#define PIN_FIRE3 4
#define PIN_FIRE3_POL 20
#define PIN_LEFT 14
#define PIN_RIGHT 18
#define PIN_UP 19
#define PIN_DOWN 15
#define PIN_UNDERGLOW 6
#define PIN_PWR 9
#define PIN_SYS 10

/* 
 * Definitions
 */
#define LED_OFF 0

#define KEY_MODE_DEFAULT 0
#define KEY_MODE_AUTOFIRE 1

#define JOYKEY_UP 0
#define JOYKEY_DOWN 1
#define JOYKEY_LEFT 2
#define JOYKEY_RIGHT 3
#define JOYKEY_FIRE1 4
#define JOYKEY_FIRE2 5
#define JOYKEY_FIRE3 6
#define NUM_KEYS 7

#define KEY_STATE_NEUTRAL 0
#define KEY_STATE_WAIT_RELEASE 1

const int KEY_PINS[NUM_KEYS] = { PIN_UP, PIN_DOWN, PIN_LEFT, PIN_RIGHT, PIN_FIRE1, PIN_FIRE2, PIN_FIRE3 };
#endif

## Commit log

2020-11-20 Schematic added
    [C64 Joykey.kicad_pcb, C64 Joykey.sch]
2020-11-22 Assign footprints
    [C64 Joykey.sch]
2020-11-22 Rough placement
    [C64 Joykey.kicad_pcb, C64 Joykey.sch]
2020-11-24 Routed tracks
    [C64 Joykey.kicad_pcb, C64 Joykey.sch]
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2020-12-03 Tweaked PCB layout
    [C64 Joykey Faceplate-B_Cu.gbl, C64 Joykey Faceplate-B_Mask.gbs, C64 Joykey Faceplate-B_Paste.gbp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]
2020-12-04 Added polarity notes
    [C64 Joykey-B_Cu.gbl, C64 Joykey-B_Mask.gbs, C64 Joykey-B_Paste.gbp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]
2020-12-05 Added second DEFAULT_FW so all buttons can be independent
    [C64 Joykey-B_Cu.gbl, C64 Joykey-B_Mask.gbs, C64 Joykey-B_Paste.gbp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]
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2020-12-06 Added protection diodes
    [C64 Joykey-B_Cu.gbl, C64 Joykey-B_Mask.gbs, C64 Joykey-B_Paste.gbp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]
2020-12-07 Swapped jumper layout (need new pictures)
    [C64 Joykey-B_Cu.gbl, C64 Joykey-B_Mask.gbs, C64 Joykey-B_Paste.gbp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]
2020-12-07 Added series resistor to output pin
    [C64 Joykey-B_Cu.gbl, C64 Joykey-B_Mask.gbs, C64 Joykey-B_Paste.gbp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]
2020-12-10 SMS cable schematic
    [C64 Joykey.sch, SMS Adapter.kicad_pcb, SMS Adapter.sch]
2020-12-10 Moved JP3
    [C64 Joykey-B_Cu.gbl, C64 Joykey-B_Mask.gbs, C64 Joykey-B_Paste.gbp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]
2020-12-10 Added SMS jumper settings to schematic
    [SMS Adapter.sch]
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2020-12-13 Added untested Atari 7800 adapter
    [A7800 Adapter-B_Cu.gbl, A7800 Adapter-B_Mask.gbs, A7800 Adapter-B_Paste.gbp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]
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2020-12-16 Increased LED_SEL pin separation to avoid shorts
    [C64 Joykey-B_Cu.gbl, C64 Joykey-B_Mask.gbs, C64 Joykey-B_Paste.gbp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]
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2021-01-08 Updated gerbers for version C
    [C64 Joykey-B_Cu.gbl, C64 Joykey-B_Mask.gbs, C64 Joykey-B_Paste.gbp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]
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2021-01-08 Moved adapters into separate folder, added sinclair.
    [A7800 Adapter-B_Cu.gbl, A7800 Adapter-B_Mask.gbs, A7800 Adapter-B_Paste.gbp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]
2021-01-08 Moved faceplates into separate folder.
    [C64 Joykey Faceplate A1.kicad_pcb, C64 Joykey Faceplate A1.sch, C64 Joykey Faceplate B1.kicad_pcb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]
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2021-01-19 Added straight 2x5 IDC to DB9 adapter
    [IDC to DB9-B_Cu.gbl, IDC to DB9-B_Mask.gbs, IDC to DB9-B_Paste.gbp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]
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2021-01-19 Flipped MX-switches
    [C64 Joykey-B_Cu.gbl, C64 Joykey-B_Mask.gbs, C64 Joykey-B_Paste.gbp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]
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2021-01-22 Added VCC_EN to IDC -> DB9 adapter
    [IDC to DB9-B_Cu.gbl, IDC to DB9-B_Mask.gbs, IDC to DB9-B_Paste.gbp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]
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2021-01-26 Tweaked faceplate B1 cutouts to include LED
    [C64 Joykey Faceplate B1-B_Cu.gbl, C64 Joykey Faceplate B1-B_Mask.gbs, C64 Joykey Faceplate B1-B_Paste.gbp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]
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2021-01-29 Arcade board layout done
    [C64 Arcade-B_Cu.gbl, C64 Arcade-B_Mask.gbs, C64 Arcade-B_Paste.gbp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]
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2021-02-03 Added C64 splash screen to A1
    [C64 Joykey Faceplate A1-B_Cu.gbl, C64 Joykey Faceplate A1-B_Mask.gbs, C64 Joykey Faceplate A1-B_Paste.gbp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]
2021-02-04 Added UP_EN for direction
    [C64 Arcade-B_Cu.gbl, C64 Arcade-B_Mask.gbs, C64 Arcade-B_Paste.gbp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]
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2021-02-08 Fixed Sinclair adapter
    [C64 Joykey.sch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]
2021-02-12 Allow arduino sketch to stay in default mode (skipping magic key detection)
    [process_keys.cpp, settings.h]
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2021-02-12 Added 10k resistors to isolate unpowered Arduino
    [C64 Joykey-B_Cu.gbl, C64 Joykey-B_Mask.gbs, C64 Joykey-B_Paste.gbp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]
2021-02-13 Play around with graphics
    [C64 Joykey Faceplate B1-B_Cu.gbl, C64 Joykey Faceplate B1-B_Mask.gbs, C64 Joykey Faceplate B1-B_Paste.gbp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]
2021-02-19 Added male side to sinclair adapter
    [Sinclair-B_Cu.gbl, Sinclair-B_Mask.gbs, Sinclair-B_Paste.gbp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]
2021-02-20 Fixed Arcade pinout and added isolation for Arduino (need new layout)
    [C64 Arcade.kicad_pcb, C64 Arcade.sch]
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2021-02-26 autofire had cycle lengths swapped
    [key_mode_autofire.cpp]
2021-02-26 Sega Mega Drive adapter, untested and incomplete
    [Sega Mega Drive.kicad_pcb, Sega Mega Drive.sch]
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2021-03-09 Tweaked faceplates to allow more leeway on LEDs
    [C64 Arcade.kicad_pcb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]
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2021-03-20 Added Sega Mega Drive adapter details
    [Sega Mega Drive.sch]
2021-03-20 Changed Sinclair adapter description
    [Sinclair.sch]
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2022-01-27 Add discrete P1 switches
    [C64 Joykey.sch]
2022-01-28 Route new tracks and export gerbers
    [C64 Joykey-B_Cu.gbl, C64 Joykey-B_Mask.gbs, C64 Joykey-B_Paste.gbp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]
2022-02-20 MSX adapter gerber export
    [MSX-B_Cu.gbl, MSX-B_Mask.gbs, MSX-B_Paste.gbp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]
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2022-02-21 Untested NEC PC Engine adapter
    [NEC PC Engine-B_Cu.gbl, NEC PC Engine-B_Mask.gbs, NEC PC Engine-B_Paste.gbp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]
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2022-04-27 Add missing CD32 button
    [C64 Joykey-B_Cu.gbl, C64 Joykey-B_Mask.gbs, C64 Joykey-B_Paste.gbp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]
2022-04-27 Add one more button to arcade board
    [C64 Arcade-B_Cu.gbl, C64 Arcade-B_Mask.gbs, C64 Arcade-B_Paste.gbp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]
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2023-01-26 Change recommended diode type to 1n5819 for lower voltage drop
    [C64 Joykey-B_Cu.gbl, C64 Joykey-B_Mask.gbs, C64 Joykey-B_Paste.gbp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]
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2023-02-21 Fixed pin linked to VCC
    [Gameport-B_Cu.gbl, Gameport-B_Mask.gbs, Gameport-B_Paste.gbp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]
2023-02-21 Trying out different circuit
    [Gameport-B_Cu.gbl, Gameport-B_Mask.gbs, Gameport-B_Paste.gbp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]
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2024-10-16 Gameport adapter that doesn't work
    [Gameport-B_Cu.gbl, Gameport-B_Mask.gbs, Gameport-B_Paste.gbp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]
2024-10-16 Attempt update to KiCAD8
    [C64 Joykey-B_Cu.gbl, C64 Joykey-B_Mask.gbs, C64 Joykey-B_Paste.gbp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]
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2024-10-25 Arcade 2040, and some cleanup
    [Amiga CD32-B_Cu.gbl, Amiga CD32-B_Mask.gbs, Amiga CD32-B_SilkS.gbo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]
2024-11-06 Add diode for power from USB
    [C64 Joykey 2040.kicad_pcb, C64 Joykey 2040.kicad_sch]
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2024-11-09 Try adding underglow to GPIO15
    [C64 Joykey 2040.kicad_pcb, C64 Joykey 2040.kicad_sch, Underglow.kicad_sch]
2024-11-22 Build tweaks to include LED labels
    [C64 Joykey 2040.kicad_pcb]
2024-11-27 Slight build tweaks for clarity
    [C64 Joykey 2040.kicad_pcb, C64 Joykey 2040.kicad_sch]
2024-11-27 Wrong schematic page size
    [C64 Joykey 2040.kicad_sch]
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2024-12-21 Change expansion header to JST XH, but in a right-angle variant
    [C64 Joykey 2040.kicad_pcb, C64 Joykey 2040.kicad_sch]
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2024-12-31 Adapter 9 from 2040, first draft
    [Adapter 9 FaceplateB.kicad_pcb, Adapter 9 FaceplateB.kicad_sch, Adapter 9 FaceplateB.sch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]
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2025-01-03 PCBway order number placeholder
    [Adapter 9 from 2040.kicad_pcb]
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

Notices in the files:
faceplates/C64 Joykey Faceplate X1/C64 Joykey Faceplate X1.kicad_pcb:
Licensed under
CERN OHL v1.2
